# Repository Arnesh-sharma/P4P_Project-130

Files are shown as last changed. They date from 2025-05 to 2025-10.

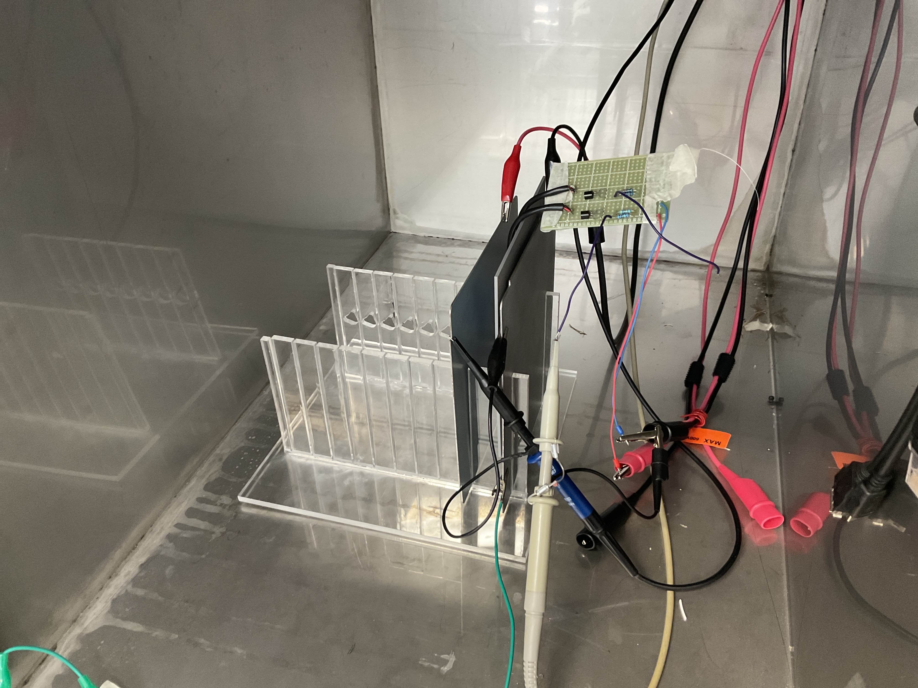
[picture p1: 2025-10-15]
Testing Data/For Report/FETs/FET_Vero.jpg

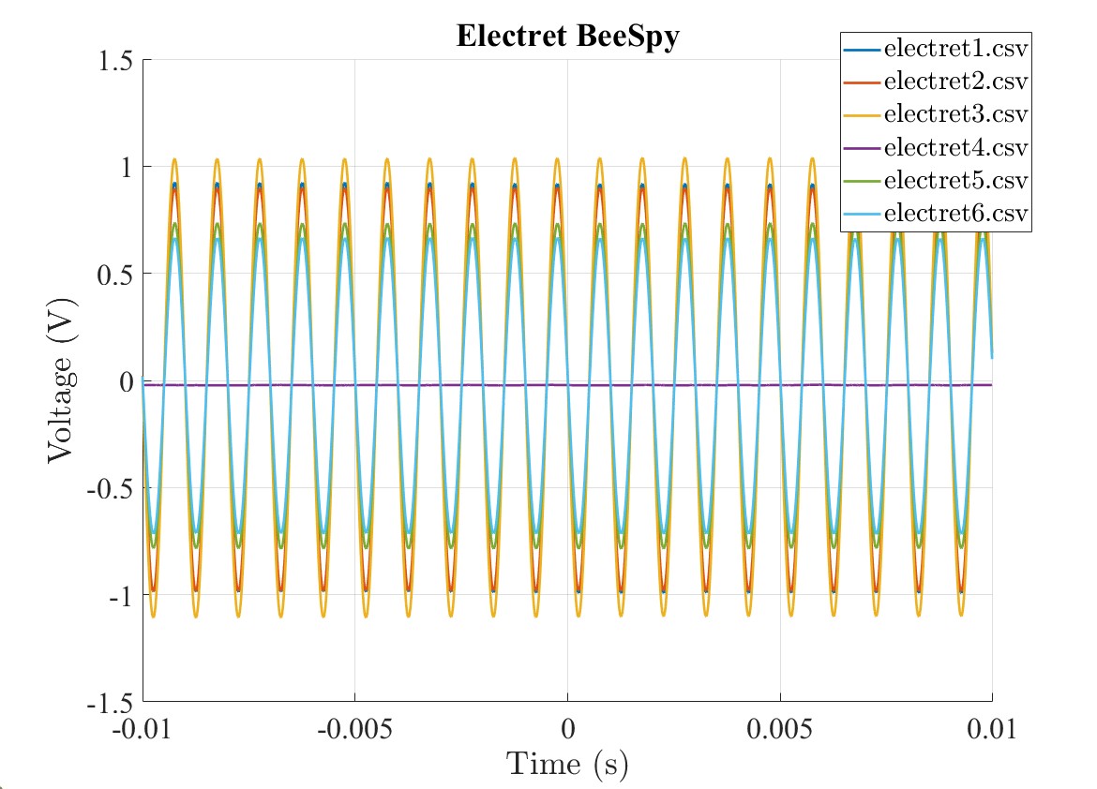
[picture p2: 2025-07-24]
Testing Data/25_07_25/BeeSpy_Electret_Sensors/untitled.jpg

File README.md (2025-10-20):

# Project 130: Motion Detection of Bees Using Electrostatic Sensors
#### Researchers: Jayti Pattni & Arnesh Sharma
---

## Project Details

This project involved designing and implementing a novel electrostatic sensor to detect the motion of bees within a hive. This Compendium holds all the 
relevant files, schematics, data, and code used in the prototyping and testing of the various sensors.

---

## Folder Structure

### `Capsense_stuff/Cap_Sense.cydsn`
This folder holds the code and the project files for using the Capacitive Sensing module in the PSoC 5.  

### `CoreXY`
This folder contains code and CAD files for the custom CoreXY used for the demo and calibration for this project. 

### `Experimental_cap_sense`
This folder contains the code and project files for another PSoC-based capacitive sensing technique using the relaxation oscillator. It also includes the LT_Spice folder, this folder consists of LT Spice files used to simulate some of the sensors, such as the relaxation oscillator, for this project. 

### `Notes_&_Deliverables`
Contains notes from meetings and experimental ideas

### `Matlab Code`
This folder contains the files to plot the readings received from Putty, scope data, and psoc plotters for the diode, Capacitive sensor configuration, FFT analysis.

This also inclu demonstration matlab code for the capacitive sensor with instrumentation amplifier that shows a heat map of intensity and gives a live fft.

### `BeeSpy Arduino Code`
This folder contains arduino code to read from the BeeSpy Sensors.

### `PCBs`
This folder contains the PCB projects for the sensors used for this project. It included: 
- Crystal oscillator circuit
- Electrostatic induction sensor circuit
- Instrumentation Amplifier PCB
- A PCB with multiple circuits that connect to the capacitive sensor

### `Photos`
This folder includes the photos of the test rig and the Faraday cage. Also contains are folder 'photos of sensors' which consists of the photos of the sensors developed throughout this project. 

### `Testing Data`
This folder contains the files of the data collected from laboratory testing, with a few images on how the tests were set up. 

### `CST Files`
This folder contains CST Studio files used to simulate and test the capacitive sensors. 

### `laser_cutting_files`
This folder contains the laser-cut files for the acrylic test rig. 

---

## Future Work

This compendium can be used to build on the research done throughout this project. Some further work should be done on the sensing of the motion of bees.
Including: 
- Working on revisions of the capacitive sensors, such as size and shape/geometry
- Working on improving the existing sensors that were developed during this project
- Implementing more PCBs to accommodate the finer capacitive sensor matrix
- Research into ITO-based sensors
- Also development of Hemispherical sensors
---

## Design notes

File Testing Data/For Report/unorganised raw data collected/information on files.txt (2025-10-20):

# Waveform (WFM) Data File Information
## Electret BeeSpy Sensor Tests

### Electret Plate Test - 3.3V
WFM01: E.CH1 #1
WFM02: E.CH1 #2
WFM03: E.CH2 #1
WFM04: E.CH2 #2
WFM05: E.CH3 #1
WFM06: E.CH3 #2
WFM07: E.CH4 #1
WFM08: E.CH4 #2
WFM09: E.CH5 #1
WFM10: E.CH5 #2
WFM11: E.CH6 #1
WFM12: E.CH6 #2

### Electret Point Test
WFM13: E.CH1 #1
WFM14: E.CH1 #2
WFM15: E.CH2 #1
WFM16: E.CH2 #2
WFM17: E.CH3 #1
WFM18: E.CH3 #2
WFM19: E.CH4 #1
WFM20: E.CH4 #2
WFM21: E.CH5 #1
WFM22: E.CH5 #2
WFM23: E.CH6 #1
WFM24: E.CH6 #2 

## JFET BeeSpy 5 Sensor Tests

### JFET BeeSpy Channel Mapping:
#1 -> Sensor 0
#2 -> Sensor 1
#3 -> Sensor 3
#4 -> Sensor 2
#5 -> Sensor 4
#6 -> Sensor 5

### JFET Point Test - 5.0V - Centre
WFM25: JB.CH1 #1 (Sensor 0)
WFM26: JB.CH1 #2 (Sensor 0)
WFM27: JB.CH2 #1 (Sensor 1)
WFM28: JB.CH2 #2 (Sensor 1)
WFM29: JB.CH3 #1 (Sensor 3)
WFM30: JB.CH3 #2 (Sensor 3)
WFM31: JB.CH4 #1 (Sensor 2)
WFM32: JB.CH4 #2 (Sensor 2)
WFM33: JB.CH5 #1 (Sensor 4)
WFM34: JB.CH5 #2 (Sensor 4)
WFM35: JB.CH6 #1 (Sensor 5)
WFM36: JB.CH6 #2 (Sensor 5)

### JFET Plate Test - Centre
WFM37: JBJ.CH1 #1 (Sensor 0)
WFM38: JBJ.CH1 #2 (Sensor 0)
WFM39: J.CH2 #1 (Sensor 1)
WFM40: J.CH2 #2 (Sensor 1)
WFM41: J.CH3 #1 (Sensor 3)
WFM42: J.CH3 #2 (Sensor 3)
WFM43: J.CH4 #1 (Sensor 2)
WFM44: J.CH4 #2 (Sensor 2)
WFM45: J.CH5 #1 (Sensor 4)
WFM46: J.CH5 #2 (Sensor 4)
WFM47: J.CH6 #1 (Sensor 5)
WFM48: J.CH6 #2 (Sensor 5)

## Other Sensor Prototype Tests
### 25 Capacitive Sensor with Instrumentation Amplifier, parallel plate test, only one channel was tested (bottom right corner)
WFM49: 25IA #1 (invalid)
WFM50: 25IA #2
WFM51: 25IA #3

### JFET Vero Board Prototype
WFM52: FET Vero Self biasing #CH1
WFM53: FET Vero Self biasing #CH2

### Capacitive Sensor Array (25-Sensor Board) Tests run in the Beehive
(25IA Sensor board test)
WFM54: CH1 (Bottom Left) & CH2 (Top Right)
WFM55: CH1 (Bottom Left) & CH2 (Bottom Right)
WFM56: CH1 (Bottom Right) & CH2 (Centre) 
       * NOTE: CH1 has offset at -600mV
WFM57: CH1 (Bottom Right) & CH2 (Centre)
WFM59: CH1 (Centre) & CH2 (Top Left)
WFM60: CH1 (Centre) & CH2 (Bottom Left)

### Capacitive Sensor Array (25-Sensor Board) Tests run in lab
### Point test, the 1cm copper plate was placed in the centre of the board
WFM58: Centre
WFM61: BL (Bottom Left)
WFM62: TL (Top Left)
WFM63: TR (Top Right)
WFM64: BR (Bottom Right)

# Plate test, only the bottom 3 sensor data was taken 
WFM65: Bottom Right right CH8
WFM66: Bottom right CH2
WFM67: Bottom centre CH3

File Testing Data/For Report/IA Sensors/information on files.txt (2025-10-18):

WFM50 - Bottom right corner sensor | uniform plate
WFM51 - Bottom right corner sensor | uniform plate

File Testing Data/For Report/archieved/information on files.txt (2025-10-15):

Each sensor data in placed into files, each containing raw data, images of sensor and testing setup.
The distance for sensor placement and the positive capacitor is (around 1.5cm)

WFM01 - Beespy FET CH1 10Hz-200kHz
WFM02 - Beespy FET CH1 10Hz-10kHz

WFM03 - Beespy FET CH2 10Hz-10kHz
WFM04 - Beespy FET CH2 10Hz-200kHz

WFM05 - Beespy FET CH3 10Hz-200kHz
WFM06 - Beespy FET CH3 10Hz-10kHz

WFM07 - Beespy FET CH4 10Hz-10kHz
WFM08 - Beespy FET CH4 10Hz-200kHz

WFM09 - Beespy FET CH5 10Hz-200kHz
WFM10 - Beespy FET CH5 10Hz-10kHz

WFM11 - Beespy FET CH6 10Hz-10kHz
WFM12 - Beespy FET CH6 10Hz-200kHz

WFM13 - Beespy Electret CH1 10Hz-10kHz
WFM14 - Beespy Electret CH2 10Hz-10kHz
WFM15 - Beespy Electret CH3 10Hz-10kHz
WFM16 - Beespy Electret CH4 10Hz-10kHz
WFM17 - Beespy Electret CH5 10Hz-10kHz
WFM18 - Beespy Electret CH6 10Hz-10kHz

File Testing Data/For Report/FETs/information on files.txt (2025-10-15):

WFM01 - FET CH1 10Hz - 10kHz
WFM02 - FET CH1 10Hz - 200kHz

WFM03 - FET CH2 10Hz - 10kHz 
WFM04 - FET CH2 10Hz - 200kHz

WFM05 - FET PCB CH1 10Hz - 10kHz
WFM06 - FET PCB CH1 10Hz - 200kHz

WFM07 - FET PCB CH2 10Hz - 10kHz
WFM08 - FET PCB CH2 10Hz - 200kHz

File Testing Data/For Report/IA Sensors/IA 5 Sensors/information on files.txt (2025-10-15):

WFM03 - IA CH1 10Meg 10Hz - 10kHz
WFM04 - IA CH2 1Meg 1uF Capacitors Shorted 10Hz - 10kHz
WFM05 - IA CH3 1Meg 10Hz - 10kHz
WFM06 - IA CH4 1Meg 10Hz - 10kHz
WFM07 - IA CH5 1Meg 10Hz - 10kHz

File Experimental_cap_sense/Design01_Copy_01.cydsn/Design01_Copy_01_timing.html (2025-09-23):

# Static Timing Analysis

Project : | Design01_Copy_01
Build Time : | 08/12/25 19:21:26
Device : | CY8C5888LTI-LP097
Temperature : | -40C - 85/125C
VDDA : | 5.00
VDDABUF : | 5.00
VDDD : | 5.00
VDDIO0 : | 5.00
VDDIO1 : | 5.00
VDDIO2 : | 5.00
VDDIO3 : | 5.00
VUSB : | 5.00
Voltage : | 5.0

Expand All | Collapse All | Show All Paths | Hide All Paths

+ Timing Violation Section

No Timing Violations

+ Clock Summary Section

Clock | Domain | Nominal Frequency | Required Frequency | Maximum Frequency | Violation
CyILO | CyILO | 1.000 kHz | 1.000 kHz | N/A
CyIMO | CyIMO | 3.000 MHz | 3.000 MHz | N/A
CyMASTER_CLK | CyMASTER_CLK | 24.000 MHz | 24.000 MHz | N/A
CyBUS_CLK | CyMASTER_CLK | 24.000 MHz | 24.000 MHz | N/A
CyPLL_OUT | CyPLL_OUT | 24.000 MHz | 24.000 MHz | N/A

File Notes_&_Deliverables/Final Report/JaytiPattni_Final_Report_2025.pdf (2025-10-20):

Motion detection of Bees Using Electrostatic Sensors

Jayti Pattni

RESEARCH PROJECT REPORT

Co-worker: Arnesh Sharma

Supervisor: Dr Nitish Patel

Department of Electrical, Computer and Software Engineering The University of Auckland

October 2025

ii

ABSTRACT

Honeybees play a vital role in global ecosystems and agriculture, yet current methods for monitoring their activity are often invasive or unreliable. While non-invasive electrostatic field (ESF) sensing is a promising alternative, existing systems suffer from high inter-sensor variability, limiting their accuracy. This project aimed to solve this limitation by designing and evaluating novel sensor configurations. We developed and benchmarked several prototypes, including a self-biasing JFET sensor and a capacitive sensor array with an instrumentation amplifier, against the baseline BeeSpy system. The key finding is that the new designs, particularly the instrumentation amplifier-based capacitive sensor, exhibit exceptional inter-sensor consistency, effectively overcoming the primary weakness of current hardware. Furthermore, the capacitive array demonstrated the ability to resolve the spatial location of a signal. These results validate a significantly more reliable and scalable sensor topology, representing a crucial step towards robust, low-cost systems for large-scale hive health assessment and behavioural analysis.

iii

DECLARATION

Student

I hereby declare that:

### 1. This report is the result of the final year project work carried out by my project

partner (see cover page) and me under the guidance of our supervisor (see cover page) in the 2025 academic year at the Department of Electrical, Computer and Software Engineering, Faculty of Engineering, University of Auckland.

2. This report is not the outcome of work done previously.

### 3. This report is not the outcome of work done in collaboration, except that with a

potential project sponsor (if any) as stated in the text.

4. This report is not the same as any report, thesis, conference article, journal paper, or any other publication or unpublished work in any format.

In the case of a continuing project, please state clearly what has been developed during the project and what was available from previous year(s):

Signature: Jayti Pattni

Date: 4/10/2025

iv

## Table of Contents

RESEARCH PROJECT REPORT | 1
DECLARATION | 3
Acknowledgements | 5
Glossary of Terms | 6
Abbreviations | 6

### 1. Introduction | 1

### 2. Literature Review | 1

### 2.2. Electrostatic Sensor Technology | 2

### 2.2.1. Principles of Electrostatic Sensing | 2

### 2.2.2. KCL Electrode Sensor | 3

### 2.3. Current State-of-the-Art: The BeeSpy System | 3

### 2.4. Capacitive Sensor Technology | 5

### 3. Sensor Design and Prototyping | 6

### 3.1. Baseline Sensors for Performance Comparison | 6

### 3.2. JFET-Based Sensors | 7

### 3.3. Electrostatic Induction-Based Sensor | 8

### 3.4. Capacitive Sensing with an Instrumentation Amplifier | 9

### 3.5. Direct Sensing with PSOC Integrated CapSense Module | 10

### 3.6. Relaxation Oscillator-Based Sensing Method | 11

### 3.7. Crystal Oscillator Design | 12

### 4. Experimental Setup | 13

### 4.1. Bee and Waggle Simulation | 13

### 4.2. Controlled Testing Environment and Noise Control | 14

### 4.3. Data Acquisition | 14

### 4.4. Preliminary In-Hive Set Up and Testing | 14

### 5. Results | 15

v

v

Acknowledgements

This project would not have been possible without the support and guidance of those who contributed their time, expertise, and encouragement throughout its development.
I would like to thank my project partner, Arnesh Sharma, for his dedication and hard work put into this project.

I am deeply grateful to our supervisor, Dr Nitish Patel, for his mentorship, technical guidance, and ongoing support. His expertise in sensor design and signal processing helped guide the project's direction and ensured its scientific rigour.

I would also like to thank our co-supervisor, Dr David Cumin. He was instrumental in giving us access to the BeeSpy boards and was continuously contacting the BeeSpy team in Germany.

Lastly, I would like to thank my family and friends for their patience and encouragement throughout this research journey, especially during the long hours of experimentation and report writing.

vi

Glossary of Terms

Electrostatic Field | The field produced around a stationary charged object.
Triboelectric Effect | Describes the transfer of electric charge from one object to
| another when they make contact or rub against each other.

Abbreviations

Electrostatic Fields | ESF

1

### 1. Introduction

Honeybees play a vital role in global ecosystems as primary pollinators, contributing significantly to biodiversity and agricultural productivity. The health of bee colonies is therefore a critical indicator of environmental conditions, reflecting factors such as disease, pesticide exposure, and food availability. Monitoring hive activity provides valuable insights into colony health and wider ecological stability. However, current monitoring techniques are often invasive, relying on visual inspection or optical methods that disturb the colony and provide limited temporal resolution. This highlights the need for non-invasive, continuous monitoring systems capable of detecting subtle behavioural and environmental changes within the hive.
Bees generate small electrostatic fields during flight and social interactions due to the triboelectric effect, which is an accumulation of charge through friction between body parts and with the surrounding air. Recent studies have shown that these fields are not incidental but play a communicative role in bee behaviour, particularly in the waggle dance used to convey foraging information. Harnessing this phenomenon offers a promising pathway for contactless sensing of bee activity. Unlike optical systems, electrostatic field (ESF) sensors can operate in complete darkness and be integrated directly into standard hive structures, making them ideal for scalable, non-disruptive monitoring.
However, existing electrostatic sensing systems, such as the BeeSpy platform, face key challenges that limit their reliability and deployment potential. These include low sensitivity to weak field variations, high inter-sensor variability, and vulnerability to environmental noise, leading to inconsistent data and high false-negative rates in detecting waggle dance activity. Addressing these limitations is critical for advancing the viability of electrostatic sensing as a tool for long-term behavioural monitoring.
This project investigates improved electrostatic sensing methods for detecting bee motion by leveraging the charge generated during flight and social behaviour. The objective is to design, prototype, and evaluate novel sensor configurations, specifically capacitive sensing, that address the shortcomings of existing ESF systems. The report begins with a literature review outlining the biological basis of bee electrostatics and current state-of-the-art sensing technologies. It then presents the systematic design and development of new sensor prototypes, followed by a controlled experimental evaluation of their performance both in laboratory and preliminary in-hive environments. The report concludes with a discussion of the results, key limitations, and recommendations for future work toward a scalable, non-invasive monitoring system for honeybee behaviour.

### 2. Literature Review

Despite the clear benefits of monitoring hive health, traditional inspection methods are intrusive, stress the colony, and prevent frequent check-ups. This has created a critical need for non-intrusive sensing methods. This review provides an overview of the current state of research on electrostatic sensing, a promising approach for detecting bee motion. It first explores the foundational research linking bees to electrostatic fields and examines the biological significance of key communication signals, like the waggle dance, that indicate hive health. It then evaluates the state-of-the-art sensor technology, focusing on the performance and documented limitations of existing in-hive systems to identify the specific technological gap this project aims to address.

2

### 2.1. Electrostatic Fields in Bee Ecology

While it's well known that bees use chemical cues, such as pheromones, and physical movement for communication, research over the last decade has revealed that electrostatic fields (ESFs) play a significant role in social interactions inside the hive.
Honeybees and bumblebees naturally accumulate a positive electrostatic charge during flight and through friction with body parts due to the triboelectric effect. Research has shown that these electric fields are not merely an incidental byproduct of their activity but play a functional role in their ecology. Bees can detect and learn from weak electric fields, which are used in foraging to discriminate between rewarding and unrewarding flowers [1].
Crucially for in-hive monitoring, these electric fields are also emitted during key social behaviours. It has been demonstrated that bees emit both constant and modulated electric fields while walking, and significantly, during the waggle dance. Mechanoreceptors in the antennae have been identified as sensitive to these electric stimuli, providing a neurological basis for electroreception [2]. Further research on bumblebees offered compelling evidence that sensory hairs on the bees' bodies are a primary site of electroreception [3]. It was demonstrated that external electric fields cause these hairs to deflect, which in turn elicits neural activity, whereas the antennae did not exhibit a similar electrophysiological response [3].
The biological significance of monitoring these dance-related fields is profound. The waggle dance is a sophisticated form of symbolic communication used by honeybees to recruit nestmates to a profitable resource [4]. First decoded by Karl von Frisch, this "dance language" conveys precise vector information: the angle of the dance's central 'waggle run' on the vertical comb, relative to gravity, indicates the direction of the resource relative to the sun, while the duration of this run is directly proportional to the distance of the resource from the hive [4]. The enthusiasm and speed of the dance can also communicate the quality or profitability of the source, influencing how many new foragers are recruited.
The waggle dance, therefore, acts as a real-time report from the colony's most successful foragers. By eavesdropping on these signals, researchers can map foraging activity, understand landscape use, and assess the health of the surrounding ecosystem [5]. Crucially, the dance is also a sensitive indicator of colony health. It is well-documented that social signals, including the waggle dance, are compromised by stressors such as exposure to insecticides, which can impair a bee's ability to perform or interpret the dance correctly [5]. Monitoring the ESF signals associated with the waggle dance thus provides a powerful, non-invasive window into not only hive behaviour but also the overall health of the colony and its environment.

### 2.2. Electrostatic Sensor Technology

### 2.2.1. Principles of Electrostatic Sensing

The principle behind electrostatics is in electrostatic induction and charge transfer, which describe how nearby electric charges influence conductive materials. When a charged object moves close to a sensor’s electrodes, it causes a disturbance in the electric field. This variation in the electric field induces charges within the electrode, resulting in a measurable current or voltage. Electrostatic sensors can be broadly classified based on whether the sensing electrode is insulated or exposed [6]. When the electrode is exposed, both electrostatic induction and charge transfer occur, in which electrons move between the object and the electrode upon contact. With insulated electrodes, the sensor responds only to electrostatic induction, where the electric field of the nearby object induces a charge on the electrode. This makes it ideal for

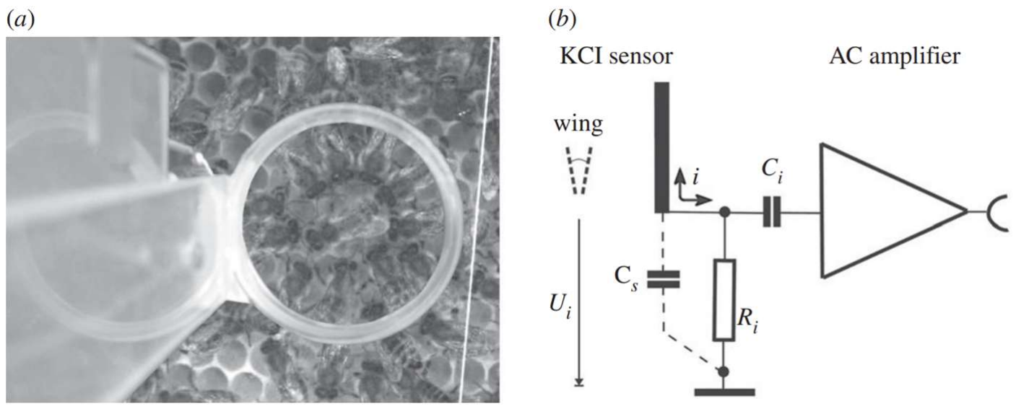
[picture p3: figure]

3

non-invasive sensing applications.

Table 1 - Comparison of electrostatic sensors and capacitive sensors
Feature | Electrostatic Sensors | Capacitive Sensors
Field Source | External charged object (passive sensing) | Sensor generates an electric field (active sensing)
Operating Principle | Electrostatic induction or charge transfer | Capacitance change due to object proximity or permittivity
Sensing Mechanism | Measures the electric field variation caused by a moving charged object | Measures the change in capacitance due to a change in distance or dielectric

The sensing principle of electrostatic sensors can also be explained like that of capacitive sensors, where the object being detected serves as one plate of the capacitor, and the other plate is the electrode itself. Therefore, any movement of the charged object changes the distance between the plates and, consequently, the value of the capacitance. As shown in Table 1, unlike capacitive sensors, electrostatic sensors generate the field through the movement of the object, causing fluctuations in the electric field [6].

### 2.2.2. KCL Electrode Sensor

The detection of these weak biological electric fields requires sensitive, non-contact sensors. An early implementation involved a potassium chloride (KCl) electrode [2]. This transparent sensor was positioned near the bee, forming a capacitive coupling that allowed the time-varying signals from the bee's movement to be measured by an AC amplifier without direct contact.

Figure 1-A simplified circuit diagram of the KCL electrode sensor, illustrating the capacitive coupling (Cs) between the bee (wing) and the sensor electrode [2].
While effective for targeted laboratory studies, this approach is not easily scalable for continuous, large-area monitoring inside a standard beehive.

### 2.3. Current State-of-the-Art: The BeeSpy System

A novel, non-invasive system for monitoring the health and social communication of

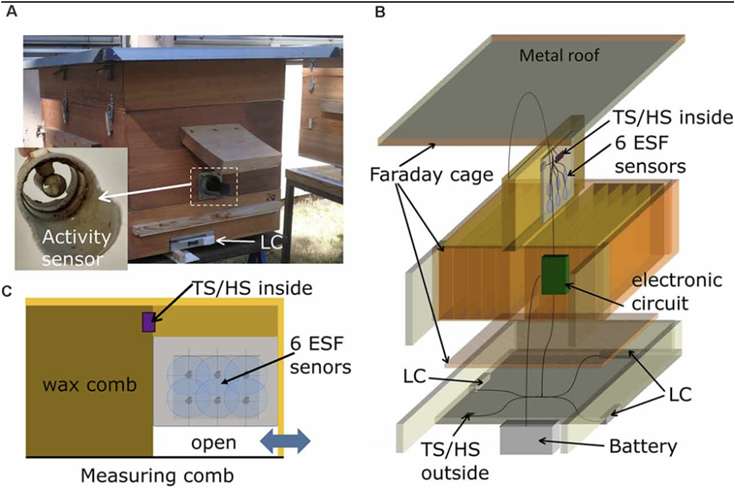
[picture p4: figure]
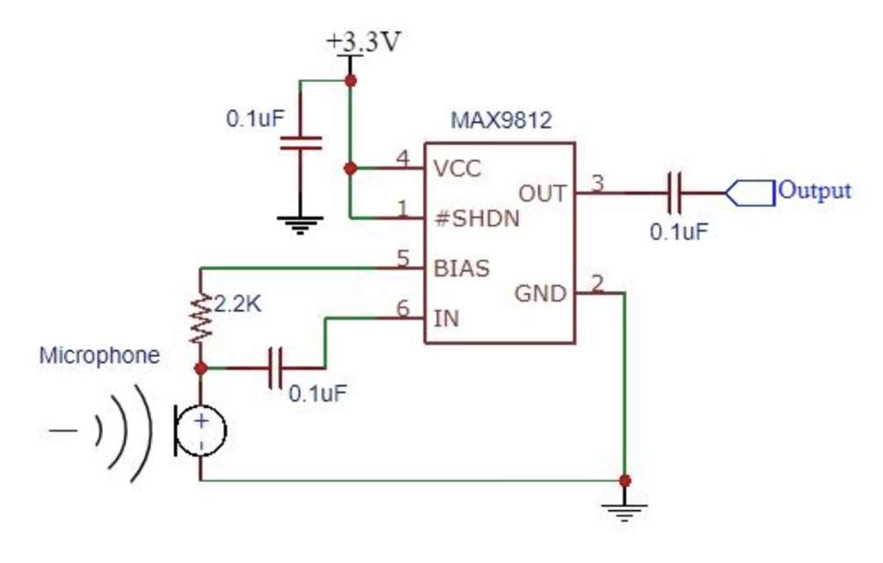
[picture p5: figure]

4

honeybee colonies has been developed based on the principle of electrostatic field (ESF) recording [8]. This "Electronic Bee Spy" utilises a set of specialised sensors, created from modified capacitive microphones, installed within a standard beehive that is shielded to act as a Faraday cage. The system continuously records the characteristic ESF patterns generated by the bees' movements, which are caused by friction between body parts and interactions within the crowded hive rather than just flight-related charges. By analysing the unique frequency profiles of these signals, the system can automatically identify and classify key social behaviours, including waggle-dance-related signals (WRS), short-pulse-related signals (SRS), and fanning-related signals (FRS).

Figure 2-Sensing setup of BeeSpy in a beehive [8]
The system uses a standard wooden hive that is transformed into a Faraday cage to shield against external electrical noise. As shown in Figure 2 above, one of the frames is for the measuring devices. The backside of the sensor frame is shielded with a grounded mesh, so the sensors only detect fields from the open side that faces the bee. The entrance and exit of the hive are equipped with a capacitive sensor-based counter to record bee traffic [8]. Figure 2 (c) shows the measuring comb frame with six ESF sensor units arranged on the comb surface. This arrangement concentrates the region near the hive entrance, referred to as the “dance floor”, where waggle dances are most frequent [8].

Figure 3-Electrostatic field sensor circuit diagram [8]
The original ‘BeeSpy’ electrostatic sensors themselves are based on electret microphone circuits that have been modified to detect static field changes rather than sound. An electret is a material with a permanent, built-in electric charge, much like a permanent magnet holds a magnetic field. In a standard microphone, this charged material creates a stable electric field, which is used to sense the movement of a sound-sensitive diaphragm.
The system uses six electret microphone capsules (CJMCU-9812 MAX9812L, capacitive microphones with a microphone preamplifier board) mounted on the custom frame, arranged in two rows of three sensors each. To convert these microphones into ESF sensors, their normal sound-responsive membranes were removed, exposing the internal Field-Effect Transistor (FET) gate that can pick up ambient electric field fluctuations. With the diaphragm

5

gone, the microphone’s FET essentially acts as a sensitive antenna for electrostatic charges moving nearby, and it is no longer responsive to air pressure.
While the ‘BeeSpy’ system successfully proved the concept of in-hive electrostatic monitoring, its validation studies revealed critical performance limitations. The most critical weakness lies in the signal processing algorithm's high false-negative rate for detecting waggle dances. The authors report that while 85% of the signals identified as dances were correct, the system failed to detect 84% of the total waggle runs that were visually confirmed [8]. This inaccuracy is attributed to "biological noise" from other bees and the difficulty in distinguishing the waggle dance from other social behaviours, like grooming dances, that produce electrostatic fields (ESF) in a similar frequency range.
Furthermore, the system was documented with several practical and technological limitations, including:
- The hardware relied on "hundreds of hand-soldered connections that caused instabilities and errors" [8]
- All signal classification was performed "offline" rather than in real-time on the device, and the current analysis does not use any "machine-learning approaches," which the authors identify as an "obvious goal for the future" [8]
- There is an interpretive gap, as the authors admit it has "not been possible, yet, to relate these ESF signals, specifically Short-Pulse-Related Signals, to specific behaviours" [8]
- The system required weekly battery changes, making it impractical for long-term, low-intervention studies [8]
These documented shortcomings, particularly the high false-negative rate and sensor variability, highlight a clear technological gap. While the principle of electrostatic monitoring is sound, the hardware implementation is not yet reliable enough for robust scientific use.
The research presented in this report is positioned to address this technological gap directly. Through a collaboration with the original BeeSpy development team, this project utilises the same electret-based sensor system. A primary objective of this report is to provide a more detailed, independent analysis of this sensor's effectiveness at detecting specific electrostatic frequencies, which will be presented in the Results section.
Furthermore, this collaboration has provided access to a next-generation, unreleased version of the system, the BeeSpy 5, which was delivered in June. This new hardware is intended to resolve the documented performance and practical limitations of the original electret sensor. As no published literature yet exists for the BeeSpy 5, this report will present the first independent performance characterisation and experimental results for this new sensor. This work, therefore, bridges the gap between the published limitations of the first-generation BeeSpy and the empirical validation of its successor.

### 2.4. Capacitive Sensor Technology

Capacitive sensors operate on the principle of detecting changes in capacitance caused by the presence or motion of nearby objects. Unlike traditional electrostatic field (ESF) sensors, which passively detect naturally occurring charges from bees, capacitive sensors actively generate an electric field and detect changes in capacitance caused by the movement of nearby objects or changes in dielectric properties.
At its core, capacitive sensors can be modelled as a simple capacitor, where the equation

6

defines the capacitance C:
C=εA/d
Where ε is the permittivity of the medium between electrodes, A is the surface area of the electrodes, and d is the distance between them. When a enters the sensing zone, it either becomes part of the dielectric or acts as a floating electrode, which changes the permittivity or distance and thus the capacitance. Since the value of the capacitor is directly related to its size, a small capacitor means high noise susceptibility; therefore, capacitive sensors should be as large as possible [7].
In the current sensor design, the electrodes are primarily sensitive to electric fields coming from one direction. This means that some parts of the electric field created by a moving bee may go undetected, especially if the bee flies at an angle or from the side. By arranging the sensors in a curved or hemispherical shape, it becomes possible to detect electric fields from more directions [8]. This could provide extra information, such as the direction the bee is moving. The existing setup is mainly designed to detect whether a bee with a charge is present. However, by increasing the number of sensors in an array and optimising their placement, we can gather more detailed signals from the same area.
In summary, capacitive sensors offer a promising and complementary alternative to ESF sensors for bee monitoring. They can overcome many of the limitations seen in current electrostatic implementations, such as inconsistent sensitivity and limited spatial coverage. Their flexibility in design and integration also makes them ideal candidates for widespread deployment in realistic beekeeping conditions.

### 3. Sensor Design and Prototyping

This section outlines the design and prototyping process undertaken to develop a more reliable electrostatic field (ESF) sensor for detecting honeybee motion. The primary objective was to address the documented performance issues of existing sensors, namely inter-sensor variability. The process began by establishing the performance of baseline sensors from the BeeSpy project, followed by an iterative development of several new designs: three JFET-based configurations to improve stability, a novel capacitive sensor with an instrumentation amplifier for enhanced consistency and spatial resolution, and finally, an exploration of experimental relaxation and crystal oscillator circuits.

### 3.1. Baseline Sensors for Performance Comparison

To quantitatively assess the performance of any new design, it was essential first to establish a performance benchmark. Two existing sensor designs from the BeeSpy project were utilised for this purpose: the original electret microphone BeeSpy and the BeeSpy 5 JFET sensors (as of June 2025).

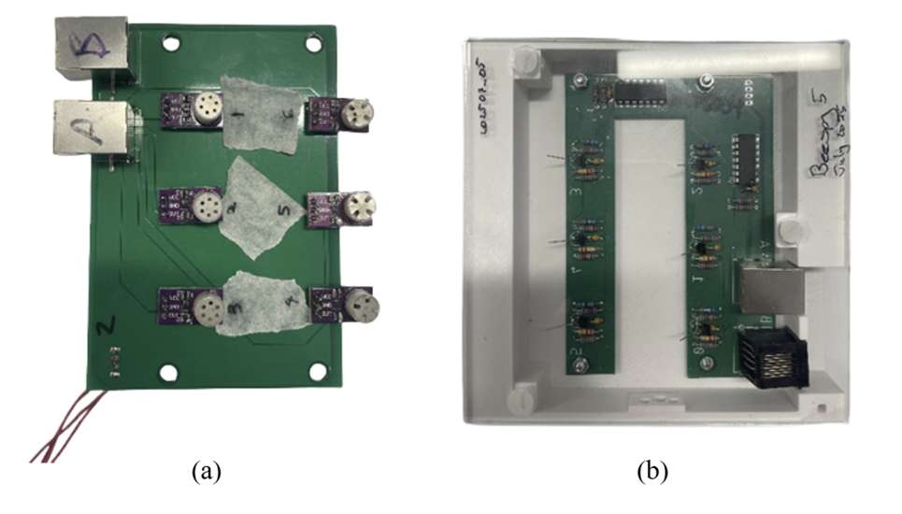
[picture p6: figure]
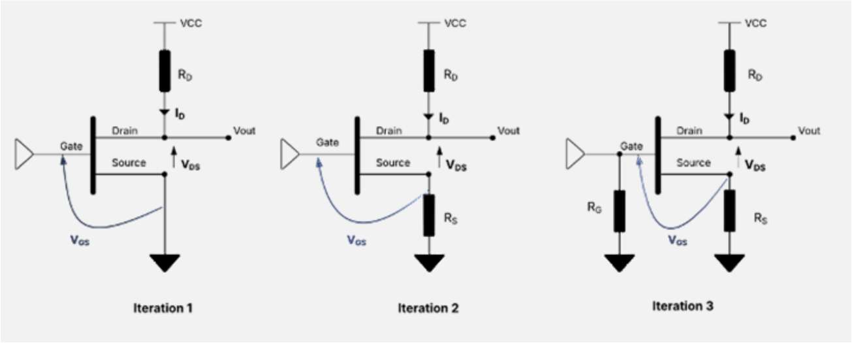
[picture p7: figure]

7

Figure 4-Electret and JFET BeeSpy sensors
The electret microphone BeeSpy sensor, used in the original BeeSpy system, consists of modified electret microphones with their diaphragms removed. This modification exposes the internal JFET to external electric fields. An array of these sensors served as the primary baseline to evaluate inter-sensor consistency. This second-generation sensor is a JFET-based design configured as a common source with a floating gate acting as the sensing probe. Both baselines were tested to quantify the variability that this project aims to solve.

### 3.2. JFET-Based Sensors

Junction Field-Effect Transistors (JFETs) were selected as a promising alternative to electrets due to their inherent high input impedance, which makes them well-suited for detecting the minimal changes in electric fields generated by bee movements. A JFET acts as an electronic valve controlling current flow from the drain to the source. The amount of current allowed through this channel is controlled by the voltage applied to a third terminal, the gate. Because the gate draws negligible current, the JFET presents a very high input impedance. This characteristic makes the gate extremely sensitive to small voltage changes. In this sensing application, the weak electric field produced by a nearby bee directly influences the voltage on the JFET's gate. This minute voltage variation then modulates a significantly larger current flowing through the JFET's channel. By measuring the voltage developed across a resistor (R) as these current flows, an amplified signal corresponding to the bee's electric field is obtained.
To address potential instability and noise issues associated with high-impedance inputs, a systematic and iterative design process using the BF245A N-channel JFET was employed. Three circuit configurations were prototyped and evaluated, as shown in Figure 5.

Figure 5-JFET sensor configurations
The first design (Figure 5, Iteration 1) configured the JFET in a basic common-source topology, where the JFET's gate is left unterminated, or "floating," to act as a sensitive antenna to external electric fields. When an external electric field is applied, it alters the voltage at the gate, which in turn affects the amount of current flowing from the drain to the

8

source. This change can be seen as a voltage change across the resistor. While early tests showed this configuration produced a strong response, the floating gate provided no stable DC reference. This made the sensor highly susceptible to DC drift from ambient charge accumulation and prone to picking up low-frequency environmental noise, rendering it unreliable for stable measurements.
The second iteration of the JFET sensor includes a resistor between the source terminal and ground (R

). As the drain current increases, a voltage develops across the source resistor, which then raises the source voltage, V. This introduces negative feedback (source degeneration), which helps stabilise the transistor's operating point against variations. As the drain current increases, the voltage across R

rises, making the gate-to-source voltage V more negative, which in turn reduces the drain current. This feedback loop helps stabilise the operating point of the transistor, although the gate's voltage can still slowly drift or pick up random charge, which isn't ideal for a sensor.

The final design (Figure 5, Iteration 3) incorporated a high-value resistor (R, 10 MΩ) connecting the gate to ground. This crucial component provides a stable DC path, preventing long-term drift by referencing the gate to ground potential for DC signals. Simultaneously, the high resistance ensures that the gate remains highly sensitive to the AC electric fields generated by the bee's motion.

Among the three designs, this self-biasing configuration provided the best observed balance between sensitivity, operational stability, and repeatability during the prototyping phase. Consequently, it was further developed by the BeeSpy team on a dedicated Printed Circuit Board (PCB). However, a different JFET, the 2SK596S, was used, and further amplification of the signal was applied.

### 3.3. Electrostatic Induction-Based Sensor

An alternative sensing approach, based on electrostatic induction, was also investigated. This method was initially considered due to its inherent simplicity and passive nature, drawing inspiration from prior successful implementations by Yan et al [6].
The core concept relies on detecting the influence of a nearby moving charged object on a stationary conductor. As depicted in the general structure shown in Figure 6, the sensor is comprised of a sensing electrode that is electrically isolated by an insulator and enclosed within a grounded shield to minimise external interference. When a charged body, such as a bee, approaches the electrode, its electric field causes a rearrangement of charges on the electrode's surface through electrostatic induction. This charge movement results in a slight current. By connecting the electrode to ground via a high-value resistor (R). This induced current generates a detectable potential difference across the resistor. This mechanism is sometimes described analogously to capacitive coupling, where the object and electrode form a variable capacitor.

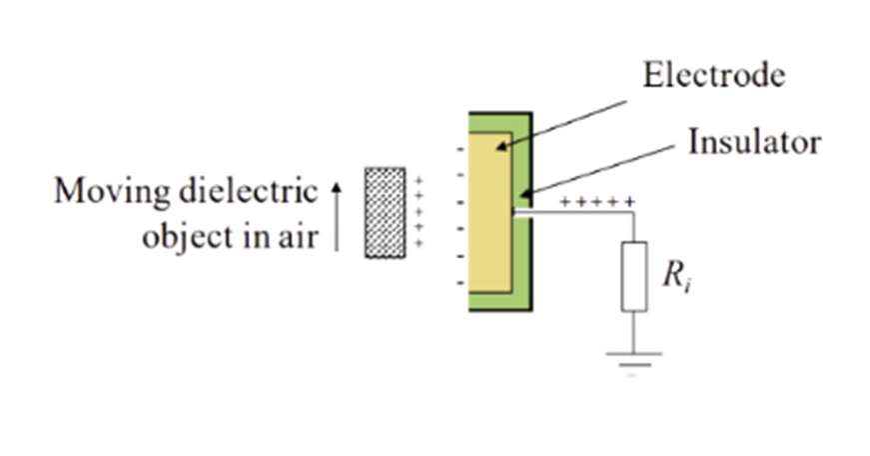
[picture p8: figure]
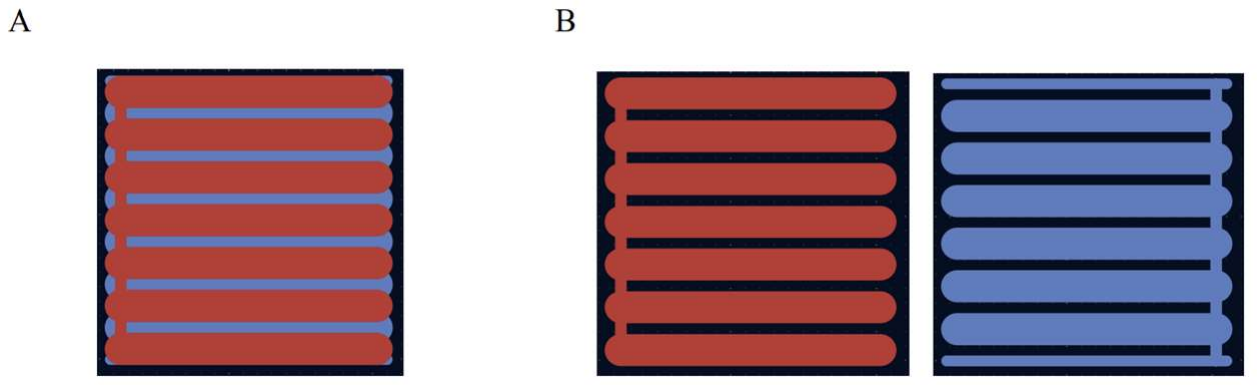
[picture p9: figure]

9

Figure 6- Sensing of a moving non-conducting object via electrostatic induction [6]
Two iterations of the induction-based sensor were constructed. The first version was a proof-of-concept that used an approximately 40 mm x 10 mm copper strip as the electrode, insulated with hot glue, and shielded with aluminium tape. A 10 MΩ resistor was connected between the electrode and ground to generate a measurable voltage drop.
The second version was made into a 3x3 PCB sensor array, designed with each electrode measuring 10 mm x 10 mm. However, a layout oversight resulted in the ground plane being restricted to the bottom PCB layer, offering incomplete shielding. Functionality was notably enhanced by adding aluminium tape to the top layer, connected to ground, which effectively created a more complete shield and likely reduced parasitic capacitance and charge accumulation on the board surface.
During initial testing of the induction sensors, the viability of this sensor remained questionable. Despite the method being validated by Yan et al. [6], further research was deemed necessary to confirm that the sensor was operating as expected and to definitively understand what was being sensed. Due to these uncertainties and the more reliable performance of other prototypes, this design was not pursued for final evaluation in this project.

### 3.4. Capacitive Sensing with an Instrumentation Amplifier

In parallel with the development of the JFET sensor designs, a capacitive sensing approach was investigated. This design utilises an INA823 precision instrumentation amplifier to measure the small voltage changes induced across a sensing plate (capacitor) by a nearby electric field. The goal of this approach was to create a highly sensitive and scalable sensor array that could provide greater spatial granularity, allowing for the tracking of bee motion across the sensor grid.

Figure 7-Proposed offset capacitive sensor. (a) Shows the overlapped sensor. (b) Shows the shift of the capacitive sensor top and bottom plates
This method leverages the principle of capacitive coupling. The sensor element itself is designed as a capacitor formed on a PCB, as depicted in Figure 7(A, B). This structure maximises the interaction area and the associated fringe electric fields extending beyond the electrode edges. The fundamental hypothesis is that the weak, time-varying electric field generated by a nearby bee perturbs these fringe fields. This perturbation alters the effective capacitance between the interdigitated plates, resulting in minute voltage fluctuations.

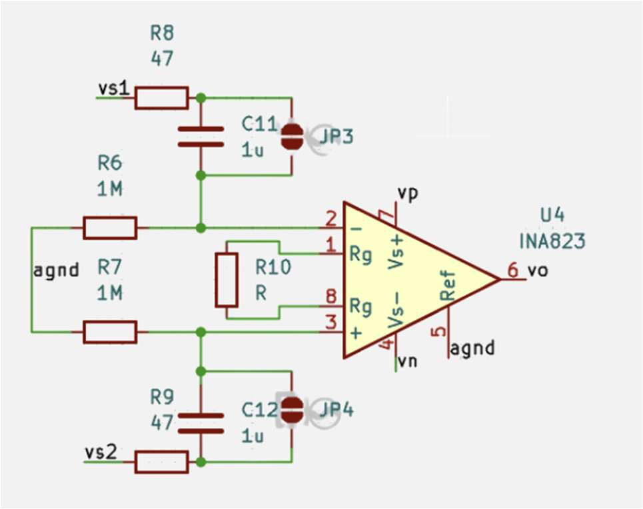
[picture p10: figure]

10

Figure 8-Instrumentation amplifier circuit diagram for Capacitive Sensor
To detect these subtle voltage changes, a high-sensitivity differential amplifier circuit based on the INA823 instrumentation amplifier was designed (Figure 8, circuit diagram). The INA823 was specifically selected for its high common-mode rejection ratio (CMRR), crucial for suppressing environmental noise like 50 Hz mains hum that affects both sensing plates similarly, and its low input bias current, which prevents loading of the high-impedance capacitive sensor plates. The differential nature of the IA amplifies the slight voltage difference between the sensor plates caused by the bee's field, while rejecting common noise sources.
Three variations of the instrumentation amplifier circuit were prototyped to explore the effects of input impedance and gain on performance:

### 1. A baseline version using 1 MΩ input resistors (R6, R7 in Figure 8)

### 2. A high-impedance version using 10 MΩ input resistors. Increasing the input

impedance was expected to enhance sensitivity to smaller signals and potentially lower the high-pass cutoff frequency of the sensor system
3. A high-gain version, configured using the gain-setting resistor (R10) for a voltage gain of approximately 200, to evaluate the maximum achievable signal amplification and assess signal-to-noise ratio limits
The capacitive sensors were fabricated as a 5x5 array on a single PCB, with each individual sensor element occupying a 10x10 mm footprint. This array format inherently supports the goal of spatial sensing. By measuring the signal strength across multiple adjacent sensors, it is possible to determine the approximate location and track the movement of a bee across the sensor surface. This contrasts significantly with the single-point measurements provided by individual JFET sensors and offers the potential for much richer behavioural data, such as mapping the specific path and orientation of a waggle dance. While potentially requiring a larger PCB footprint compared to simpler JFET circuits, the expected improvements in consistency (due to repeatable PCB manufacturing) and the added spatial information make this a highly promising approach for robust in-hive monitoring.

### 3.5. Direct Sensing with PSOC Integrated CapSense Module

An approach was aimed at leveraging the PSoC's built-in, high-sensitivity capacitive sensing (CapSense) system. This system is primarily designed for touch-sensing applications and utilises a Capacitance Sigma-Delta (CSD) measurement technique. We hypothesised that this sensitive module could be repurposed to detect minute changes in an external capacitor

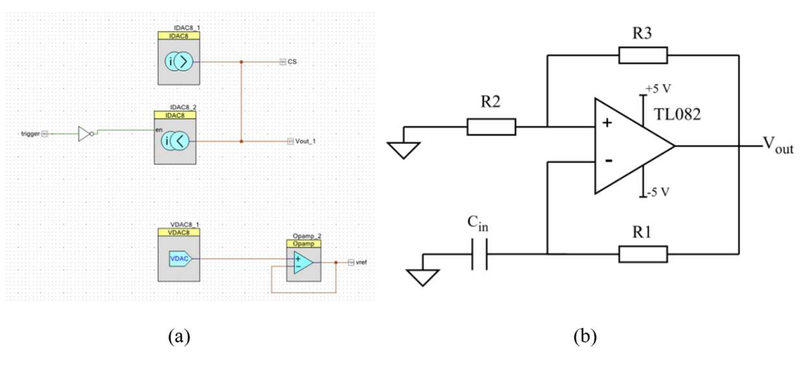
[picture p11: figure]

11

exposed to an electric field.
The experimental setup involved connecting an external capacitor, acting as a sensing plate, to one of the PSoC's CapSense input pins. The theory was that an external electrostatic field would interact with the capacitor, altering its effective capacitance. It was hoped that the CapSense module, with its fine-grained control over parameters like scan resolution and modulation current (adjustable via the EZ-I²C interface), would be able to resolve these subtle changes.
However, despite systematic tuning of the module's sensitivity, the results were inconclusive. The output signal was dominated by noise, and no discernible correlation could be established between the sensor readings and the presence or strength of the applied electric field. The inherent noise floor of the system proved too high for the subtle capacitive shifts induced by the external ESF, leading to the discontinuation of this method.

### 3.6. Relaxation Oscillator-Based Sensing Method

A novel sensing method using a relaxation oscillator circuit was also explored. The concept was to create a circuit where changes in the local electrostatic field would modulate the frequency of a relaxation oscillator. This method involved designing a relaxation oscillator circuit, as depicted in the schematic below.

Figure 9- Shows the relaxation oscillator sensor design. (a) PSoC capacitive sensing design. (b) Relaxation oscillator circuit diagram
This circuit employed a Schmitt trigger comparator (implemented with a TL082 op-amp) to create a stable charge-discharge cycle for an external sensing capacitor, Cin. The PSoC's role was to provide highly stable and configurable current sources using its internal current DACs (IDACs). One IDAC was configured to source current, charging the capacitor, while a second was configured to sink current, discharging it.
The sourcing IDAC charges Cin, causing its voltage to rise. When the voltage crosses the Schmitt trigger's upper threshold, its output flips. This state change is detected by the PSoC, which then deactivates the sourcing IDAC and activates the sinking IDAC. The capacitor then discharges until its voltage falls below the Schmitt trigger's lower threshold, at which point the process repeats. This cycle generates a continuous triangular wave with a natural frequency of around. The hypothesis was that an external electric field interacting with the capacitor's fringing field would alter its capacitance, leading to a measurable shift in the oscillator's frequency, which could be precisely captured by the PSoC's timer/counter peripherals.
However, early experimental testing revealed that the sensitivity of this prototype was insufficient for detecting the weak electric fields associated with bee movement. While the design was functional, its response was too small to be practical for this application without significant further development. This finding suggests that a different circuit topology or

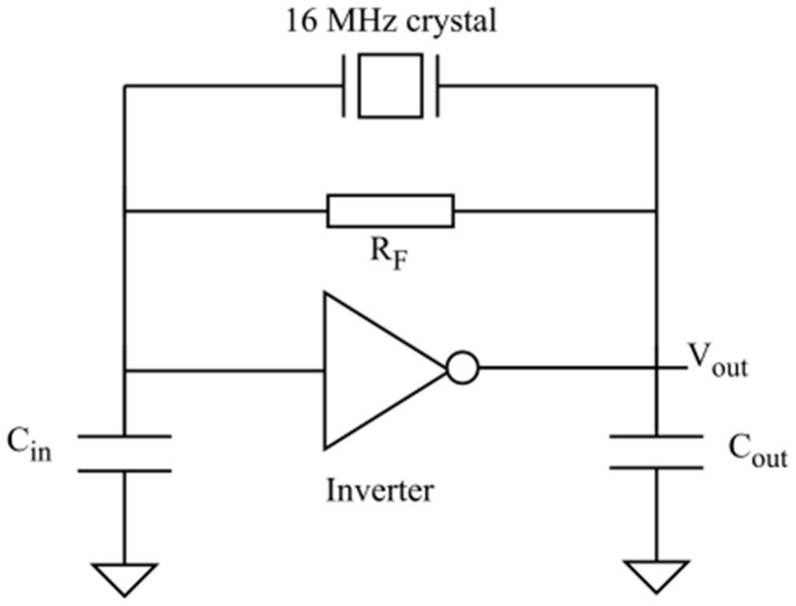
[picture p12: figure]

12

sensor geometry would be required to make an oscillator-based approach viable.
In summary, the design phase progressed from benchmarking existing BeeSpy sensors to iteratively developing and prototyping several new JFET and capacitive sensor configurations. Each design aimed to address the key limitations of inter-sensor variability and noise susceptibility identified in the literature. The following section details the experimental methodology established to evaluate and compare the performance of these prototypes quantitatively.

### 3.7. Crystal Oscillator Design

Another approach we explored was using a crystal oscillator, aiming to see if an external electric field could predictably disturb its highly stable frequency. The core idea relies on the piezoelectric effect in the quartz crystal: an electric field, in theory, should cause mechanical strain in the crystal, altering its resonant frequency. Any such frequency shift would indicate the presence and strength of the field.
The implemented circuit, shown in Figure 10, follows the Pierce oscillator topology, which is a standard configuration for generating highly stable sinusoidal signals. The design utilises a logic inverter (implemented with a NAND gate), a 16 MHz quartz crystal resonator, a feedback resistor (Rf), and two load capacitors (Cin and Cout), each with a value of 12 pF. The capacitors provide the necessary phase shift and define the load capacitance required for stable oscillation. The resistor Rf, typically in the range of 1–10 MΩ, introduces a small amount of negative feedback to bias the inverter in its linear region and sustain oscillation startup.

Figure 10-A crystal oscillator circuit used to sense electric fields
To examine the circuit’s sensitivity to external electric fields, two experimental setups were explored. In the first configuration, the crystal oscillator was positioned directly between two parallel plates driven by a sinusoidal excitation source. This setup aimed to determine whether the applied electric field could directly influence the oscillation frequency through mechanical deformation of the quartz element. In the second configuration, a capacitive sensing plate was connected to the input node of the oscillator circuit. The sensor, previously developed as a standalone electrostatic field probe, was placed between the plates while the oscillator remained shielded. This approach tested how changes in external field-induced capacitance at the input node affect the oscillator’s frequency response.

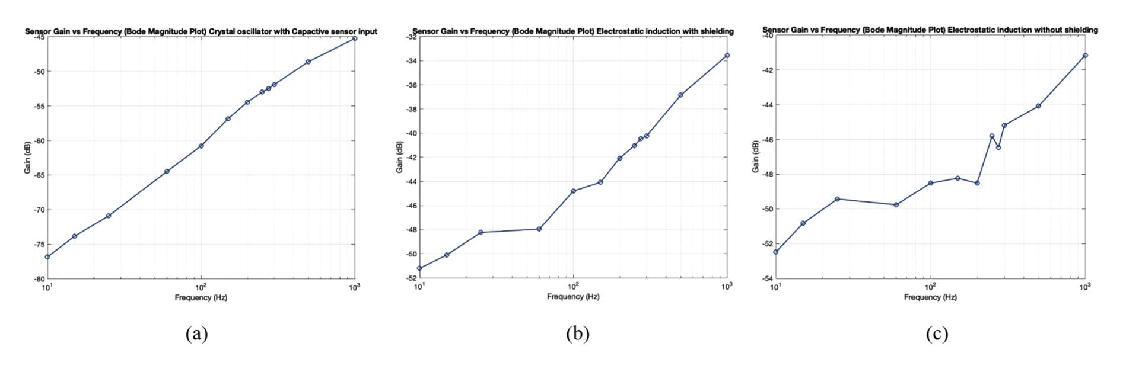
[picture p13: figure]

13

Figure 11-Bode Magnitude plots of different crystal oscillator circuits. (a) Show the bode plot for the crystal oscillator with the capacitive sensor as the input capacitor. (b) Shows the bode plot for the shielded Electrostatic induction sensor. (c) Shows the bode plot for the non-shielded Electrostatic induction sensor.
Initial prototypes were constructed on Veroboard using wired interconnections and header pins for the crystal and passive components. However, inconsistencies observed during testing raised the possibility that the long, unshielded traces were unintentionally acting as antennas, introducing parasitic coupling that masked the crystal's proper response. To address this, a dedicated PCB was fabricated to systematically study the impact of trace length, width, and routing layer on oscillator stability and sensitivity. Several variants were tested, including short top- and bottom-layer traces, extended traces of varying widths, and surface-mount layouts with direct connections.
While the circuit successfully generated stable oscillations, the results suggested that the response to external fields may have been dominated by parasitic coupling effects rather than direct crystal deformation. Further investigation is therefore needed to isolate the mechanism of sensitivity to determine whether the crystal itself responds measurably to low-frequency electrostatic fields or if the surrounding circuit geometry and capacitance changes are the primary contributors to the observed signal variations.

### 4. Experimental Setup

To evaluate the performance of the sensor prototypes detailed in Section 3, a consistent and repeatable testing methodology was required. This section describes the experimental apparatus and procedures designed to facilitate a fair comparison between sensor designs. The setup was designed to address three key challenges: simulating a bee's electric field, mitigating ambient electromagnetic noise, and ensuring the consistency of physical measurements.

### 4.1. Bee and Waggle Simulation

A primary challenge in this project was the difficulty of creating a calibrated "bee simulator" that could produce a known and controllable electrostatic charge. To overcome this, a comparative testing methodology was adopted. Instead of measuring absolute sensitivity to a calibrated source, the approach focused on measuring the relative performance of each sensor under identical and repeatable conditions.
A standardised test signal was used for all comparative evaluations to characterise the frequency response of each sensor. A 2.5 Vpp (Volts peak-to-peak) signal with frequencies ranging from 10Hz to 10kHz was
To assess the baseline performance of the sensors, the sensors were tested in a uniform field

14

between two parallel plates. A signal generator was used to apply a test signal to one plate, creating a consistent field across the sensor array being tested.
To simulate the localised field of a single waggle-dancing bee, a small copper plate was excited with a sinusoidal signal. This allowed for the evaluation of a sensor's response to a non-uniform, point-source field and helped to observe the signal coupling between adjacent sensors in an array.

### 4.2. Controlled Testing Environment and Noise Control

The high-impedance nature of sensor designs makes them highly susceptible to ambient electromagnetic interference (EMF), particularly at the 50Hz frequency from mains power supplies. Additionally, the gain of the sensors is highly dependent on the distance of the signal source and the sensor.
To address these issues, a controlled testing environment was constructed. A Faraday cage shielded the sensors from EMF interference, and this enclosure significantly reduced the noise floor, allowing for a more precise measurement of the sensor's response to the test signal. To have a consistent distance for sensor tests, a physical testing rig was built to ensure that all sensors were tested under the same geometric conditions. The rig fixed the distance between the emitting plate and the sensing plate to approximately 2.5 cm, with a ground plate positioned less than 1 cm behind the sensor. The position of all components was recorded to ensure consistency across all experimental runs.

### 4.3. Data Acquisition

A digital oscilloscope was used to capture the output waveform from the sensor under test. It was noted during testing that the unshielded oscilloscope probes were susceptible to acting as antennae, picking up some residual noise. For future experiments, the use of shielded BNC cables, connected directly to the oscilloscope, is recommended to improve signal integrity further.

### 4.4. Preliminary In-Hive Set Up and Testing

To validate the functionality of the sensors in a live environment, a preliminary beehive test was conducted within an active observation beehive. The objective was to capture initial real-world electrostatic data and identify potential operational challenges, including environmental noise and signal integrity issues.
The test involved the sequential placement of three distinct sensor prototypes: the original electret-based 'BeeSpy', a JFET-based 'BeeSpy' variant, and the custom capacitive sensor coupled with an instrumentation amplifier. To ensure comparable testing conditions, each sensor was individually positioned at the exact fixed location within the hive. Due to the hive environment, the distance between the sensor and the bees could not be precisely controlled but was maintained at less than 1 cm. The setup of the observation hive test is shown in Figure 12.

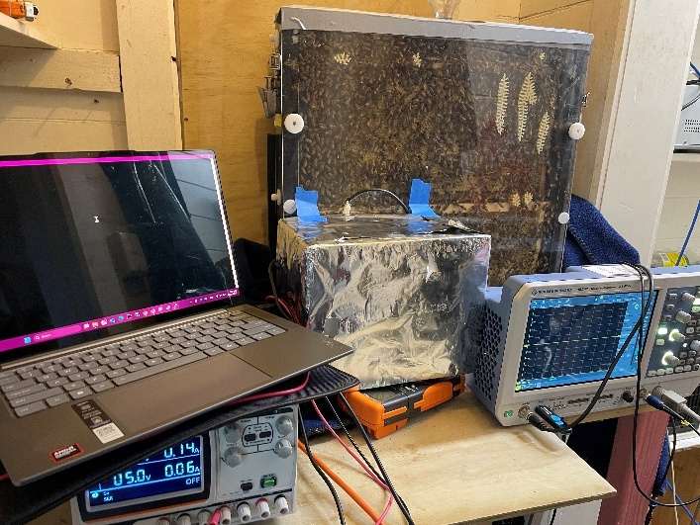
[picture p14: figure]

15

Figure 12-Observation hive test setup
Data acquisition methods were adapted for each sensor type. For the two 'BeeSpy' variants, data was logged for 15 minutes using a Programmable System-on-Chip (PSoC) data acquisition unit. The capacitive sensor, however, produced an output signal range of ±5V, which exceeded the PSoC's analogue-to-digital converter (ADC) input specifications. Consequently, data for this sensor were captured and qualitatively assessed using a portable digital oscilloscope.
A significant observation during this preliminary stage was the persistent presence of 50 Hz mains hum across the output of all sensors. This interference was prominent despite the application of preliminary electromagnetic shielding to the sensor assemblies. The magnitude of this noise highlights the importance of robust EMI (Electromagnetic Interference) mitigation as a critical design consideration for the final in-hive system.

### 5. Results

This section presents experimental results from the comparative evaluation of the baseline sensor prototype and the newly developed sensor prototypes. From the sensors explored in Section 4, two sensors were chosen, the JFET-based sensor and the capacitive sensor with an instrumentation amplifier, as they showed promising results during development.
The primary focus is on characterising the frequency response, inter-sensor consistency, and noise immunity of each design.

### 5.1. Baseline Sensor Performance

### 5.1.1. Electret BeeSpy Sensor Array

The electret-based sensors were tested under a uniform electric field to assess their consistency. Figure 13 shows the results for tests in a uniform electric field and with a single point of excitation, respectively.

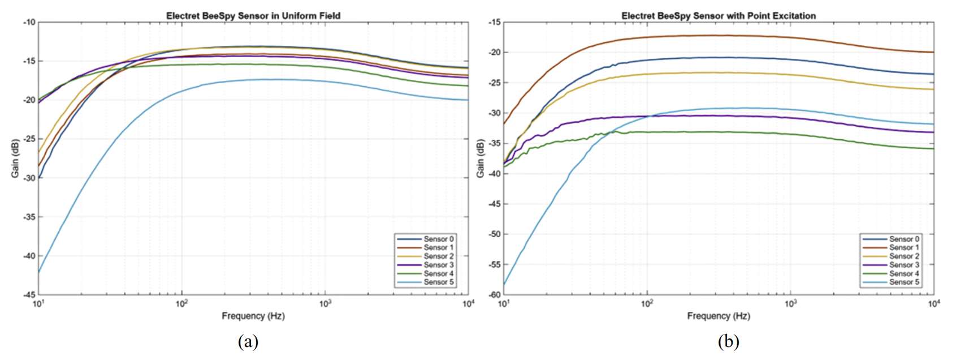
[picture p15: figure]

16

Figure 13-Frequency-gain response of the Electret BeeSpy sensor array. (a) The test was conducted under a uniform electric field (b). The test was conducted with a point excitation at the centre of the board

Under a uniform electric field (Figure 13a), all six electret sensors exhibit a similar characteristic. The gain increases sharply from 10 Hz, peaks between approximately 100 Hz and 1 kHz, and then gradually rolls off at higher frequencies. This response shape indicates that the sensors are most sensitive within the mid-frequency range, covering signals such as fanning. Still, sensitivity is lower at the fundamental frequencies of the waggle dance (often 15 Hz). Crucially, Figure 13a clearly shows significant inter-sensor variability. At the peak sensitivity around 1 kHz, the gain differs by approximately 5 dB between the most sensitive sensors and the least sensitive (Sensor 5). At lower frequencies, this variation is even more pronounced; for example, at 20 Hz, the gain spread exceeds 13 dB.

When tested with a point excitation source simulating a single bee at the centre of the board (Figure 13b), a similar gain characteristic is observed. However, the overall gain is generally lower compared to the uniform field test, likely due to reduced field coupling. The point excitation test further exacerbates the inter-sensor variability. At the 1 kHz peak, the difference between the highest-performing sensor (Sensor 1) and the lowest (Sensor 5) increases to approximately 17 dB. Sensor 5 consistently demonstrates significantly lower gain across both test conditions, underscoring the inherent inconsistency within this sensor type.

These results quantitatively confirm the variability problem highlighted in previous studies. The inconsistent gain between individual electret sensors necessitates complex calibration for each sensor in an array, making reliable data collection difficult, and directly motivates the search for more consistent and reliable sensor designs pursued in this project

### 5.1.2. JFET BeeSpy 5 Sensors

The baseline JFET BeeSpy 5 sensors were also tested in the uniform field. The results, shown in Figure 14, show a similar trend to that of the electrets.

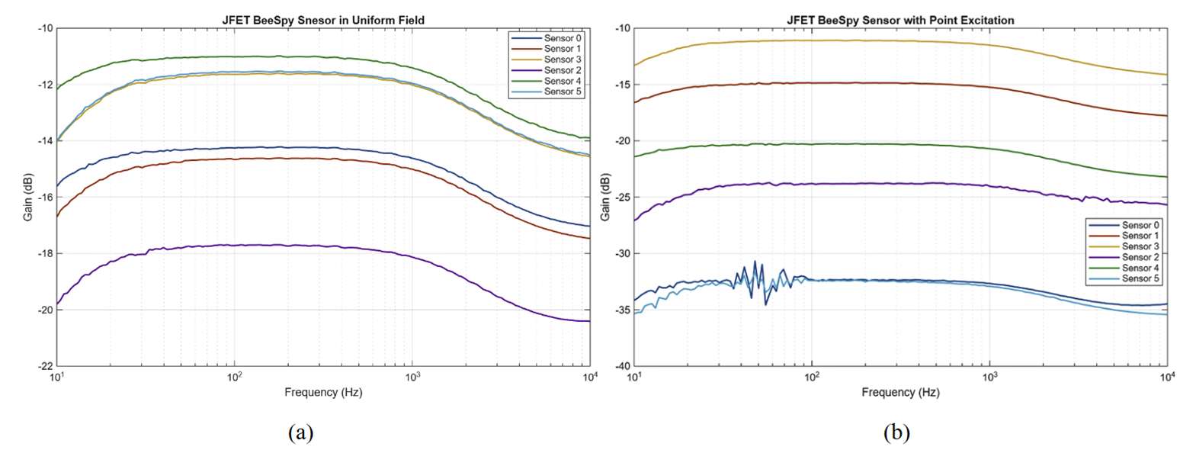
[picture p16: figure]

17

Figure 14-Frequency-gain response of the JFET BeeSpy 5 sensors. (a) The test was conducted under a uniform electric field (b). The test was conducted with a point excitation at the centre of the board
In the uniform electric field test (Figure 14a), the BeeSpy 5 JFET sensors exhibit a bandpass-like frequency response. The gain rises from 10 Hz, plateaus between approximately 50 Hz and 2 kHz, and then begins to roll off slightly towards 10 kHz. Like the electret sensors, this suggests good sensitivity in the mid-frequency range, which is relevant to several bee communication signals. However, significant inter-sensor variability is immediately apparent. The sensors appear grouped into distinct performance tiers. At 1 kHz, the gain ranges from approximately -11 dB (Sensor 1) to nearly -18 dB (Sensor 3), resulting in a spread of roughly 7 dB. This variation is consistent across the passband.
Under point excitation at the centre of the board (Figure 14b), the same general bandpass shape is maintained, though overall gain levels are reduced compared to the uniform field. The variability between sensors persists, and in some frequency ranges, it appears even more pronounced. For instance, at 1 kHz, the gain now spans approximately 12 dB, ranging from about -12 dB (Sensor 1) to -24 dB (Sensor 3). Notably, Sensors 0 (blue) and 5 (light blue) exhibit significant noisy oscillations in the 30 Hz to 100 Hz range during the point test, which were not present in the uniform field test. As suggested in preliminary analyses, this specific disturbance might be attributable to connection issues or localised noise pickup rather than an inherent sensor characteristic, but it requires further investigation.
Overall, while the BeeSpy 5 JFET sensors demonstrate sensitivity within a relevant frequency band, these tests confirm that they still suffer from substantial inter-sensor gain variability, similar to or even exceeding that of the electret sensors under certain conditions. This inherent variation, likely due to manufacturing tolerances in discrete JFET components, necessitates individual sensor calibration and complicates the deployment of large, reliable sensor arrays, further motivating the development of the more consistent sensor topologies explored later in this report

### 5.2. Performance of Developed Sensor Prototypes

The newly designed sensors were evaluated using the same methodology to allow for direct comparison against the baseline.

### 5.2.1. Single-Stage JFET Sensor (Iteration 1)

The single-stage JFET configuration (Iteration 2 in Fig. 5) was also tested in the uniform field, with the results shown in Figure 15. Unlike the other JFET configurations, the data obtained from this prototype is highly erratic and noisy, particularly below approximately 500 Hz. The gain fluctuates wildly over tens of dB, and no consistent frequency response trend can be discerned between the two tested units or compared to the other sensor types.

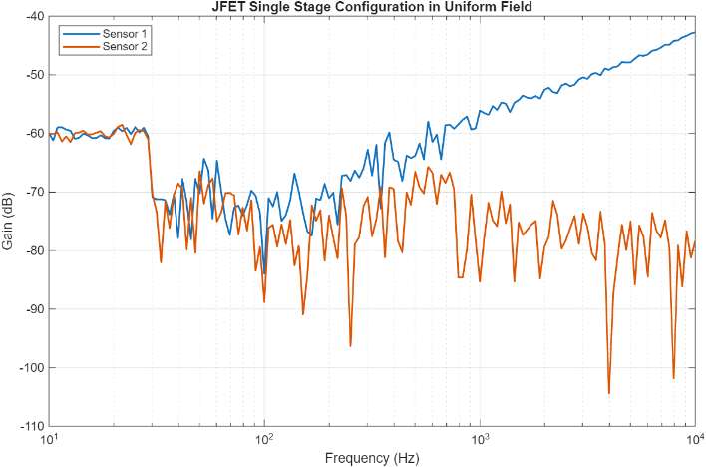
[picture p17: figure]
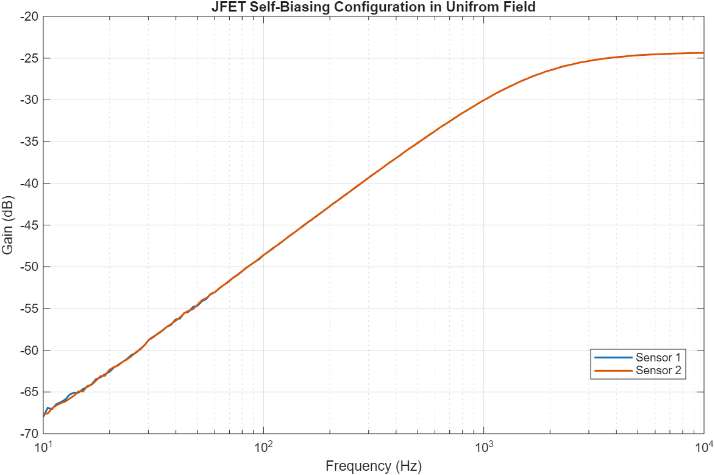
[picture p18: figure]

18

Figure 15-Frequency response of the single-stage JFET sensors in a uniform field
As noted during development, these results are considered questionable and are likely not representative of the true potential of the circuit topology itself. The poor signal quality is likely attributed to unstable connections and potential noise pickup inherent in the Veroboard construction used for this specific prototype. Consequently, due to the unreliable nature of the collected data, this iteration could not be meaningfully evaluated or directly compared against the baseline or the more robust self-biasing JFET design.

### 5.2.2. Self-Biasing JFET Sensor (Iteration 3)

The final self-biasing JFET sensor design (Iteration 3) demonstrated an improvement in consistency compared to the baseline sensors. Figure 16 presents the frequency response of two units of this design when tested in a uniform electric field.

Figure 16- Frequency response of the self-biasing JFET sensors in a uniform field
Both self-biasing sensors exhibit a clear high-pass filter characteristic. The gain starts significantly lower than the BeeSpy sensors at lower frequencies, measuring approximately -67 dB at 10 Hz. However, the gain increases steadily and consistently with frequency, plateauing around -24 dB above 2 kHz. This contrasts with the bandpass response observed in the BeeSpy JFET sensors, indicating different filtering properties inherent to this self-biasing topology.
The most compelling result shown in Figure 16 is the consistency between the two sensors. The traces for Sensor 1 and Sensor 2 are virtually indistinguishable across the entire tested frequency range (10 Hz to 10 kHz). This near-perfect overlap indicates that the self-biasing configuration successfully mitigates the effects of component-level variations inherent in JFETs.

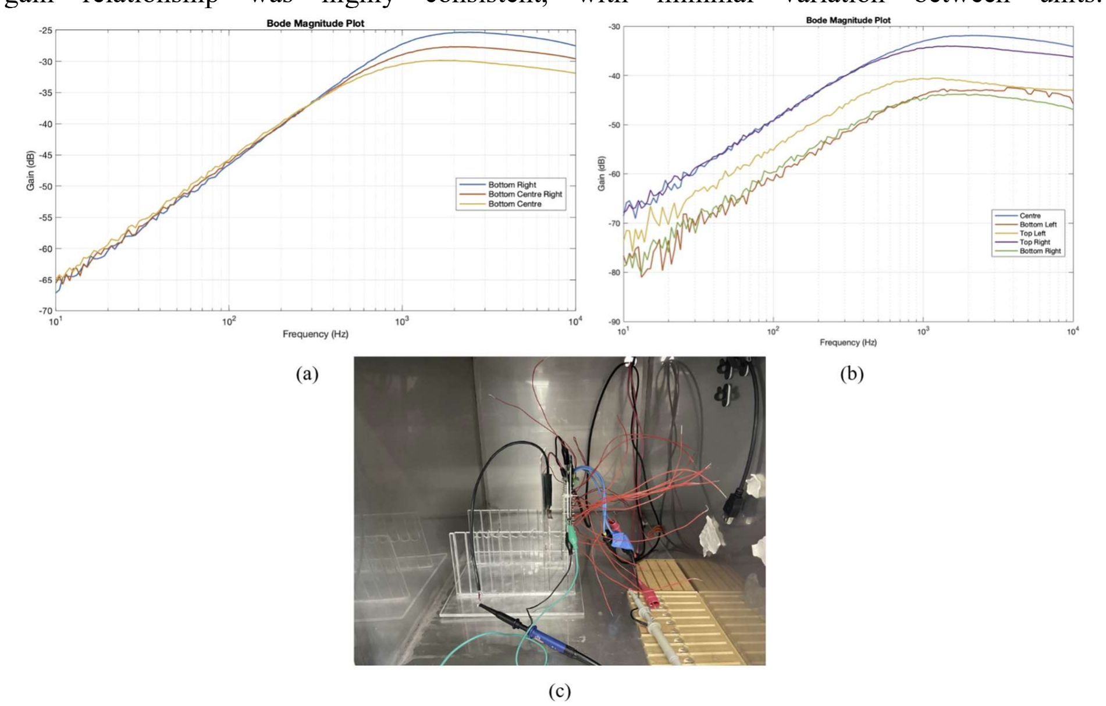
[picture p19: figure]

19

While this configuration exhibits lower gain at the lowest frequencies compared to the BeeSpy 5 sensors, its high stability and, most importantly, its excellent inter-sensor consistency make it a promising candidate for developing reliable and scalable sensor arrays for in-hive monitoring.

### 5.2.3. Capacitive Sensor with Instrumentation Amplifier

The capacitive sensor with an instrumentation amplifier was evaluated for both inter-sensor consistency and spatial sensitivity, with the results presented in Figure 17. This design represents a significant departure from the JFET-based approaches and yielded highly promising results. The results showed that across an array of identical sensors, the frequency-gain relationship was highly consistent, with minimal variation between units.

Figure 17 - Frequency-gain response of the Capacitive Sensor with Instrumentation amplifier, with a uniform field. (a) The test was conducted under a uniform electric field (b). The test was conducted with a point excitation at the centre of the board. (c) Shows the experimental setup for the point excitation test.
Figure 17a shows the frequency-gain response of three adjacent sensors from the array when subjected to a uniform electric field. The sensors exhibit a distinct high-pass filter characteristic, similar in shape to the self-biasing JFET prototype, with gain rising steadily from approximately -67 dB at 10 Hz to a peak of around -25 dB near 1 kHz.
The most compelling result from this test is the exceptional consistency between the three sensor units. Below approximately 300 Hz, the performance of the "Bottom Right," "Bottom Centre Right," and "Bottom Centre" sensors is virtually identical, with their response curves overlapping almost perfectly. This demonstrates that the IA-based capacitive design effectively overcomes the significant inter-sensor variability that plagued both the electret and BeeSpy 5 JFET baseline sensors. While minor divergence (less than 3 dB) is observed at higher frequencies, the consistency in the critical low-frequency band (10-300 Hz) for waggle dance and fanning detection is a significant improvement.
To assess the array's ability to provide spatial information, a point test was conducted using the "waggle" simulator positioned at the centre of the 5x5 sensor board. As shown in Figure

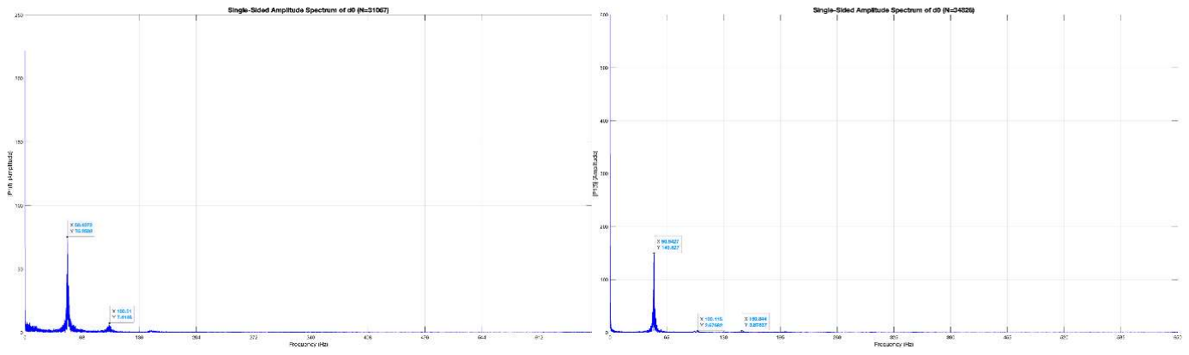
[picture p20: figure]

20

17b, the results clearly demonstrate a strong correlation between signal strength and proximity to the source. The "Centre" sensor recorded the highest gain, peaking around -35 dB. The corner sensors ("Top Left," "Top Right," "Bottom Left," "Bottom Right") recorded progressively lower gains based on their distance from the central excitation point, with the bottom corner sensors showing the lowest gain, approximately 10-15 dB below the centre sensor at the 1 kHz peak.
An interesting observation from Figure 17b is that the two top corner sensors ("Top Left" and "Top Right") consistently exhibit a slightly higher gain (approximately 3-5 dB higher) than their bottom corner counterparts ("Bottom Left" and "Bottom Right"). While the overall trend of decreasing gain with distance from the centre holds, this top-bottom asymmetry was unexpected. It is hypothesised that this minor discrepancy may be due to the experimental setup (visible in Figure 17c). The connecting wires leading to the top row of sensors might have inadvertently acted as small antennae, providing a slight additional signal boost that was less pronounced for the bottom row sensors situated closer to the grounded base plate.
Taking it all together, the high consistency and demonstrated spatial resolution of the Capacitive Sensor with an instrumentation amplifier make it an excellent and significant improvement over the baseline BeeSpy technologies. This result confirms that the sensor array can successfully detect the location of a localised signal source, a key requirement for tracking the motion of a single bee during a waggle dance. The clear differentiation in gain across the array validates the design's potential for providing spatial granularity.

### 5.3. Preliminary In-Hive Test Results

The brief 15-minute test in a live beehive provided valuable qualitative data. The sensors were able to detect general hive activity. However, due to the short duration of the recording and the time of year, no distinct waggle dance events could be definitively identified from the captured data. The following results show the electret and JFET BeeSpy sensors.

Figure 18-Fast Fourier Transform (FFT) of sensor data collected from the beehive test. (left) Shows the (left) Shows the FFT analysis of one of the electret-based BeeSpy sensors. (right) Shows the FFT analysis of one of the JFET-based BeeSpy sensors
The primary data from this test is presented as a Fast Fourier Transform (FFT) analysis for both the electret and JFET-based BeeSpy sensors (Figure 18). This analysis reveals the frequency components of the signals recorded inside the hive.

A critical and immediate finding, visible in both plots, is the presence of a highly dominant signal peak at approximately 50 Hz. This peak corresponds to electromagnetic interference (EMI) from the building's mains power supply, commonly known as "mains hum". This interference was persistent across all tested sensors, and as shown in the FFT, its amplitude is significantly larger than any other detected signal.

### 6. Discussion

21

The experimental results clearly validate the initial premise: the baseline BeeSpy sensors (both electret and JFET BeeSpy 5) exhibit substantial performance variations between individual units. This inconsistency, quantified as gain differences exceeding 10 dB in some frequency ranges (Figs. 13, 14), necessitates complex individual calibration and likely contributes to the high false-negative rates reported in identifying behaviours like the waggle dance.
Two of the developed prototypes demonstrated significant improvements in reducing variability. The self-biasing configuration achieved excellent inter-sensor consistency, with nearly identical frequency responses between the tested units (Figure 16). This directly addresses the variability issue inherent in floating-gate JFET designs. While exhibiting lower gain at very low frequencies (< 50 Hz) compared to the BeeSpy 5 baseline, its stable high-pass characteristic offers good sensitivity across the broader range relevant to bee signals (including fanning and potentially stop signals). Further optimisation of the gain stage could enhance low-frequency performance if needed.
This capacitive sensor with an instrumentation amplifier design demonstrated outstanding consistency among tested units, particularly below 300 Hz (Fig. 17a). This suggests that the manufacturing process for the capacitive plates is highly repeatable, overcoming the component tolerance issues commonly seen in JFETs. Furthermore, the point excitation test (Fig. 17b) confirmed the array's spatial sensitivity, successfully differentiating signal strength based on proximity to the source. This capability opens the door for not just detecting signals, but potentially tracking bee movement, offering richer behavioural data than single-point measurements. The slight asymmetry observed between top and bottom sensors is likely an experimental artefact related to wiring rather than a fundamental design limitation.
The exploration of alternative designs, such as the single-stage JFET, electrostatic induction, and oscillator circuits, reinforced the challenges in achieving reliable performance, often due to prototyping limitations (e.g., noise on Veroboard, PCB grounding issues).

### 6.1. Noise, Shielding, and Practical Considerations

The experiments highlighted the importance of electromagnetic shielding in high-impedance electrostatic measurements. The Faraday cage effectively mitigated mains hum in the laboratory setting. However, the persistence of 50 Hz noise during the preliminary in-hive test, despite shielding efforts, highlights a significant real-world challenge. This suggests that some digital filtering (e.g., a 50 Hz notch filter) will be needed in the data processing pipeline for any practical deployment, complementing physical shielding.
Furthermore, the high consistency of the capacitive sensor array offers a distinct advantage in this regard. A predictable, uniform response across the array means that a single, well-tuned 50 Hz notch filter can be applied universally to the data. In contrast, the significant gain variability of the baseline sensors (as shown in Figures 13 and 14) would complicate this process, potentially requiring individual filter calibration for each sensor's unique noise profile to avoid distorting the underlying biological signals.

### 6.2. Implications and Relation to Literature

The improved consistency demonstrated by the self-biased JFET and capacitive sensors, when used in conjunction with an instrumentation amplifier, directly addresses the primary technological gap identified in the literature review. By reducing the need for complex individual calibration, these designs are inherently more scalable and reliable. While this project couldn't definitively measure a reduction in false-negative rates due to limited in-hive testing, the enhanced consistency strongly suggests the potential for more dependable signal

22

detection compared to the baseline systems. The spatial resolution capability of the 25-board capacitive sensors with an instrumentation amplifier sensor array represents a novel advancement beyond the current state-of-the-art described by Paffhausen et al. [8].

### 6.3. Limitations and Future Work

This study was subject to limitations. The absence of a calibrated charge source meant that performance was assessed relatively rather than absolutely. The preliminary in-hive testing was brief and conducted outside peak foraging season, preventing validation against known waggle dance signals. Furthermore, laboratory conditions, even shielded, cannot fully replicate the complex thermal, humidity, and electrostatic environment within an active hive. Despite these constraints, the project successfully demonstrated a promising sensor design and a robust methodology for comparative evaluation. To further advance this work, several key areas are recommended for future investigation:
- Develop a Dedicated PCB: To move from prototype to a deployable system, a compact and robust Printed Circuit Board (PCB) should be designed for the finalised self-biasing JFET sensor. This will enhance reliability and facilitate easier installation in a real hive.
- Conduct Long-Term In-Hive Studies: The most critical next step is to deploy an array of the new JFET sensors in a beehive for an extended period. This will be essential to validate their long-term stability in the challenging hive environment and, most importantly, to determine if their improved consistency translates to a lower false-negative rate for detecting waggle dances.
- Create a Calibrated "Bee Simulator": To enable quantitative sensor calibration, future work should focus on developing a reliable method for creating a known, controllable charge source that accurately mimics the electrostatic properties of a bee.
- Revisit and Refine Capacitive Sensing: The high consistency of the instrumentation amplifier design warrants further investigation. Future efforts could focus on improving its sensitivity, perhaps by exploring alternative sensor geometries to maximise fringing field effects.
- System Integration: For a truly comprehensive monitoring solution, the ESF sensor array could be integrated with other environmental sensors (e.g., temperature, humidity, CO2). This would allow researchers to correlate bee behaviour with a broader range of hive conditions, providing deeper insights into colony health.
By addressing these directions, future research can transform the current prototype into a scalable, field-ready system capable of long-term, non-invasive monitoring of honeybee behaviour and colony health.

### 7. Conclusion

This project set out to address the critical limitations of existing electrostatic field (ESF) sensors for monitoring honeybee behaviour. Current systems, while conceptually sound, are hindered by issues of low sensitivity, high inter-sensor variability, and environmental susceptibility, resulting in unreliable data and a high rate of false negatives in detecting key behaviours, such as the waggle dance.
Through a systematic process of design, prototyping, and comparative testing, this project has successfully developed and validated a sensor design that directly addresses these

23

shortcomings. The experimental results confirmed that baseline electret and floating-gate JFET sensors exhibit significant performance variation, reinforcing the need for a more stable solution. A highly consistent instrumentation amplifier-based capacitive sensor was developed, demonstrating the potential for creating scalable arrays with spatial sensing capabilities.

References

[1] D. Clarke, E. Morley and D. Robert, "The bee, the flower, and the electric field: electric ecology and aerial electroreception," J Comp Physiol A, vol. 203, (9), pp. 737, 2017. DOI: 10.1007/s00359-017-1176-6.
[2] U. Greggers et al, "Reception and learning of electric fields in bees," Proc. R. Soc. B., vol. 280, (1759), 2013. . DOI: 10.1098/rspb. 2013.0528.
[3] G. P. Sutton et al, "Mechanosensory hairs in bumblebees ( Bombus terrestris ) detect weak electric fields," Proc. Natl. Acad. Sci. U. S. A., vol. 113, (26), pp. 7261, 2016. DOI: 10.1073/pnas. 1601624113.
[4] K. v. Frisch, The Dance Language and Orientation of Bees. 1967.
[5] D. M. Eiri and J. C. Nieh, "A nicotinic acetylcholine receptor agonist affects honey bee sucrose responsiveness and decreases waggle dancing (vol 215, pg 2022, 2012)," J. Exp. Biol., vol. 219, (13), pp. 2081, 2016. DOI: 10.1242/jeb. 143727.
[6] Y. Yan et al, "Electrostatic sensors – Their principles and applications," Measurement, vol. 169, 2020. DOI: 10.1016/j.measurement.2020.108506.
[7] R. Puers, "Capacitive sensors: when and how to use them*,".
[8] B. H. Paffhausen et al, "The Electronic Bee Spy: Eavesdropping on Honeybee Communication via Electrostatic Field Recordings," Front. Behav. Neurosci., vol. 15, 2021. DOI: 10.3389/fnbeh. 2021.647224.
[9] W. Storr, “Junction Field Effect Transistor or JFET tutorial,” 21 October 2024. [Online]. Available: https://www.electronics-tutorials.ws/transistor/tran_5.html. [Accessed 19 Oct 2025].
[10] X. Tang et al, "Analysis of the Dynamic Sensitivity of Hemisphere-Shaped Electrostatic Sensors’ Circular Array for Charged Particle Monitoring," Sensors, vol. 16, (9), 2016. DOI: 10.3390/s16091403.

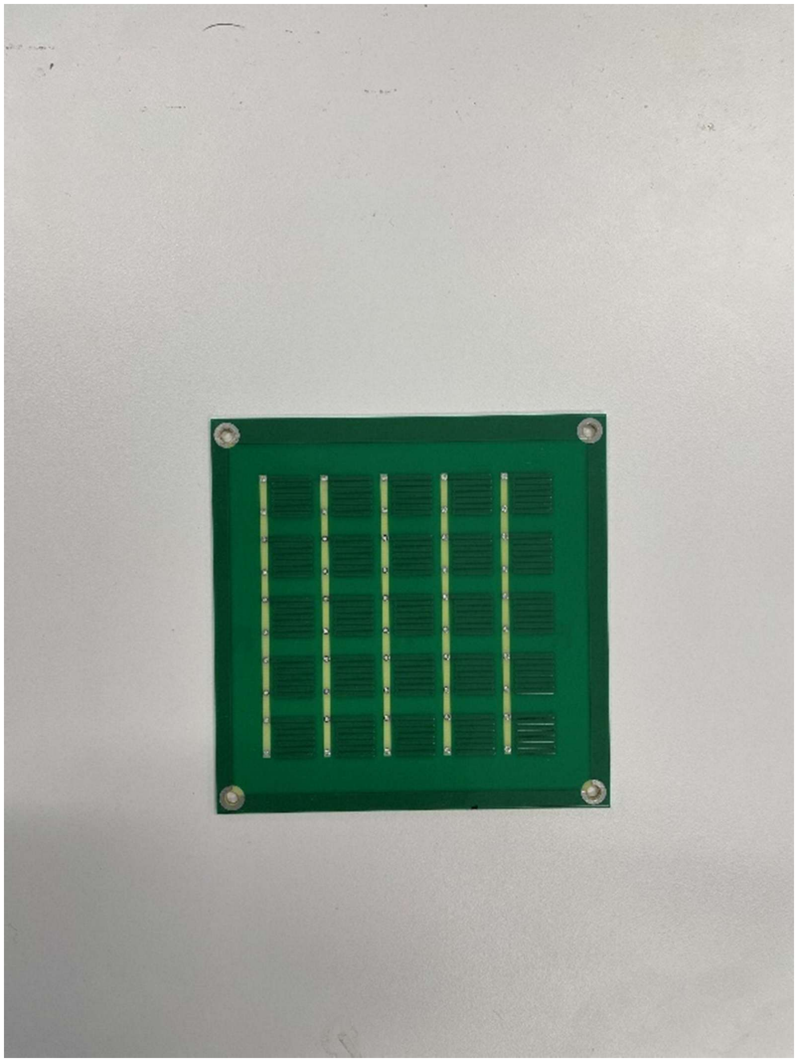
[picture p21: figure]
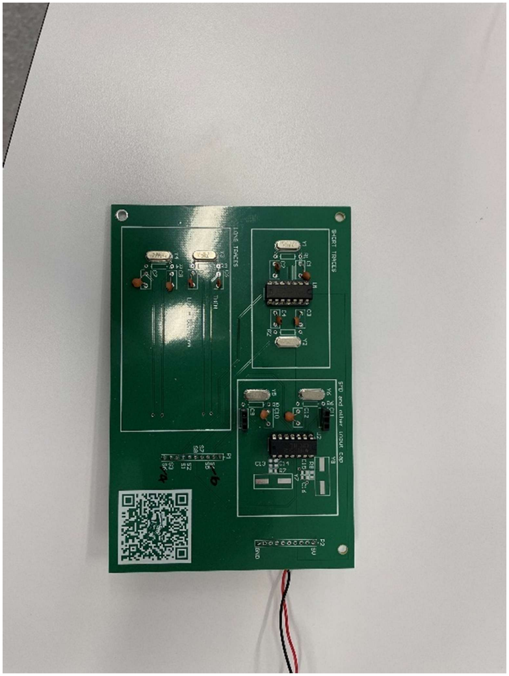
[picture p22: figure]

24

Appendix A: Sensor Designs

Figure A1-5x5 Capacitive Sensing PCB

Figure A2-Crystal Oscillator PCB. Showcases different track lengths

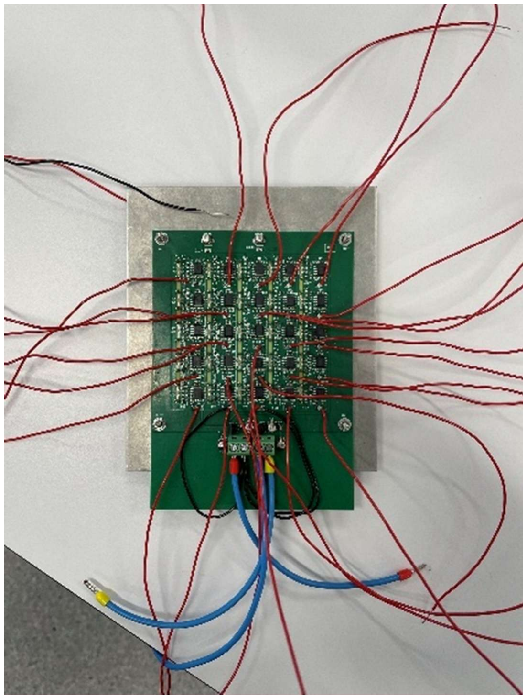
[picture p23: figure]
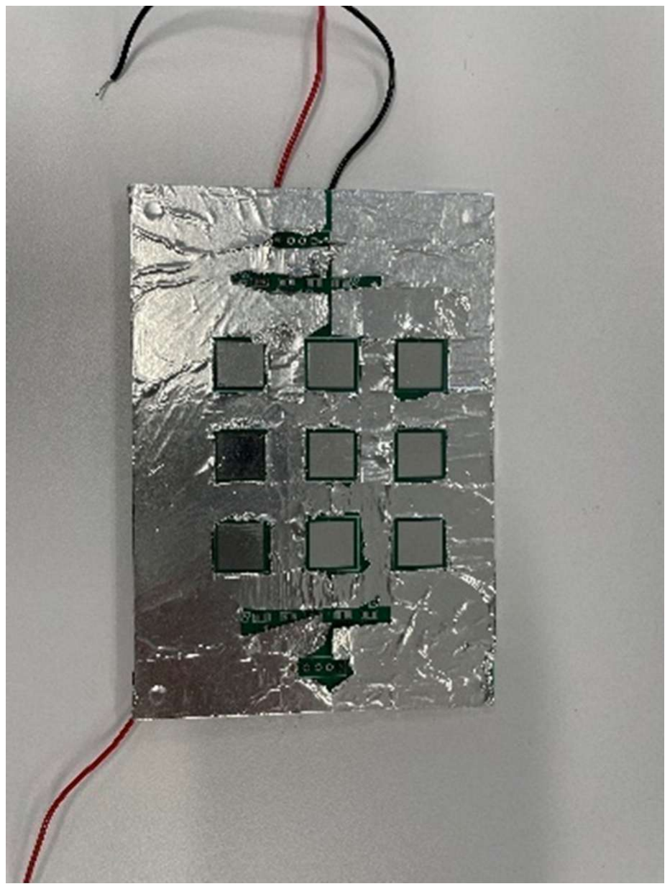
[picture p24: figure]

25

Figure A3-Fully assembled capacitive sensing with instrumentation amplifier PCB

Figure A4-Induction-based sensor PCB.

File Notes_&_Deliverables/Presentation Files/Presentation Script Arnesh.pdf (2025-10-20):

Arnesh Script
Project:

Slide 1:
Hey there Im Arnesh this is Jayti we are group 130 and our project is motion detection of bees using electrostatic sensors.

Slides 2:
So whats the problem?

Bees are important member of the natural environment. Being one of the main pollinators we as human rely deeply on them especially for agriculture.

However one of the main issues is that we currently have no way to monitor the health of the bees and the hive, without ripping open the hive and inspecting by eye which stresses the bees out. So nonintrusive monitor is vital.

Now monitoring the health of the hive can be an early signifier of issues in the natural ecosystem allowing preventative measure to be taken before disaster which is the main driver of this project

Slide 3:
Why Electrostatics?

Unlike our sister project which monitors CO2 we are approaching the same problem from another perspective.

Electrostatics is key as bees healiy rely on electro reception to forage for food and communication. Using the Johnston’s organ.

Bees are able to gain a charge through the triboelectric effect through flight and friction between body parts.

When positively charged forager bees around 30 to 50 pico Coulombs return to the hive they communicate information about a food source, by performing a waggle dance.

A waggle dance communicates the exact location of the food source from the hive which encodes exact information about distance and direction of the food source from the hive with respect to the sun.

The waggle dance also communicates to beekeepers about the health of the hive itself. As internal hive activity can be used to identify issues in the ecosystem early on before the negative impacts start to take effect.

Slide 4:
Our project objectives
- To identify the waggle dance
- To create novel sensors that can be deployed in a hive

- To tackle the beehive monitoring with another nonintrusive approach

Slide 6:
What has been used so far?
Here we have the BeeSpy system, the parent project. This is how testing has been done previously. Here sensors are placed inside of the hive to monitor the bees. There have been 2 versions of the electrostatic sensors:
The Electret based
- An electret is a dielectric with a quasi-permanant electric charge and was the first version of the ESF
Opamp
- The opamp design was the second iteration of sensors however there were some issues with the manufacturing thus giving questionable results, so we decided to try and make these sensors ourselves to validate the design.
Both of these versions are manufactured on a PCB with a 6 sensor array.

Slide 7:
The current system has many limitations such as, limited sensitivity to waggle dances further away from the sensors, the system requiring weekly battery changes thus potential loses in data, degradation of performance sensors, and false positives.

Slide 8:
Our Findings
Electrets

Electret base sensors have been the base line sensor which we compare our designs to, as it was previously used in the original BeeSpy project.

An electret is a material which holds a quasi-permanent electrical charge

These electrets are found in microphones, the beespy project uses the microphones with the casing removed, exposing the electret inside

When an external electric field is applied, it changes the capacitance of the capacitor

Doing some initial testing of these electret sensors, we found to be some variability in the signals produced due to the variability of the JFET in the sensor circuit and a sensor which didn’t work

The thing about electrets are that they can be easily damaged in installation and handling

Jayti Script:
- Jfets
- Jfets where very promising as a sensor using a very simple and low cost circuit design, thus making the development of the senor trivial
- We explore three different versions of the jfet sensors.

- In the first sensor design we found it would go into saturation, so the next two iterations try to keep it in the linear region of the jfet
- Here is the results we collected from versions 2 and 3, we gave them the same signal as the electret test (8Vpp, 1kHz) and we can see a significant drop in amplitude
- PSoC
- With the PSoC we are currently investigating two methods of sensing changes in capacitance
- One using the PSoCs inbuilt capacitor
- PSoC
■ The PSoC has in buit cap sensing technology which we could use to do our sensing however from our recent testing the results were inconclusive. The plan was to plug in a capacitor to one of the capsensing pins and then placing the capacitor inside of an electric field, and the field should change the capacitance which we can then use to as a metric to do some sensing.
- Schmitt trigger design
■ The concept is that we create a symmetrical signal using two current sources. One source is constantly on and another is controlled by an external schmitt trigger, giving a symmetric triangular output on a capacitor. When an electrostatic field is applied to the capacitor we should see a change in the period of the capacitor voltage.
■ What actually happened when an external electrostatic field was applied, we saw a very minimal change in the period.
- Noise
- Noise sucks, due to the nature of our sensing method when testing in the labs our sensed signal get desimated by noise especially the 50hz mains frequency, thus ensuring our sensor is encased in a faraday cage us vital to ensure that the sensed signal is pure and unaffected by noise.
- What are we going to do next
- Design a testing rig to get comparable results
- Finalising a sensor design and developing a PCB
- CST analysis - Does increasing fringing increases the sensitivity

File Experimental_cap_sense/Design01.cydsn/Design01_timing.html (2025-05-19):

# Static Timing Analysis

Project : | Design01
Build Time : | 05/19/25 10:13:42
Device : | CY8C5888LTI-LP097
Temperature : | -40C - 85/125C
VDDA : | 5.00
VDDABUF : | 5.00
VDDD : | 5.00
VDDIO0 : | 5.00
VDDIO1 : | 5.00
VDDIO2 : | 5.00
VDDIO3 : | 5.00
VUSB : | 5.00
Voltage : | 5.0

Expand All | Collapse All | Show All Paths | Hide All Paths

+ Timing Violation Section

No Timing Violations

+ Clock Summary Section

Clock | Domain | Nominal Frequency | Required Frequency | Maximum Frequency | Violation
ClockBlock/aclk_glb_ff_0 | ClockBlock/aclk_glb_ff_0 | UNKNOWN | UNKNOWN | N/A
CyILO | CyILO | 1.000 kHz | 1.000 kHz | N/A
CyIMO | CyIMO | 3.000 MHz | 3.000 MHz | N/A
CyMASTER_CLK | CyMASTER_CLK | 24.000 MHz | 24.000 MHz | N/A
CyBUS_CLK | CyMASTER_CLK | 24.000 MHz | 24.000 MHz | N/A
Clock_1 | CyMASTER_CLK | 12.000 MHz | 12.000 MHz | N/A
CyPLL_OUT | CyPLL_OUT | 24.000 MHz | 24.000 MHz | N/A

+ Clock To Output Section

+ ClockBlock/aclk_glb_ff_0

Source | Destination | Delay (ns)
\Comp_1:ctComp\/out | pw(0)_PAD | 24.635

Type | Location | Fanout | Instance/Net | Source | Dest | Delay (ns)
comparatorcell | F(Comparator,2) | 1 | \Comp_1:ctComp\ | \Comp_1:ctComp\/clock | \Comp_1:ctComp\/out | 1.000
Route | | 1 | Net_13 | \Comp_1:ctComp\/out | pw(0)/pin_input | 8.384
iocell2 | P0[0] | 1 | pw(0) | pw(0)/pin_input | pw(0)/pad_out | 15.251
Route | | 1 | pw(0)_PAD | pw(0)/pad_out | pw(0)_PAD | 0.000
Clock | | | | | Clock path delay | 0.000

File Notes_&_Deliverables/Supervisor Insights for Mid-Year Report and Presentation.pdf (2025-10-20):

Mid-year report:
- All about progress
●

Presentation:
- One person speaks, then the other person no interleaving
- 5 minutes each - 4 or 5 slides
- We need to convey to the audience who doesn't know much about these things
- Give a broad perspective with some technical details
- Equations
- Waveforms
- Schematics
- In the next 6 weeks, what are the additional results we want to target
- What are the challenges
- What we have done till now, results

Challegns
- No instruments to quantify
- Future work
- Simulation measurements

Questions that people may ask: ●

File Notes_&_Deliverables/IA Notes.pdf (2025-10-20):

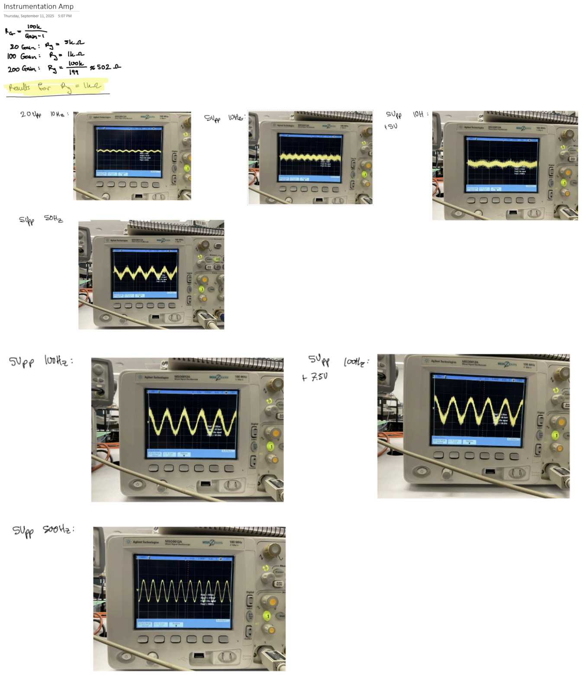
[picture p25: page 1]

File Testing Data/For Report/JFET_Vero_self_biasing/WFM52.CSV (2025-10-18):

in Sa | Frequency in Hz | Gain in dB | Phase in ° | Amplitude in Vpp
1.00E+00 | 1.000E+01 | -6.799E+01 | -1.134E+02 | 2.500E+00
2.00E+00 | 1.047E+01 | -6.690E+01 | -1.148E+02 | 2.500E+00
3.00E+00 | 1.096E+01 | -6.706E+01 | -1.131E+02 | 2.500E+00
4.00E+00 | 1.148E+01 | -6.644E+01 | -1.125E+02 | 2.500E+00
5.00E+00 | 1.202E+01 | -6.622E+01 | -1.132E+02 | 2.500E+00
6.00E+00 | 1.259E+01 | -6.590E+01 | -1.107E+02 | 2.500E+00
7.00E+00 | 1.318E+01 | -6.530E+01 | -1.107E+02 | 2.500E+00
8.00E+00 | 1.380E+01 | -6.509E+01 | -1.093E+02 | 2.500E+00
9.00E+00 | 1.445E+01 | -6.509E+01 | -1.085E+02 | 2.500E+00
1.00E+01 | 1.514E+01 | -6.465E+01 | -1.077E+02 | 2.500E+00
1.10E+01 | 1.585E+01 | -6.439E+01 | -1.083E+02 | 2.500E+00
1.20E+01 | 1.660E+01 | -6.407E+01 | -1.067E+02 | 2.500E+00
1.30E+01 | 1.738E+01 | -6.345E+01 | -1.080E+02 | 2.500E+00
1.40E+01 | 1.820E+01 | -6.325E+01 | -1.058E+02 | 2.500E+00
1.50E+01 | 1.905E+01 | -6.287E+01 | -1.042E+02 | 2.500E+00
1.60E+01 | 1.995E+01 | -6.260E+01 | -1.052E+02 | 2.500E+00
1.70E+01 | 2.089E+01 | -6.210E+01 | -1.044E+02 | 2.500E+00
1.80E+01 | 2.188E+01 | -6.174E+01 | -1.044E+02 | 2.500E+00
1.90E+01 | 2.291E+01 | -6.140E+01 | -1.044E+02 | 2.500E+00
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

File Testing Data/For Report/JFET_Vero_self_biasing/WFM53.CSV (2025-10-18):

in Sa | Frequency in Hz | Gain in dB | Phase in ° | Amplitude in Vpp
1.00E+00 | 1.000E+01 | -6.762E+01 | -1.148E+02 | 2.500E+00
2.00E+00 | 1.047E+01 | -6.759E+01 | -1.149E+02 | 2.500E+00
3.00E+00 | 1.096E+01 | -6.696E+01 | -1.139E+02 | 2.500E+00
4.00E+00 | 1.148E+01 | -6.660E+01 | -1.116E+02 | 2.500E+00
5.00E+00 | 1.202E+01 | -6.633E+01 | -1.139E+02 | 2.500E+00
6.00E+00 | 1.259E+01 | -6.615E+01 | -1.105E+02 | 2.500E+00
7.00E+00 | 1.318E+01 | -6.578E+01 | -1.098E+02 | 2.500E+00
8.00E+00 | 1.380E+01 | -6.544E+01 | -1.095E+02 | 2.500E+00
9.00E+00 | 1.445E+01 | -6.492E+01 | -1.088E+02 | 2.500E+00
1.00E+01 | 1.514E+01 | -6.495E+01 | -1.066E+02 | 2.500E+00
1.10E+01 | 1.585E+01 | -6.428E+01 | -1.061E+02 | 2.500E+00
1.20E+01 | 1.660E+01 | -6.413E+01 | -1.068E+02 | 2.500E+00
1.30E+01 | 1.738E+01 | -6.362E+01 | -1.072E+02 | 2.500E+00
1.40E+01 | 1.820E+01 | -6.310E+01 | -1.056E+02 | 2.500E+00
1.50E+01 | 1.905E+01 | -6.306E+01 | -1.036E+02 | 2.500E+00
1.60E+01 | 1.995E+01 | -6.234E+01 | -1.033E+02 | 2.500E+00
1.70E+01 | 2.089E+01 | -6.203E+01 | -1.053E+02 | 2.500E+00
1.80E+01 | 2.188E+01 | -6.182E+01 | -1.040E+02 | 2.500E+00
1.90E+01 | 2.291E+01 | -6.140E+01 | -1.029E+02 | 2.500E+00
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

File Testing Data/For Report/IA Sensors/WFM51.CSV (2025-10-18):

in Sa | Frequency in Hz | Gain in dB | Phase in ° | Amplitude in Vpp
1.00E+00 | 1.000E+01 | -4.485E+01 | 8.358E+01 | 2.500E+00
2.00E+00 | 1.047E+01 | -4.478E+01 | 8.050E+01 | 2.500E+00
3.00E+00 | 1.096E+01 | -4.239E+01 | 8.506E+01 | 2.500E+00
4.00E+00 | 1.148E+01 | -4.364E+01 | 8.020E+01 | 2.500E+00
5.00E+00 | 1.202E+01 | -4.274E+01 | 8.212E+01 | 2.500E+00
6.00E+00 | 1.259E+01 | -4.201E+01 | 9.238E+01 | 2.500E+00
7.00E+00 | 1.318E+01 | -4.191E+01 | 8.723E+01 | 2.500E+00
8.00E+00 | 1.380E+01 | -4.248E+01 | 8.443E+01 | 2.500E+00
9.00E+00 | 1.445E+01 | -4.073E+01 | 8.593E+01 | 2.500E+00
1.00E+01 | 1.514E+01 | -4.068E+01 | 8.590E+01 | 2.500E+00
1.10E+01 | 1.585E+01 | -3.974E+01 | 8.017E+01 | 2.500E+00
1.20E+01 | 1.660E+01 | -3.976E+01 | 8.354E+01 | 2.500E+00
1.30E+01 | 1.738E+01 | -3.928E+01 | 8.246E+01 | 2.500E+00
1.40E+01 | 1.820E+01 | -3.905E+01 | 8.671E+01 | 2.500E+00
1.50E+01 | 1.905E+01 | -3.947E+01 | 8.507E+01 | 2.500E+00
1.60E+01 | 1.995E+01 | -3.730E+01 | 8.519E+01 | 2.500E+00
1.70E+01 | 2.089E+01 | -3.698E+01 | 8.690E+01 | 2.500E+00
1.80E+01 | 2.188E+01 | -3.729E+01 | 8.694E+01 | 2.500E+00
1.90E+01 | 2.291E+01 | -3.650E+01 | 8.458E+01 | 2.500E+00
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

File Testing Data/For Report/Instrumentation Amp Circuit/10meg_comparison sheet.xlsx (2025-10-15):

10Hz | 1Meg |  | 10Meg |  | 50Hz | 1Meg |  | 10Meg |  | 100Hz | 1Meg |  | 10Meg |  | 500Hz | 1Meg |  | 10Meg |  | 1kHz | 1Meg |  | 10Meg
x-axis | input 1 | output 1 | input 2 | output 2 | x-axis | input 1 | output 1 | input 2 | output 2 | x-axis | input 1 | output 1 | input 2 | output 2 | x-axis | input 1 | output 1 | input 2 | output 2 | x-axis | input 1 | output 1 | input 2 | output 2
second | Volt | Volt | Volt | Volt | second | Volt | Volt | Volt | Volt | second | Volt | Volt | Volt | Volt | second | Volt | Volt | Volt | Volt | second | Volt | Volt | Volt | Volt
-0.5 | -0.00625 | 1.72E-02 | 0.00625 | -0.05 | -0.1 | 0.0015625 | 0.0640625 | -6.25e-05 | -0.04375 | -0.05 | -0.004688 | 0.057813 | -0.000313 | 0.015625 | -0.01 | 0.00125 | 0.08125 | 0.0003125 | -0.6875 | -0.01 | -0.00625 | 0.140625 | 0.0003125 | -0.5
-0.499 | -0.0125 | 1.72E-02 | 0.01875 | -0.0375 | -0.0998 | -0.0015625 | 0.065625 | -0.000125 | 0 | -0.0499 | -0.004688 | 0.0625 | -0.000125 | 0.0625 | -0.00998 | -0.000625 | 0.11875 | 0 | -0.75 | -0.00998 | -0.0125 | 0.21875 | 0 | -0.6875
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

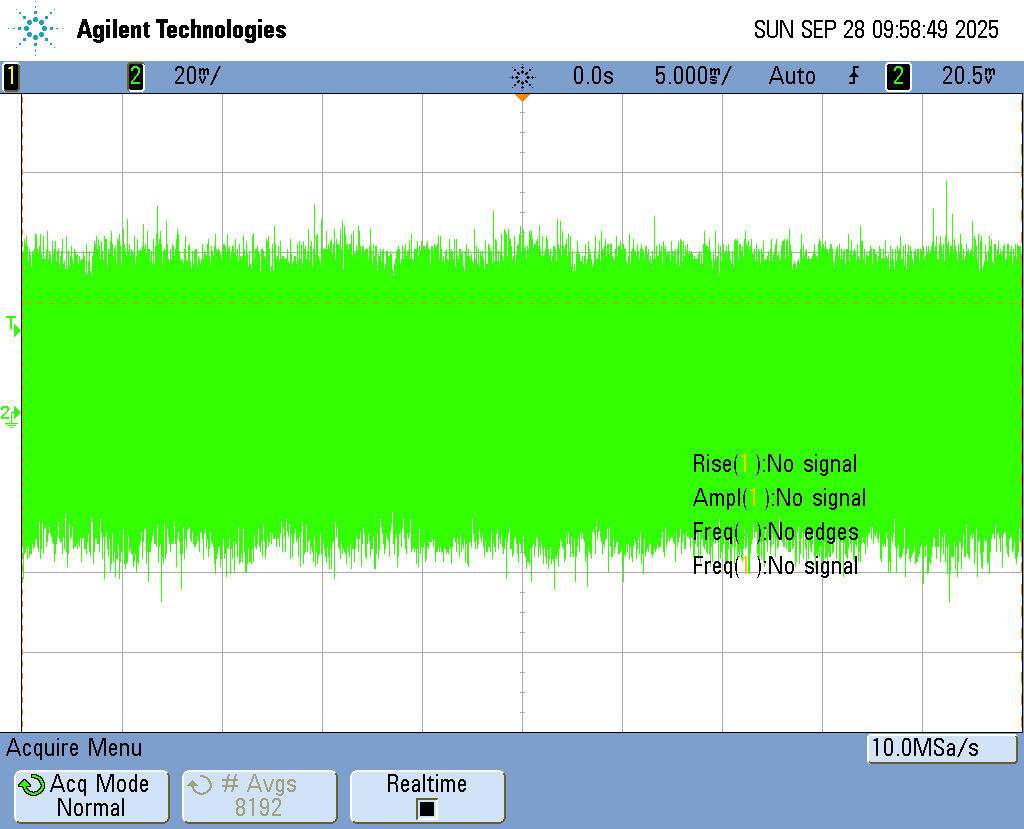
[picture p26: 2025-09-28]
Testing Data/For Report/Crystal 16MHz/cry2/cry2_200.png

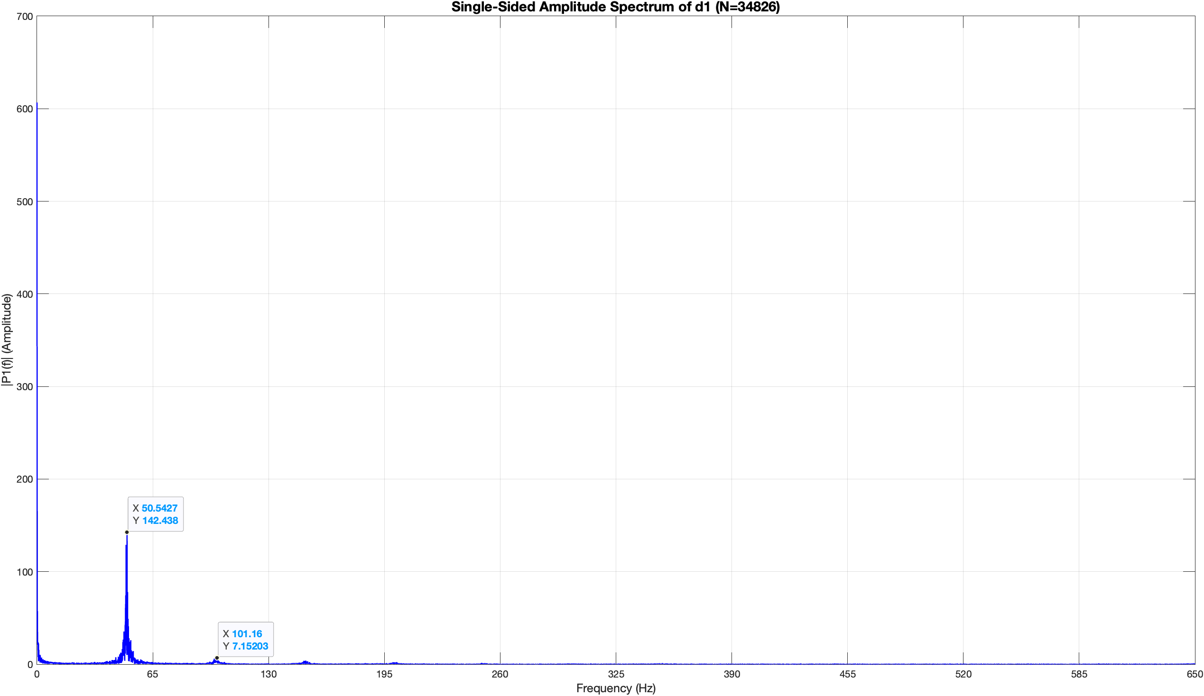
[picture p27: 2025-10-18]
Testing Data/Bee_Hive_Test/Graphs For Report/beetest_6_d1.png

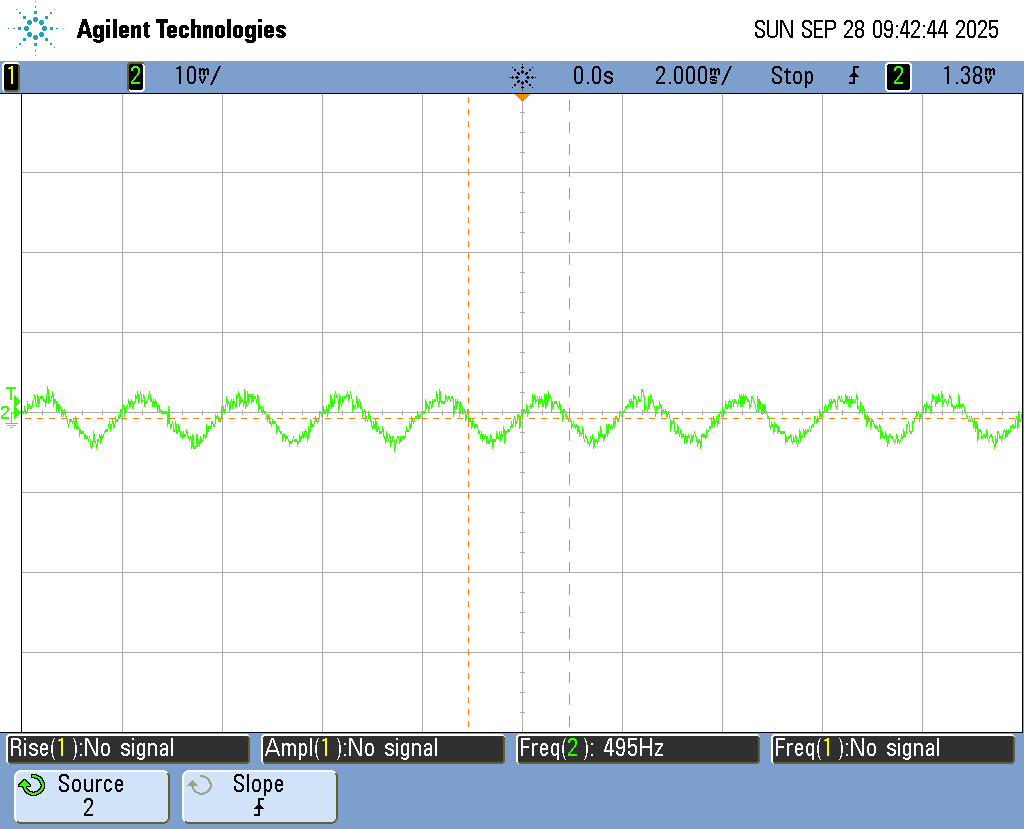
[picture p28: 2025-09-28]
Testing Data/For Report/Crystal 16MHz/cry1/cry1_500.png

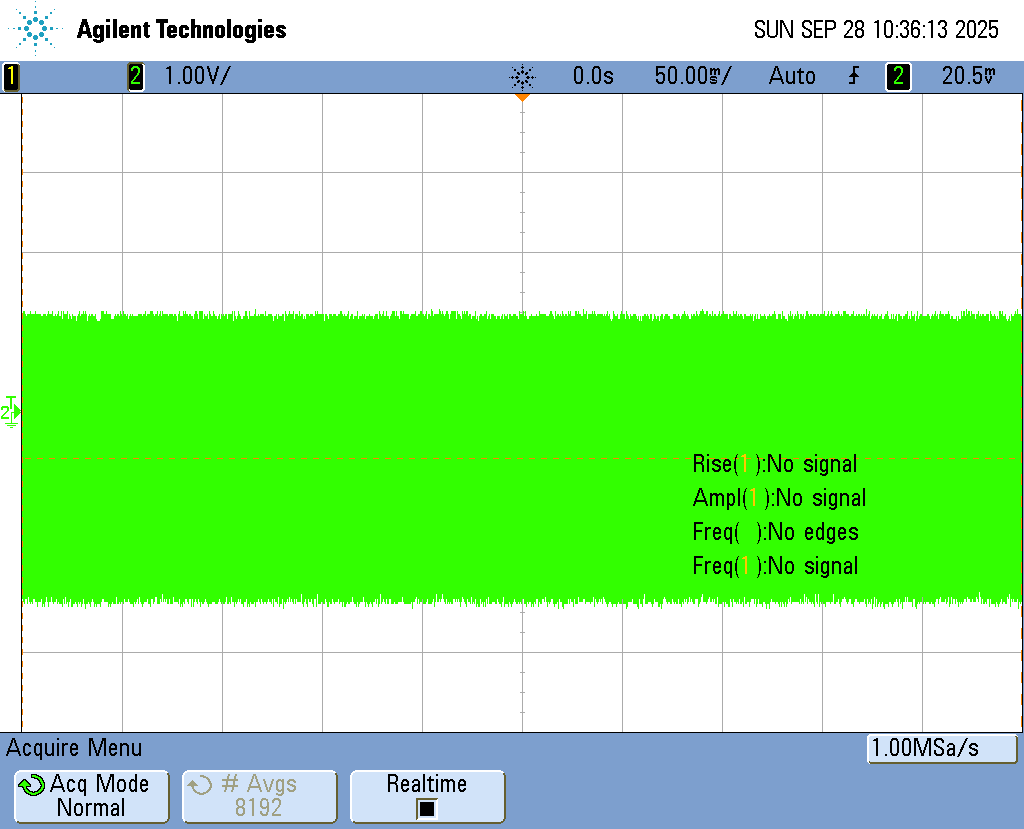
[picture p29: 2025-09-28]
Testing Data/For Report/Crystal 16MHz/cry4/cry4_15.png

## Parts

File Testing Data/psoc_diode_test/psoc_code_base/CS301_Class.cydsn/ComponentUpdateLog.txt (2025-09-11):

Last Modified Date & Time: 07/17/2021 00:56:57

CS301_Class: CS301_Class.cydwr
	cy_boot [v5.40] to [v5.82]
	Em_EEPROM_Dynamic [v2.0] to [v2.20]
	LIN_Dynamic [v3.40] to [v5.0]

CS301_Class: TopDesign.cysch
	ADC [v2.0] to [v2.10]
	isr_eoc [v1.70] to [v1.71]
	isr_TS [v1.70] to [v1.71]
	isrRF_RX [v1.70] to [v1.71]
	isrRF_TX [v1.70] to [v1.71]
	Timer_TS [v2.70] to [v2.80]
	USBUART [v3.0] to [v3.20]

Last Modified Date & Time: 09/11/2025 18:48:17

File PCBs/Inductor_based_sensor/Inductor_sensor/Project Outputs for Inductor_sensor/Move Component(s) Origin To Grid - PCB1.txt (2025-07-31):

Move Component(s) Origin to Grid
Filename     : C:\Users\ash750\OneDrive - The University of Auckland\Documents\GitHub\project-team-04\altium\PCB_Project_v2\PCB_Project_v2\PCB1.PcbDoc
Date         : 31/07/2025
Time         : 10:28:19 AM
Time Elapsed : 00:00:00

    SMT Small Component S20-sensor (229.362mm,33.655mm) on Top Layer - Component origin is already ON grid.
    SMT Small Component S19-sensor (214.757mm,33.655mm) on Top Layer - Component origin is already ON grid.
    SMT Small Component S18-sensor (200.279mm,33.655mm) on Top Layer - Component origin is already ON grid.
    SMT Small Component S17-sensor (185.801mm,33.655mm) on Top Layer - Component origin is already ON grid.
    SMT Small Component S16-sensor (315.595mm,33.655mm) on Top Layer - Component origin is already ON grid.
    SMT Small Component S15-sensor (301.117mm,33.655mm) on Top Layer - Component origin is already ON grid.
    SMT Small Component S14-sensor (286.639mm,33.655mm) on Top Layer - Component origin is already ON grid.
    SMT Small Component S13-sensor (272.034mm,33.655mm) on Top Layer - Component origin is already ON grid.
    SMT Small Component S12-sensor (409.829mm,33.655mm) on Top Layer - Component origin is already ON grid.
    SMT Small Component S11-sensor (395.351mm,33.655mm) on Top Layer - Component origin is already ON grid.
    SMT Small Component S10-sensor (380.746mm,33.655mm) on Top Layer - Component origin is already ON grid.
    SMT Small Component S9-sensor (452.374mm,6.627mm) on Top Layer - Component pads are OFF grid. No action taken.
    SMT Small Component S8-sensor (493.395mm,33.655mm) on Top Layer - Component origin is already ON grid.
    SMT Small Component S7-sensor (478.917mm,33.655mm) on Top Layer - Component origin is already ON grid.
    SMT Small Component S6-sensor (464.439mm,33.655mm) on Top Layer - Component origin is already ON grid.
    SMT Small Component S5-sensor (132mm,100mm) on Top Layer - Component pads are OFF grid. No action taken.
    SMT Small Component S4-sensor (112mm,100mm) on Top Layer - Component pads are OFF grid. No action taken.
    SMT Small Component S3-sensor (92mm,100mm) on Top Layer - Component pads are OFF grid. No action taken.
    SMT Small Component S2-sensor (72mm,100mm) on Top Layer - Component pads are OFF grid. No action taken.
    SMT Small Component S1-sensor (52mm,100mm) on Top Layer - Component pads are OFF grid. No action taken.
    SMT Small Component R20-* (260.604mm,38.481mm) on Top Layer - Component origin is already ON grid. - Component pads are OFF grid. No action taken.
    SMT Small Component R19-* (255.905mm,39.37mm) on Top Layer - Component origin is already ON grid. - Component pads are OFF grid. No action taken.
    SMT Small Component R18-* (250.317mm,39.37mm) on Top Layer - Component origin is already ON grid. - Component pads are OFF grid. No action taken.
    SMT Small Component R17-* (244.729mm,39.37mm) on Top Layer - Component origin is already ON grid. - Component pads are OFF grid. No action taken.
    SMT Small Component R16-* (239.141mm,39.37mm) on Top Layer - Component origin is already ON grid. - Component pads are OFF grid. No action taken.
    SMT Small Component R15-* (347.218mm,39.37mm) on Top Layer - Component origin is already ON grid. - Component pads are OFF grid. No action taken.
    SMT Small Component R14-* (341.63mm,39.37mm) on Top Layer - Component origin is already ON grid. - Component pads are OFF grid. No action taken.
    SMT Small Component R13-* (336.042mm,39.37mm) on Top Layer - Component origin is already ON grid. - Component pads are OFF grid. No action taken.
    SMT Small Component R12-* (330.454mm,39.37mm) on Top Layer - Component origin is already ON grid. - Component pads are OFF grid. No action taken.
    SMT Small Component R11-* (325.374mm,39.37mm) on Top Layer - Component origin is already ON grid. - Component pads are OFF grid. No action taken.
    SMT Small Component R10-* (439.42mm,39.37mm) on Top Layer - Component origin is already ON grid. - Component pads are OFF grid. No action taken.
    SMT Small Component R9-* (434.467mm,39.37mm) on Top Layer - Component origin is already ON grid. - Component pads are OFF grid. No action taken.
    SMT Small Component R8-* (429.514mm,39.37mm) on Top Layer - Component origin is already ON grid. - Component pads are OFF grid. No action taken.
    SMT Small Component R7-* (424.561mm,39.37mm) on Top Layer - Component origin is already ON grid. - Component pads are OFF grid. No action taken.
    SMT Small Component R6-* (419.608mm,39.37mm) on Top Layer - Component origin is already ON grid. - Component pads are OFF grid. No action taken.
    SMT Small Component R5-* (132.969mm,112.522mm) on Top Layer - Component origin is already ON grid. - Component pads are OFF grid. No action taken.
    SMT Small Component R4-* (113.141mm,112.522mm) on Top Layer - Component pads are OFF grid. No action taken.
    SMT Small Component R3-* (92.821mm,112.649mm) on Top Layer - Component pads are OFF grid. No action taken.
    SMT Small Component R2-* (71.644mm,112.268mm) on Top Layer - Component pads are OFF grid. No action taken.
    SMT Small Component R1-* (53.086mm,111.887mm) on Top Layer - Component origin is already ON grid. - Component pads are OFF grid. No action taken.
    SIP Component H4-Header (352.298mm,28.829mm) on Top Layer - Component origin is already ON grid.
    SIP Component H3-Header (356.616mm,28.829mm) on Top Layer - Component origin is already ON grid.
    SIP Component H2-Header (502.539mm,28.829mm) on Top Layer - Component origin is already ON grid.
    SIP Component H1-Header (86.741mm,119.126mm) on Top Layer - Component origin is already ON grid.
count : 44

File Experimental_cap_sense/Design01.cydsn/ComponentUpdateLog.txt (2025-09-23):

Last Modified Date & Time: 05/10/2025 16:59:18

Design01_Copy_01: Design01_Copy_01.cydwr
	cy_boot [v6.10] to [v5.82]

Last Modified Date & Time: 05/11/2025 23:08:35

Design01_Copy_01: Design01_Copy_01.cydwr
	cy_boot [v5.82] to [v6.10]

Last Modified Date & Time: 08/05/2025 14:51:23

Design01_Copy_01: Design01_Copy_01.cydwr
	cy_boot [v5.82] to [v6.10]

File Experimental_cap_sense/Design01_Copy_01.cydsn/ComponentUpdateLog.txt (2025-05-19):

Last Modified Date & Time: 05/12/2025 14:21:15

Design01_Copy_01: Design01_Copy_01.cydwr
	cy_boot [v6.10] to [v5.82]

Design01_Copy_01: TopDesign.cysch
	isr_schmitt [v1.70] to [v1.71]

Last Modified Date & Time: 05/12/2025 14:43:41

Design01: Design01.cydwr
	cy_boot [v6.10] to [v5.82]

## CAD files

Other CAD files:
CoreXY/GT2 Timing Pulley 20T 10mm - Bore_5mm v8.f3d
CoreXY/core xy v77.f3d

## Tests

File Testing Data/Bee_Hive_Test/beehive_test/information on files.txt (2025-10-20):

# Beehive Test Data Folder Contents

## Preliminary Test Runs (Deprecated)
- beetest_1: Test run, not important.
- beetest_2: Test run, not important.
- beetest_3: Test run, not important.
- beetest_4: Test run, not important.

## BeeSpy Sensor Tests (PuTTY Logs)
- beetest_5: BeeSpy FET sensor test.
- beetest_6: BeeSpy Electret sensor test.
- beetest_5_out: Processed output from beetest_5.
- beetest_6_out: Processed output from beetest_6.

## Capacitive Sensor Array Tests (Oscilloscope Waveforms)
- WFM059: CH1 (Centre)
- WFM60: CH1 (Centre) & CH2 (Top Left)
- WFM54: CH1 (Bottom Left) & CH2 (Top Right)
- WFM55: CH1 (Bottom Left) & CH2 (Top Right)
- WFM56: CH1 (Bottom Right) & CH2 (Centre) % Note: CH1 has an offset of -6
- WFM57: CH1 (Bottom Right) & CH2 (Centre)

## Utilities
- convert/convert.py: Python script used to convert the PuTTY data (beetest_5, beetest_6) 
    into a CSV format for processing in MATLAB.

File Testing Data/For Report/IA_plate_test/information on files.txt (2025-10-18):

file contain bode plot data for 25 IA sensor board, on three of the bottom ones are collected, from bottom right
65 - ch1 (bott bottom)
66 - ch2
67 - ch3 bottom row centre

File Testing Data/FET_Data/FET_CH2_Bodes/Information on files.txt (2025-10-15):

WFM08 - FET 10Hz - 10kHz
WFM09 - FET 10Hz- 10kHz 
WFM10 - FET 10Hz- 10kHz 
WFM11 - FET 10Hz- 200kHz 

Same setup as before just different channel

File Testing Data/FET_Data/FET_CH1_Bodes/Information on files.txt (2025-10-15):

WFM08 - FET 10Hz - 10kHz
WFM09 - FET 10Hz- 10kHz 
WFM10 - FET 10Hz- 200kHz

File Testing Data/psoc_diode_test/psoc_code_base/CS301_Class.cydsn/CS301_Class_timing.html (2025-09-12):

# Static Timing Analysis

Project : | CS301_Class
Build Time : | 09/12/25 11:20:33
Device : | CY8C5888LTI-LP097
Temperature : | -40C - 85/125C
VDDA : | 5.00
VDDABUF : | 5.00
VDDD : | 5.00
VDDIO0 : | 5.00
VDDIO1 : | 5.00
VDDIO2 : | 5.00
VDDIO3 : | 5.00
VUSB : | 5.00
Voltage : | 5.0

Expand All | Collapse All | Show All Paths | Hide All Paths

+ Timing Violation Section

No Timing Violations

+ Clock Summary Section

Clock | Domain | Nominal Frequency | Required Frequency | Maximum Frequency | Violation
ClockBlock/aclk_glb_ff_0 | ClockBlock/aclk_glb_ff_0 | UNKNOWN | UNKNOWN | N/A
ClockBlock/dclk_glb_ff_1 | ClockBlock/dclk_glb_ff_1 | UNKNOWN | UNKNOWN | N/A
CyILO | CyILO | 100.000 kHz | 100.000 kHz | N/A
CyIMO | CyIMO | 24.000 MHz | 24.000 MHz | N/A
CyMASTER_CLK | CyMASTER_CLK | 60.000 MHz | 60.000 MHz | N/A
CyBUS_CLK | CyMASTER_CLK | 60.000 MHz | 60.000 MHz | 68.185 MHz
ADC_SAR_1_theACLK | CyMASTER_CLK | 1.579 MHz | 1.579 MHz | N/A
UART_IntClock | CyMASTER_CLK | 461.538 kHz | 461.538 kHz | 52.809 MHz
Clock2 | CyMASTER_CLK | 100.000 kHz | 100.000 kHz | N/A
CyPLL_OUT | CyPLL_OUT | 60.000 MHz | 60.000 MHz | N/A

+ Register to Register Section

+ Setup Subsection

+ Source Clock : CyBUS_CLK : Positive edge(Required Frequency 60 MHz)

+ Destination Clock : UART_IntClock : Positive edge(Required Frequency 461.538 kHz)

Path Delay Requirement : 16.6667ns(60 MHz)

Affects clock : CyMASTER_CLK

Source | Destination | FMax | Delay (ns) | Slack (ns) | Violation
\RF_BT_SELECT:Sync:ctrl_reg\/control_0 | \UART:BUART:rx_state_0\/main_3 | 68.185 MHz | 14.666 | 2.001

Type | Location | Fanout | Instance/Net | Source | Dest | Delay (ns)
controlcell1 | U(1,4) | 1 | \RF_BT_SELECT:Sync:ctrl_reg\ | \RF_BT_SELECT:Sync:ctrl_reg\/busclk | \RF_BT_SELECT:Sync:ctrl_reg\/control_0 | 2.050
Route | | 1 | Net_3437 | \RF_BT_SELECT:Sync:ctrl_reg\/control_0 | \UART:BUART:rx_postpoll\/main_2 | 3.471
macrocell6 | U(1,5) | 1 | \UART:BUART:rx_postpoll\ | \UART:BUART:rx_postpoll\/main_2 | \UART:BUART:rx_postpoll\/q | 3.350
Route | | 1 | \UART:BUART:rx_postpoll\ | \UART:BUART:rx_postpoll\/q | \UART:BUART:rx_state_0\/main_3 | 2.285
macrocell16 | U(1,5) | 1 | \UART:BUART:rx_state_0\ | | SETUP | 3.510
Clock | | | | | Skew | 0.000
\RF_BT_SELECT:Sync:ctrl_reg\/control_0 | \UART:BUART:rx_status_3\/main_3 | 68.185 MHz | 14.666 | 2.001

Type | Location | Fanout | Instance/Net | Source | Dest | Delay (ns)
controlcell1 | U(1,4) | 1 | \RF_BT_SELECT:Sync:ctrl_reg\ | \RF_BT_SELECT:Sync:ctrl_reg\/busclk | \RF_BT_SELECT:Sync:ctrl_reg\/control_0 | 2.050
Route | | 1 | Net_3437 | \RF_BT_SELECT:Sync:ctrl_reg\/control_0 | \UART:BUART:rx_postpoll\/main_2 | 3.471
macrocell6 | U(1,5) | 1 | \UART:BUART:rx_postpoll\ | \UART:BUART:rx_postpoll\/main_2 | \UART:BUART:rx_postpoll\/q | 3.350
Route | | 1 | \UART:BUART:rx_postpoll\ | \UART:BUART:rx_postpoll\/q | \UART:BUART:rx_status_3\/main_3 | 2.285
macrocell24 | U(1,5) | 1 | \UART:BUART:rx_status_3\ | | SETUP | 3.510
Clock | | | | | Skew | 0.000
\RF_BT_SELECT:Sync:ctrl_reg\/control_0 | \UART:BUART:sRX:RxShifter:u0\/route_si | 68.245 MHz | 14.653 | 2.014

Type | Location | Fanout | Instance/Net | Source | Dest | Delay (ns)
controlcell1 | U(1,4) | 1 | \RF_BT_SELECT:Sync:ctrl_reg\ | \RF_BT_SELECT:Sync:ctrl_reg\/busclk | \RF_BT_SELECT:Sync:ctrl_reg\/control_0 | 2.050
Route | | 1 | Net_3437 | \RF_BT_SELECT:Sync:ctrl_reg\/control_0 | \UART:BUART:rx_postpoll\/main_2 | 3.471
macrocell6 | U(1,5) | 1 | \UART:BUART:rx_postpoll\ | \UART:BUART:rx_postpoll\/main_2 | \UART:BUART:rx_postpoll\/q | 3.350
Route | | 1 | \UART:BUART:rx_postpoll\ | \UART:BUART:rx_postpoll\/q | \UART:BUART:sRX:RxShifter:u0\/route_si | 2.312
datapathcell3 | U(1,5) | 1 | \UART:BUART:sRX:RxShifter:u0\ | | SETUP | 3.470
Clock | | | | | Skew | 0.000
Rx_2(0)_SYNC/out | \UART:BUART:rx_state_0\/main_3 | 70.131 MHz | 14.259 | 2.408

Type | Location | Fanout | Instance/Net | Source | Dest | Delay (ns)
synccell | U(0,4) | 1 | Rx_2(0)_SYNC | Rx_2(0)_SYNC/clock | Rx_2(0)_SYNC/out | 1.020
Route | | 1 | Net_3405_SYNCOUT | Rx_2(0)_SYNC/out | \UART:BUART:rx_postpoll\/main_4 | 4.094
macrocell6 | U(1,5) | 1 | \UART:BUART:rx_postpoll\ | \UART:BUART:rx_postpoll\/main_4 | \UART:BUART:rx_postpoll\/q | 3.350
Route | | 1 | \UART:BUART:rx_postpoll\ | \UART:BUART:rx_postpoll\/q | \UART:BUART:rx_state_0\/main_3 | 2.285
macrocell16 | U(1,5) | 1 | \UART:BUART:rx_state_0\ | | SETUP | 3.510
Clock | | | | | Skew | 0.000
Rx_2(0)_SYNC/out | \UART:BUART:rx_status_3\/main_3 | 70.131 MHz | 14.259 | 2.408

Type | Location | Fanout | Instance/Net | Source | Dest | Delay (ns)
synccell | U(0,4) | 1 | Rx_2(0)_SYNC | Rx_2(0)_SYNC/clock | Rx_2(0)_SYNC/out | 1.020
Route | | 1 | Net_3405_SYNCOUT | Rx_2(0)_SYNC/out | \UART:BUART:rx_postpoll\/main_4 | 4.094
macrocell6 | U(1,5) | 1 | \UART:BUART:rx_postpoll\ | \UART:BUART:rx_postpoll\/main_4 | \UART:BUART:rx_postpoll\/q | 3.350
Route | | 1 | \UART:BUART:rx_postpoll\ | \UART:BUART:rx_postpoll\/q | \UART:BUART:rx_status_3\/main_3 | 2.285
macrocell24 | U(1,5) | 1 | \UART:BUART:rx_status_3\ | | SETUP | 3.510
Clock | | | | | Skew | 0.000
Rx_2(0)_SYNC/out | \UART:BUART:sRX:RxShifter:u0\/route_si | 70.195 MHz | 14.246 | 2.421

Type | Location | Fanout | Instance/Net | Source | Dest | Delay (ns)
synccell | U(0,4) | 1 | Rx_2(0)_SYNC | Rx_2(0)_SYNC/clock | Rx_2(0)_SYNC/out | 1.020
Route | | 1 | Net_3405_SYNCOUT | Rx_2(0)_SYNC/out | \UART:BUART:rx_postpoll\/main_4 | 4.094
macrocell6 | U(1,5) | 1 | \UART:BUART:rx_postpoll\ | \UART:BUART:rx_postpoll\/main_4 | \UART:BUART:rx_postpoll\/q | 3.350
Route | | 1 | \UART:BUART:rx_postpoll\ | \UART:BUART:rx_postpoll\/q | \UART:BUART:sRX:RxShifter:u0\/route_si | 2.312
datapathcell3 | U(1,5) | 1 | \UART:BUART:sRX:RxShifter:u0\ | | SETUP | 3.470
Clock | | | | | Skew | 0.000
Rx_1(0)_SYNC/out | \UART:BUART:rx_state_0\/main_3 | 77.991 MHz | 12.822 | 3.845

Type | Location | Fanout | Instance/Net | Source | Dest | Delay (ns)
synccell | U(0,5) | 1 | Rx_1(0)_SYNC | Rx_1(0)_SYNC/clock | Rx_1(0)_SYNC/out | 1.020
Route | | 1 | Net_3438_SYNCOUT | Rx_1(0)_SYNC/out | \UART:BUART:rx_postpoll\/main_3 | 2.657
macrocell6 | U(1,5) | 1 | \UART:BUART:rx_postpoll\ | \UART:BUART:rx_postpoll\/main_3 | \UART:BUART:rx_postpoll\/q | 3.350
Route | | 1 | \UART:BUART:rx_postpoll\ | \UART:BUART:rx_postpoll\/q | \UART:BUART:rx_state_0\/main_3 | 2.285
macrocell16 | U(1,5) | 1 | \UART:BUART:rx_state_0\ | | SETUP | 3.510
Clock | | | | | Skew | 0.000
Rx_1(0)_SYNC/out | \UART:BUART:rx_status_3\/main_3 | 77.991 MHz | 12.822 | 3.845

Type | Location | Fanout | Instance/Net | Source | Dest | Delay (ns)
synccell | U(0,5) | 1 | Rx_1(0)_SYNC | Rx_1(0)_SYNC/clock | Rx_1(0)_SYNC/out | 1.020
Route | | 1 | Net_3438_SYNCOUT | Rx_1(0)_SYNC/out | \UART:BUART:rx_postpoll\/main_3 | 2.657
macrocell6 | U(1,5) | 1 | \UART:BUART:rx_postpoll\ | \UART:BUART:rx_postpoll\/main_3 | \UART:BUART:rx_postpoll\/q | 3.350
Route | | 1 | \UART:BUART:rx_postpoll\ | \UART:BUART:rx_postpoll\/q | \UART:BUART:rx_status_3\/main_3 | 2.285
macrocell24 | U(1,5) | 1 | \UART:BUART:rx_status_3\ | | SETUP | 3.510
Clock | | | | | Skew | 0.000
Rx_1(0)_SYNC/out | \UART:BUART:sRX:RxShifter:u0\/route_si | 78.070 MHz | 12.809 | 3.858

Type | Location | Fanout | Instance/Net | Source | Dest | Delay (ns)
synccell | U(0,5) | 1 | Rx_1(0)_SYNC | Rx_1(0)_SYNC/clock | Rx_1(0)_SYNC/out | 1.020
Route | | 1 | Net_3438_SYNCOUT | Rx_1(0)_SYNC/out | \UART:BUART:rx_postpoll\/main_3 | 2.657
macrocell6 | U(1,5) | 1 | \UART:BUART:rx_postpoll\ | \UART:BUART:rx_postpoll\/main_3 | \UART:BUART:rx_postpoll\/q | 3.350
Route | | 1 | \UART:BUART:rx_postpoll\ | \UART:BUART:rx_postpoll\/q | \UART:BUART:sRX:RxShifter:u0\/route_si | 2.312
datapathcell3 | U(1,5) | 1 | \UART:BUART:sRX:RxShifter:u0\ | | SETUP | 3.470
Clock | | | | | Skew | 0.000
Rx_2(0)_SYNC/out | \UART:BUART:pollcount_0\/main_5 | 103.263 MHz | 9.684 | 6.983

Type | Location | Fanout | Instance/Net | Source | Dest | Delay (ns)
synccell | U(0,4) | 1 | Rx_2(0)_SYNC | Rx_2(0)_SYNC/clock | Rx_2(0)_SYNC/out | 1.020
Route | | 1 | Net_3405_SYNCOUT | Rx_2(0)_SYNC/out | \UART:BUART:pollcount_0\/main_5 | 5.154
macrocell23 | U(1,3) | 1 | \UART:BUART:pollcount_0\ | | SETUP | 3.510
Clock | | | | | Skew | 0.000

+ Source Clock : UART_IntClock : Positive edge(Required Frequency 461.538 kHz)

+ Destination Clock : UART_IntClock : Positive edge(Required Frequency 461.538 kHz)

Path Delay Requirement : 2166.67ns(461.538 kHz)

Source | Destination | FMax | Delay (ns) | Slack (ns) | Violation
\UART:BUART:tx_ctrl_mark_last\/q | \UART:BUART:sRX:RxBitCounter\/load | 52.809 MHz | 18.936 | 2147.731

Type | Location | Fanout | Instance/Net | Source | Dest | Delay (ns)
macrocell15 | U(1,3) | 1 | \UART:BUART:tx_ctrl_mark_last\ | \UART:BUART:tx_ctrl_mark_last\/clock_0 | \UART:BUART:tx_ctrl_mark_last\/q | 1.250
Route | | 1 | \UART:BUART:tx_ctrl_mark_last\ | \UART:BUART:tx_ctrl_mark_last\/q | \UART:BUART:rx_counter_load\/main_0 | 6.667
macrocell5 | U(1,5) | 1 | \UART:BUART:rx_counter_load\ | \UART:BUART:rx_counter_load\/main_0 | \UART:BUART:rx_counter_load\/q | 3.350
Route | | 1 | \UART:BUART:rx_counter_load\ | \UART:BUART:rx_counter_load\/q | \UART:BUART:sRX:RxBitCounter\/load | 2.309
count7cell | U(1,5) | 1 | \UART:BUART:sRX:RxBitCounter\ | | SETUP | 5.360
Clock | | | | | Skew | 0.000
\UART:BUART:tx_state_0\/q | \UART:BUART:sTX:sCLOCK:TxBitClkGen\/cs_addr_0 | 55.853 MHz | 17.904 | 2148.763

Type | Location | Fanout | Instance/Net | Source | Dest | Delay (ns)
macrocell12 | U(0,3) | 1 | \UART:BUART:tx_state_0\ | \UART:BUART:tx_state_0\/clock_0 | \UART:BUART:tx_state_0\/q | 1.250
Route | | 1 | \UART:BUART:tx_state_0\ | \UART:BUART:tx_state_0\/q | \UART:BUART:counter_load_not\/main_1 | 4.812
macrocell2 | U(0,4) | 1 | \UART:BUART:counter_load_not\ | \UART:BUART:counter_load_not\/main_1 | \UART:BUART:counter_load_not\/q | 3.350
Route | | 1 | \UART:BUART:counter_load_not\ | \UART:BUART:counter_load_not\/q | \UART:BUART:sTX:sCLOCK:TxBitClkGen\/cs_addr_0 | 2.302
datapathcell2 | U(0,4) | 1 | \UART:BUART:sTX:sCLOCK:TxBitClkGen\ | | SETUP | 6.190
Clock | | | | | Skew | 0.000
\UART:BUART:rx_state_3\/q | \UART:BUART:sRX:RxBitCounter\/load | 59.298 MHz | 16.864 | 2149.803

Type | Location | Fanout | Instance/Net | Source | Dest | Delay (ns)
macrocell18 | U(1,3) | 1 | \UART:BUART:rx_state_3\ | \UART:BUART:rx_state_3\/clock_0 | \UART:BUART:rx_state_3\/q | 1.250
Route | | 1 | \UART:BUART:rx_state_3\ | \UART:BUART:rx_state_3\/q | \UART:BUART:rx_counter_load\/main_2 | 4.595
macrocell5 | U(1,5) | 1 | \UART:BUART:rx_counter_load\ | \UART:BUART:rx_counter_load\/main_2 | \UART:BUART:rx_counter_load\/q | 3.350
Route | | 1 | \UART:BUART:rx_counter_load\ | \UART:BUART:rx_counter_load\/q | \UART:BUART:sRX:RxBitCounter\/load | 2.309
count7cell | U(1,5) | 1 | \UART:BUART:sRX:RxBitCounter\ | | SETUP | 5.360
Clock | | | | | Skew | 0.000
\UART:BUART:tx_state_1\/q | \UART:BUART:sTX:sCLOCK:TxBitClkGen\/cs_addr_0 | 63.012 MHz | 15.870 | 2150.797

Type | Location | Fanout | Instance/Net | Source | Dest | Delay (ns)
macrocell11 | U(0,4) | 1 | \UART:BUART:tx_state_1\ | \UART:BUART:tx_state_1\/clock_0 | \UART:BUART:tx_state_1\/q | 1.250
Route | | 1 | \UART:BUART:tx_state_1\ | \UART:BUART:tx_state_1\/q | \UART:BUART:counter_load_not\/main_0 | 2.778
macrocell2 | U(0,4) | 1 | \UART:BUART:counter_load_not\ | \UART:BUART:counter_load_not\/main_0 | \UART:BUART:counter_load_not\/q | 3.350
Route | | 1 | \UART:BUART:counter_load_not\ | \UART:BUART:counter_load_not\/q | \UART:BUART:sTX:sCLOCK:TxBitClkGen\/cs_addr_0 | 2.302
datapathcell2 | U(0,4) | 1 | \UART:BUART:sTX:sCLOCK:TxBitClkGen\ | | SETUP | 6.190
Clock | | | | | Skew | 0.000
\UART:BUART:tx_state_2\/q | \UART:BUART:sTX:sCLOCK:TxBitClkGen\/cs_addr_0 | 63.690 MHz | 15.701 | 2150.966

Type | Location | Fanout | Instance/Net | Source | Dest | Delay (ns)
macrocell13 | U(0,4) | 1 | \UART:BUART:tx_state_2\ | \UART:BUART:tx_state_2\/clock_0 | \UART:BUART:tx_state_2\/q | 1.250
Route | | 1 | \UART:BUART:tx_state_2\ | \UART:BUART:tx_state_2\/q | \UART:BUART:counter_load_not\/main_3 | 2.609
macrocell2 | U(0,4) | 1 | \UART:BUART:counter_load_not\ | \UART:BUART:counter_load_not\/main_3 | \UART:BUART:counter_load_not\/q | 3.350
Route | | 1 | \UART:BUART:counter_load_not\ | \UART:BUART:counter_load_not\/q | \UART:BUART:sTX:sCLOCK:TxBitClkGen\/cs_addr_0 | 2.302
datapathcell2 | U(0,4) | 1 | \UART:BUART:sTX:sCLOCK:TxBitClkGen\ | | SETUP | 6.190
Clock | | | | | Skew | 0.000
\UART:BUART:rx_state_2\/q | \UART:BUART:sRX:RxBitCounter\/load | 63.873 MHz | 15.656 | 2151.011

Type | Location | Fanout | Instance/Net | Source | Dest | Delay (ns)
macrocell19 | U(1,4) | 1 | \UART:BUART:rx_state_2\ | \UART:BUART:rx_state_2\/clock_0 | \UART:BUART:rx_state_2\/q | 1.250
Route | | 1 | \UART:BUART:rx_state_2\ | \UART:BUART:rx_state_2\/q | \UART:BUART:rx_counter_load\/main_3 | 3.387
macrocell5 | U(1,5) | 1 | \UART:BUART:rx_counter_load\ | \UART:BUART:rx_counter_load\/main_3 | \UART:BUART:rx_counter_load\/q | 3.350
Route | | 1 | \UART:BUART:rx_counter_load\ | \UART:BUART:rx_counter_load\/q | \UART:BUART:sRX:RxBitCounter\/load | 2.309
count7cell | U(1,5) | 1 | \UART:BUART:sRX:RxBitCounter\ | | SETUP | 5.360
Clock | | | | | Skew | 0.000
\UART:BUART:sRX:RxShifter:u0\/f0_blk_stat_comb | \UART:BUART:sRX:RxSts\/status_4 | 64.205 MHz | 15.575 | 2151.092

Type | Location | Fanout | Instance/Net | Source | Dest | Delay (ns)
datapathcell3 | U(1,5) | 1 | \UART:BUART:sRX:RxShifter:u0\ | \UART:BUART:sRX:RxShifter:u0\/clock | \UART:BUART:sRX:RxShifter:u0\/f0_blk_stat_comb | 3.580
Route | | 1 | \UART:BUART:rx_fifofull\ | \UART:BUART:sRX:RxShifter:u0\/f0_blk_stat_comb | \UART:BUART:rx_status_4\/main_1 | 2.303
macrocell7 | U(1,5) | 1 | \UART:BUART:rx_status_4\ | \UART:BUART:rx_status_4\/main_1 | \UART:BUART:rx_status_4\/q | 3.350
Route | | 1 | \UART:BUART:rx_status_4\ | \UART:BUART:rx_status_4\/q | \UART:BUART:sRX:RxSts\/status_4 | 5.842
statusicell2 | U(1,4) | 1 | \UART:BUART:sRX:RxSts\ | | SETUP | 0.500
Clock | | | | | Skew | 0.000
\UART:BUART:sTX:sCLOCK:TxBitClkGen\/ce0_reg | \UART:BUART:sTX:sCLOCK:TxBitClkGen\/cs_addr_0 | 66.124 MHz | 15.123 | 2151.544

Type | Location | Fanout | Instance/Net | Source | Dest | Delay (ns)
datapathcell2 | U(0,4) | 1 | \UART:BUART:sTX:sCLOCK:TxBitClkGen\ | \UART:BUART:sTX:sCLOCK:TxBitClkGen\/clock | \UART:BUART:sTX:sCLOCK:TxBitClkGen\/ce0_reg | 0.190
Route | | 1 | \UART:BUART:tx_bitclk_enable_pre\ | \UART:BUART:sTX:sCLOCK:TxBitClkGen\/ce0_reg | \UART:BUART:counter_load_not\/main_2 | 3.091
macrocell2 | U(0,4) | 1 | \UART:BUART:counter_load_not\ | \UART:BUART:counter_load_not\/main_2 | \UART:BUART:counter_load_not\/q | 3.350
Route | | 1 | \UART:BUART:counter_load_not\ | \UART:BUART:counter_load_not\/q | \UART:BUART:sTX:sCLOCK:TxBitClkGen\/cs_addr_0 | 2.302
datapathcell2 | U(0,4) | 1 | \UART:BUART:sTX:sCLOCK:TxBitClkGen\ | | SETUP | 6.190
Clock | | | | | Skew | 0.000
\UART:BUART:rx_state_0\/q | \UART:BUART:sRX:RxBitCounter\/load | 66.423 MHz | 15.055 | 2151.612

Type | Location | Fanout | Instance/Net | Source | Dest | Delay (ns)
macrocell16 | U(1,5) | 1 | \UART:BUART:rx_state_0\ | \UART:BUART:rx_state_0\/clock_0 | \UART:BUART:rx_state_0\/q | 1.250
Route | | 1 | \UART:BUART:rx_state_0\ | \UART:BUART:rx_state_0\/q | \UART:BUART:rx_counter_load\/main_1 | 2.786
macrocell5 | U(1,5) | 1 | \UART:BUART:rx_counter_load\ | \UART:BUART:rx_counter_load\/main_1 | \UART:BUART:rx_counter_load\/q | 3.350
Route | | 1 | \UART:BUART:rx_counter_load\ | \UART:BUART:rx_counter_load\/q | \UART:BUART:sRX:RxBitCounter\/load | 2.309
count7cell | U(1,5) | 1 | \UART:BUART:sRX:RxBitCounter\ | | SETUP | 5.360
Clock | | | | | Skew | 0.000
\UART:BUART:rx_load_fifo\/q | \UART:BUART:sRX:RxSts\/status_4 | 67.815 MHz | 14.746 | 2151.921

Type | Location | Fanout | Instance/Net | Source | Dest | Delay (ns)
macrocell17 | U(1,4) | 1 | \UART:BUART:rx_load_fifo\ | \UART:BUART:rx_load_fifo\/clock_0 | \UART:BUART:rx_load_fifo\/q | 1.250
Route | | 1 | \UART:BUART:rx_load_fifo\ | \UART:BUART:rx_load_fifo\/q | \UART:BUART:rx_status_4\/main_0 | 3.804
macrocell7 | U(1,5) | 1 | \UART:BUART:rx_status_4\ | \UART:BUART:rx_status_4\/main_0 | \UART:BUART:rx_status_4\/q | 3.350
Route | | 1 | \UART:BUART:rx_status_4\ | \UART:BUART:rx_status_4\/q | \UART:BUART:sRX:RxSts\/status_4 | 5.842
statusicell2 | U(1,4) | 1 | \UART:BUART:sRX:RxSts\ | | SETUP | 0.500
Clock | | | | | Skew | 0.000

+ Hold Subsection

+ Source Clock : CyBUS_CLK : Positive edge

+ Destination Clock : UART_IntClock : Positive edge

Source | Destination | Slack (ns) | Violation
\RF_BT_SELECT:Sync:ctrl_reg\/control_0 | \UART:BUART:pollcount_1\/main_4 | 3.228

Type | Location | Fanout | Instance/Net | Source | Dest | Delay (ns)
controlcell1 | U(1,4) | 1 | \RF_BT_SELECT:Sync:ctrl_reg\ | \RF_BT_SELECT:Sync:ctrl_reg\/busclk | \RF_BT_SELECT:Sync:ctrl_reg\/control_0 | 0.620
Route | | 1 | Net_3437 | \RF_BT_SELECT:Sync:ctrl_reg\/control_0 | \UART:BUART:pollcount_1\/main_4 | 2.608
macrocell22 | U(1,4) | 1 | \UART:BUART:pollcount_1\ | | HOLD | 0.000
Clock | | | | | Skew | 0.000
\RF_BT_SELECT:Sync:ctrl_reg\/control_0 | \UART:BUART:rx_last\/main_0 | 3.228

Type | Location | Fanout | Instance/Net | Source | Dest | Delay (ns)
controlcell1 | U(1,4) | 1 | \RF_BT_SELECT:Sync:ctrl_reg\ | \RF_BT_SELECT:Sync:ctrl_reg\/busclk | \RF_BT_SELECT:Sync:ctrl_reg\/control_0 | 0.620
Route | | 1 | Net_3437 | \RF_BT_SELECT:Sync:ctrl_reg\/control_0 | \UART:BUART:rx_last\/main_0 | 2.608
macrocell25 | U(1,4) | 1 | \UART:BUART:rx_last\ | | HOLD | 0.000
Clock | | | | | Skew | 0.000
\RF_BT_SELECT:Sync:ctrl_reg\/control_0 | \UART:BUART:rx_state_2\/main_9 | 3.239

Type | Location | Fanout | Instance/Net | Source | Dest | Delay (ns)
controlcell1 | U(1,4) | 1 | \RF_BT_SELECT:Sync:ctrl_reg\ | \RF_BT_SELECT:Sync:ctrl_reg\/busclk | \RF_BT_SELECT:Sync:ctrl_reg\/control_0 | 0.620
Route | | 1 | Net_3437 | \RF_BT_SELECT:Sync:ctrl_reg\/control_0 | \UART:BUART:rx_state_2\/main_9 | 2.619
macrocell19 | U(1,4) | 1 | \UART:BUART:rx_state_2\ | | HOLD | 0.000
Clock | | | | | Skew | 0.000
Rx_1(0)_SYNC/out | \UART:BUART:rx_state_2\/main_10 | 3.777

Type | Location | Fanout | Instance/Net | Source | Dest | Delay (ns)
synccell | U(0,5) | 1 | Rx_1(0)_SYNC | Rx_1(0)_SYNC/clock | Rx_1(0)_SYNC/out | 0.350
Route | | 1 | Net_3438_SYNCOUT | Rx_1(0)_SYNC/out | \UART:BUART:rx_state_2\/main_10 | 3.427
macrocell19 | U(1,4) | 1 | \UART:BUART:rx_state_2\ | | HOLD | 0.000
Clock | | | | | Skew | 0.000
Rx_1(0)_SYNC/out | \UART:BUART:pollcount_1\/main_5 | 3.919

Type | Location | Fanout | Instance/Net | Source | Dest | Delay (ns)
synccell | U(0,5) | 1 | Rx_1(0)_SYNC | Rx_1(0)_SYNC/clock | Rx_1(0)_SYNC/out | 0.350
Route | | 1 | Net_3438_SYNCOUT | Rx_1(0)_SYNC/out | \UART:BUART:pollcount_1\/main_5 | 3.569
macrocell22 | U(1,4) | 1 | \UART:BUART:pollcount_1\ | | HOLD | 0.000
Clock | | | | | Skew | 0.000
Rx_1(0)_SYNC/out | \UART:BUART:rx_last\/main_1 | 3.919

Type | Location | Fanout | Instance/Net | Source | Dest | Delay (ns)
synccell | U(0,5) | 1 | Rx_1(0)_SYNC | Rx_1(0)_SYNC/clock | Rx_1(0)_SYNC/out | 0.350
Route | | 1 | Net_3438_SYNCOUT | Rx_1(0)_SYNC/out | \UART:BUART:rx_last\/main_1 | 3.569
macrocell25 | U(1,4) | 1 | \UART:BUART:rx_last\ | | HOLD | 0.000
Clock | | | | | Skew | 0.000
Rx_2(0)_SYNC/out | \UART:BUART:rx_state_2\/main_11 | 4.043

Type | Location | Fanout | Instance/Net | Source | Dest | Delay (ns)
synccell | U(0,4) | 1 | Rx_2(0)_SYNC | Rx_2(0)_SYNC/clock | Rx_2(0)_SYNC/out | 0.350
Route | | 1 | Net_3405_SYNCOUT | Rx_2(0)_SYNC/out | \UART:BUART:rx_state_2\/main_11 | 3.693
macrocell19 | U(1,4) | 1 | \UART:BUART:rx_state_2\ | | HOLD | 0.000
Clock | | | | | Skew | 0.000
\RF_BT_SELECT:Sync:ctrl_reg\/control_0 | \UART:BUART:pollcount_0\/main_3 | 4.153

Type | Location | Fanout | Instance/Net | Source | Dest | Delay (ns)
controlcell1 | U(1,4) | 1 | \RF_BT_SELECT:Sync:ctrl_reg\ | \RF_BT_SELECT:Sync:ctrl_reg\/busclk | \RF_BT_SELECT:Sync:ctrl_reg\/control_0 | 0.620
Route | | 1 | Net_3437 | \RF_BT_SELECT:Sync:ctrl_reg\/control_0 | \UART:BUART:pollcount_0\/main_3 | 3.533
macrocell23 | U(1,3) | 1 | \UART:BUART:pollcount_0\ | | HOLD | 0.000
Clock | | | | | Skew | 0.000
Rx_2(0)_SYNC/out | \UART:BUART:pollcount_1\/main_6 | 4.603

Type | Location | Fanout | Instance/Net | Source | Dest | Delay (ns)
synccell | U(0,4) | 1 | Rx_2(0)_SYNC | Rx_2(0)_SYNC/clock | Rx_2(0)_SYNC/out | 0.350
Route | | 1 | Net_3405_SYNCOUT | Rx_2(0)_SYNC/out | \UART:BUART:pollcount_1\/main_6 | 4.253
macrocell22 | U(1,4) | 1 | \UART:BUART:pollcount_1\ | | HOLD | 0.000
Clock | | | | | Skew | 0.000
Rx_2(0)_SYNC/out | \UART:BUART:rx_last\/main_2 | 4.603

Type | Location | Fanout | Instance/Net | Source | Dest | Delay (ns)
synccell | U(0,4) | 1 | Rx_2(0)_SYNC | Rx_2(0)_SYNC/clock | Rx_2(0)_SYNC/out | 0.350
Route | | 1 | Net_3405_SYNCOUT | Rx_2(0)_SYNC/out | \UART:BUART:rx_last\/main_2 | 4.253
macrocell25 | U(1,4) | 1 | \UART:BUART:rx_last\ | | HOLD | 0.000
Clock | | | | | Skew | 0.000

+ Source Clock : UART_IntClock : Positive edge

+ Destination Clock : UART_IntClock : Positive edge

Source | Destination | Slack (ns) | Violation
\UART:BUART:rx_status_3\/q | \UART:BUART:sRX:RxSts\/status_3 | 2.151

Type | Location | Fanout | Instance/Net | Source | Dest | Delay (ns)
macrocell24 | U(1,5) | 1 | \UART:BUART:rx_status_3\ | \UART:BUART:rx_status_3\/clock_0 | \UART:BUART:rx_status_3\/q | 1.250
Route | | 1 | \UART:BUART:rx_status_3\ | \UART:BUART:rx_status_3\/q | \UART:BUART:sRX:RxSts\/status_3 | 2.901
statusicell2 | U(1,4) | 1 | \UART:BUART:sRX:RxSts\ | | HOLD | -2.000
Clock | | | | | Skew | 0.000
\UART:BUART:sTX:sCLOCK:TxBitClkGen\/ce1_reg | \UART:BUART:tx_state_2\/main_4 | 2.785

Type | Location | Fanout | Instance/Net | Source | Dest | Delay (ns)
datapathcell2 | U(0,4) | 1 | \UART:BUART:sTX:sCLOCK:TxBitClkGen\ | \UART:BUART:sTX:sCLOCK:TxBitClkGen\/clock | \UART:BUART:sTX:sCLOCK:TxBitClkGen\/ce1_reg | 0.190
Route | | 1 | \UART:BUART:tx_counter_dp\ | \UART:BUART:sTX:sCLOCK:TxBitClkGen\/ce1_reg | \UART:BUART:tx_state_2\/main_4 | 2.595
macrocell13 | U(0,4) | 1 | \UART:BUART:tx_state_2\ | | HOLD | 0.000
Clock | | | | | Skew | 0.000
\UART:BUART:sTX:sCLOCK:TxBitClkGen\/ce1_reg | \UART:BUART:tx_state_1\/main_4 | 2.794

Type | Location | Fanout | Instance/Net | Source | Dest | Delay (ns)
datapathcell2 | U(0,4) | 1 | \UART:BUART:sTX:sCLOCK:TxBitClkGen\ | \UART:BUART:sTX:sCLOCK:TxBitClkGen\/clock | \UART:BUART:sTX:sCLOCK:TxBitClkGen\/ce1_reg | 0.190
Route | | 1 | \UART:BUART:tx_counter_dp\ | \UART:BUART:sTX:sCLOCK:TxBitClkGen\/ce1_reg | \UART:BUART:tx_state_1\/main_4 | 2.604
macrocell11 | U(0,4) | 1 | \UART:BUART:tx_state_1\ | | HOLD | 0.000
Clock | | | | | Skew | 0.000
\UART:BUART:sRX:RxBitCounter\/count_0 | \UART:BUART:rx_bitclk_enable\/main_2 | 2.946

Type | Location | Fanout | Instance/Net | Source | Dest | Delay (ns)
count7cell | U(1,5) | 1 | \UART:BUART:sRX:RxBitCounter\ | \UART:BUART:sRX:RxBitCounter\/clock | \UART:BUART:sRX:RxBitCounter\/count_0 | 0.620
Route | | 1 | \UART:BUART:rx_count_0\ | \UART:BUART:sRX:RxBitCounter\/count_0 | \UART:BUART:rx_bitclk_enable\/main_2 | 2.326
macrocell20 | U(1,5) | 1 | \UART:BUART:rx_bitclk_enable\ | | HOLD | 0.000
Clock | | | | | Skew | 0.000
\UART:BUART:sRX:RxBitCounter\/count_2 | \UART:BUART:rx_bitclk_enable\/main_0 | 3.253

Type | Location | Fanout | Instance/Net | Source | Dest | Delay (ns)
count7cell | U(1,5) | 1 | \UART:BUART:sRX:RxBitCounter\ | \UART:BUART:sRX:RxBitCounter\/clock | \UART:BUART:sRX:RxBitCounter\/count_2 | 0.620
Route | | 1 | \UART:BUART:rx_count_2\ | \UART:BUART:sRX:RxBitCounter\/count_2 | \UART:BUART:rx_bitclk_enable\/main_0 | 2.633
macrocell20 | U(1,5) | 1 | \UART:BUART:rx_bitclk_enable\ | | HOLD | 0.000
Clock | | | | | Skew | 0.000
\UART:BUART:sRX:RxBitCounter\/count_6 | \UART:BUART:rx_state_0\/main_6 | 3.253
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

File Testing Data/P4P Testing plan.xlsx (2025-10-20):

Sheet: Testing_schedule
Task | Status | Sheet | Notes
JFET | Blocked | Jfet data
Crystal - 16MHz | Completed | 16MHz Crystal data | These have multiple sensor types so each board has 8 sensors
Crystal - 8MHz | Not started | 8MHz Crystal data | These have multiple sensor types so each board has 8 sensors
ElectroInduction sensor - non shielded | Completed | ElectroInduction sensor
ElectroInduction sensor - shielded | Completed | Shielded ElectroInduction sensor data
Multi instrumentation amp | Not started | Multi Instrumentation Amp
Multi relaxation oscillator | Not started | Multi relaxation oscillator
25 ic - instrumentation amp | Completed | 25 ic data
Diode sensor | Blocked | Diode data
PSoC Cap sense - maybe | Not started

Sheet: JFET
JFET Sensor 1
10Hz | 15Hz | 25Hz | 60Hz | 100Hz | 150Hz | 200Hz | 250Hz | 275Hz | 300Hz

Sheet: JFET 2
JFET Sensor 2
10Hz | 15Hz | 25Hz | 60Hz | 100Hz | 150Hz | 200Hz | 250Hz | 275Hz | 300Hz

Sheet: JFET 3
JFET Sensor 3
10Hz | 15Hz | 25Hz | 60Hz | 100Hz | 150Hz | 200Hz | 250Hz | 275Hz | 300Hz
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

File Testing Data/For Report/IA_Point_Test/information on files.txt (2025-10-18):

58 - centre
61 - BL
62 - TL
63 - TR
64 - BR

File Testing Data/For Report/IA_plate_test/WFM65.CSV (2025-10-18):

in Sa | Frequency in Hz | Gain in dB | Phase in ° | Amplitude in Vpp
1.00E+00 | 1.000E+01 | -6.713E+01 | 7.570E+01 | 2.500E+00
2.00E+00 | 1.047E+01 | -6.669E+01 | 7.747E+01 | 2.500E+00
3.00E+00 | 1.096E+01 | -6.463E+01 | 7.659E+01 | 2.500E+00
4.00E+00 | 1.148E+01 | -6.436E+01 | 8.009E+01 | 2.500E+00
5.00E+00 | 1.202E+01 | -6.446E+01 | 8.825E+01 | 2.500E+00
6.00E+00 | 1.259E+01 | -6.448E+01 | 8.376E+01 | 2.500E+00
7.00E+00 | 1.318E+01 | -6.425E+01 | 7.795E+01 | 2.500E+00
8.00E+00 | 1.380E+01 | -6.355E+01 | 8.154E+01 | 2.500E+00
9.00E+00 | 1.445E+01 | -6.263E+01 | 8.088E+01 | 2.500E+00
1.00E+01 | 1.514E+01 | -6.283E+01 | 7.846E+01 | 2.500E+00
1.10E+01 | 1.585E+01 | -6.115E+01 | 8.236E+01 | 2.500E+00
1.20E+01 | 1.660E+01 | -6.160E+01 | 8.142E+01 | 2.500E+00
1.30E+01 | 1.738E+01 | -6.161E+01 | 7.720E+01 | 2.500E+00
1.40E+01 | 1.820E+01 | -6.144E+01 | 8.631E+01 | 2.500E+00
1.50E+01 | 1.905E+01 | -6.116E+01 | 8.575E+01 | 2.500E+00
1.60E+01 | 1.995E+01 | -6.033E+01 | 8.646E+01 | 2.500E+00
1.70E+01 | 2.089E+01 | -5.956E+01 | 8.378E+01 | 2.500E+00
1.80E+01 | 2.188E+01 | -6.010E+01 | 8.576E+01 | 2.500E+00
1.90E+01 | 2.291E+01 | -5.928E+01 | 8.850E+01 | 2.500E+00
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

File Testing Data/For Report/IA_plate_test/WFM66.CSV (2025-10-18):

in Sa | Frequency in Hz | Gain in dB | Phase in ° | Amplitude in Vpp
1.00E+00 | 1.000E+01 | -6.561E+01 | 8.197E+01 | 2.500E+00
2.00E+00 | 1.047E+01 | -6.444E+01 | 7.722E+01 | 2.500E+00
3.00E+00 | 1.096E+01 | -6.577E+01 | 8.101E+01 | 2.500E+00
4.00E+00 | 1.148E+01 | -6.408E+01 | 8.518E+01 | 2.500E+00
5.00E+00 | 1.202E+01 | -6.513E+01 | 9.032E+01 | 2.500E+00
6.00E+00 | 1.259E+01 | -6.321E+01 | 8.423E+01 | 2.500E+00
7.00E+00 | 1.318E+01 | -6.314E+01 | 8.962E+01 | 2.500E+00
8.00E+00 | 1.380E+01 | -6.436E+01 | 7.955E+01 | 2.500E+00
9.00E+00 | 1.445E+01 | -6.242E+01 | 8.394E+01 | 2.500E+00
1.00E+01 | 1.514E+01 | -6.299E+01 | 8.701E+01 | 2.500E+00
1.10E+01 | 1.585E+01 | -6.208E+01 | 8.360E+01 | 2.500E+00
1.20E+01 | 1.660E+01 | -6.129E+01 | 8.228E+01 | 2.500E+00
1.30E+01 | 1.738E+01 | -6.060E+01 | 8.857E+01 | 2.500E+00
1.40E+01 | 1.820E+01 | -6.091E+01 | 8.231E+01 | 2.500E+00
1.50E+01 | 1.905E+01 | -6.003E+01 | 8.518E+01 | 2.500E+00
1.60E+01 | 1.995E+01 | -6.003E+01 | 8.165E+01 | 2.500E+00
1.70E+01 | 2.089E+01 | -5.955E+01 | 8.348E+01 | 2.500E+00
1.80E+01 | 2.188E+01 | -5.952E+01 | 8.835E+01 | 2.500E+00
1.90E+01 | 2.291E+01 | -5.907E+01 | 8.655E+01 | 2.500E+00
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

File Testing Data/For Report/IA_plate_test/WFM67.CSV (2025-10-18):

in Sa | Frequency in Hz | Gain in dB | Phase in ° | Amplitude in Vpp
1.00E+00 | 1.000E+01 | -6.492E+01 | 8.191E+01 | 2.500E+00
2.00E+00 | 1.047E+01 | -6.418E+01 | 8.229E+01 | 2.500E+00
3.00E+00 | 1.096E+01 | -6.467E+01 | 8.604E+01 | 2.500E+00
4.00E+00 | 1.148E+01 | -6.378E+01 | 8.890E+01 | 2.500E+00
5.00E+00 | 1.202E+01 | -6.308E+01 | 8.542E+01 | 2.500E+00
6.00E+00 | 1.259E+01 | -6.368E+01 | 8.163E+01 | 2.500E+00
7.00E+00 | 1.318E+01 | -6.270E+01 | 8.798E+01 | 2.500E+00
8.00E+00 | 1.380E+01 | -6.262E+01 | 9.056E+01 | 2.500E+00
9.00E+00 | 1.445E+01 | -6.143E+01 | 8.299E+01 | 2.500E+00
1.00E+01 | 1.514E+01 | -6.152E+01 | 8.191E+01 | 2.500E+00
1.10E+01 | 1.585E+01 | -6.111E+01 | 8.681E+01 | 2.500E+00
1.20E+01 | 1.660E+01 | -6.029E+01 | 9.085E+01 | 2.500E+00
1.30E+01 | 1.738E+01 | -6.052E+01 | 8.049E+01 | 2.500E+00
1.40E+01 | 1.820E+01 | -6.009E+01 | 8.194E+01 | 2.500E+00
1.50E+01 | 1.905E+01 | -5.982E+01 | 8.713E+01 | 2.500E+00
1.60E+01 | 1.995E+01 | -5.936E+01 | 8.337E+01 | 2.500E+00
1.70E+01 | 2.089E+01 | -5.847E+01 | 9.321E+01 | 2.500E+00
1.80E+01 | 2.188E+01 | -5.862E+01 | 8.305E+01 | 2.500E+00
1.90E+01 | 2.291E+01 | -5.869E+01 | 8.750E+01 | 2.500E+00
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

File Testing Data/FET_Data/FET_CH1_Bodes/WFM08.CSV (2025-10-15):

in Sa | Frequency in Hz | Gain in dB | Phase in ° | Amplitude in Vpp
1.00E+00 | 1.000E+01 | -6.063E+01 | 1.740E+02 | 2.500E+00
2.00E+00 | 1.047E+01 | -6.039E+01 | 1.799E+02 | 2.500E+00
3.00E+00 | 1.096E+01 | -6.019E+01 | -1.795E+02 | 2.500E+00
4.00E+00 | 1.148E+01 | -6.030E+01 | -1.770E+02 | 2.500E+00
5.00E+00 | 1.202E+01 | -5.999E+01 | -1.792E+02 | 2.500E+00
6.00E+00 | 1.259E+01 | -6.138E+01 | 1.762E+02 | 2.500E+00
7.00E+00 | 1.318E+01 | -6.102E+01 | 1.758E+02 | 2.500E+00
8.00E+00 | 1.380E+01 | -6.112E+01 | 1.659E+02 | 2.500E+00
9.00E+00 | 1.445E+01 | -6.096E+01 | 1.629E+02 | 2.500E+00
1.00E+01 | 1.514E+01 | -6.213E+01 | -1.780E+02 | 2.500E+00
1.10E+01 | 1.585E+01 | -6.070E+01 | 1.667E+02 | 2.500E+00
1.20E+01 | 1.660E+01 | -6.093E+01 | 1.762E+02 | 2.500E+00
1.30E+01 | 1.738E+01 | -6.275E+01 | 1.760E+02 | 2.500E+00
1.40E+01 | 1.820E+01 | -6.241E+01 | 1.752E+02 | 2.500E+00
1.50E+01 | 1.905E+01 | -6.172E+01 | 1.627E+02 | 2.500E+00
1.60E+01 | 1.995E+01 | -6.292E+01 | 1.740E+02 | 2.500E+00
1.70E+01 | 2.089E+01 | -6.200E+01 | 1.756E+02 | 2.500E+00
1.80E+01 | 2.188E+01 | -6.266E+01 | 1.661E+02 | 2.500E+00
1.90E+01 | 2.291E+01 | -6.219E+01 | 1.681E+02 | 2.500E+00
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

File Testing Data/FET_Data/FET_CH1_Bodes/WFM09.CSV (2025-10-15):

in Sa | Frequency in Hz | Gain in dB | Phase in ° | Amplitude in Vpp
1.00E+00 | 1.000E+01 | -6.088E+01 | 1.662E+02 | 2.500E+00
2.00E+00 | 1.047E+01 | -6.052E+01 | 1.599E+02 | 2.500E+00
3.00E+00 | 1.096E+01 | -6.116E+01 | 1.610E+02 | 2.500E+00
4.00E+00 | 1.148E+01 | -5.997E+01 | 1.596E+02 | 2.500E+00
5.00E+00 | 1.202E+01 | -5.891E+01 | 1.659E+02 | 2.500E+00
6.00E+00 | 1.259E+01 | -6.093E+01 | 1.699E+02 | 2.500E+00
7.00E+00 | 1.318E+01 | -6.096E+01 | 1.607E+02 | 2.500E+00
8.00E+00 | 1.380E+01 | -6.046E+01 | 1.677E+02 | 2.500E+00
9.00E+00 | 1.445E+01 | -6.022E+01 | 1.617E+02 | 2.500E+00
1.00E+01 | 1.514E+01 | -6.130E+01 | 1.463E+02 | 2.500E+00
1.10E+01 | 1.585E+01 | -6.096E+01 | 1.532E+02 | 2.500E+00
1.20E+01 | 1.660E+01 | -6.153E+01 | 1.568E+02 | 2.500E+00
1.30E+01 | 1.738E+01 | -5.971E+01 | 1.550E+02 | 2.500E+00
1.40E+01 | 1.820E+01 | -6.015E+01 | 1.438E+02 | 2.500E+00
1.50E+01 | 1.905E+01 | -6.028E+01 | 1.421E+02 | 2.500E+00
1.60E+01 | 1.995E+01 | -6.173E+01 | 1.504E+02 | 2.500E+00
1.70E+01 | 2.089E+01 | -5.981E+01 | 1.376E+02 | 2.500E+00
1.80E+01 | 2.188E+01 | -6.181E+01 | 1.500E+02 | 2.500E+00
1.90E+01 | 2.291E+01 | -5.944E+01 | 1.464E+02 | 2.500E+00
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

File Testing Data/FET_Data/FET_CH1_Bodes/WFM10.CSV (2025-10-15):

in s | C1 in V
-2.50000E-04 | 2.25176E-01
-2.49996E-04 | 2.29277E-01
-2.49992E-04 | 2.28457E-01
-2.49988E-04 | 2.30098E-01
-2.49984E-04 | 2.34199E-01
-2.49980E-04 | 2.35020E-01
-2.49976E-04 | 2.33379E-01
-2.49972E-04 | 2.36660E-01
-2.49968E-04 | 2.37480E-01
-2.49964E-04 | 2.40762E-01
-2.49960E-04 | 2.39941E-01
-2.49956E-04 | 2.44043E-01
-2.49952E-04 | 2.44043E-01
-2.49948E-04 | 2.45684E-01
-2.49944E-04 | 2.46504E-01
-2.49940E-04 | 2.47324E-01
-2.49936E-04 | 2.46504E-01
-2.49932E-04 | 2.50605E-01
-2.49928E-04 | 2.51426E-01
-2.49924E-04 | 2.51426E-01
-2.49920E-04 | 2.50605E-01
-2.49916E-04 | 2.53887E-01
-2.49912E-04 | 2.53066E-01
-2.49908E-04 | 2.55527E-01
-2.49904E-04 | 2.57168E-01
-2.49900E-04 | 2.58809E-01
-2.49896E-04 | 2.58809E-01
-2.49892E-04 | 2.59629E-01
-2.49888E-04 | 2.62090E-01
-2.49884E-04 | 2.61270E-01
-2.49880E-04 | 2.62090E-01
-2.49876E-04 | 2.64551E-01
-2.49872E-04 | 2.67012E-01
-2.49868E-04 | 2.67012E-01
-2.49864E-04 | 2.67012E-01
-2.49860E-04 | 2.67832E-01
-2.49856E-04 | 2.70293E-01
-2.49852E-04 | 2.71934E-01
-2.49848E-04 | 2.71113E-01
-2.49844E-04 | 2.71934E-01
-2.49840E-04 | 2.74395E-01
-2.49836E-04 | 2.77676E-01
-2.49832E-04 | 2.75215E-01
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

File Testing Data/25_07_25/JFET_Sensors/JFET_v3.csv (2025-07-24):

x-axis | 1
second | Volt
-5.00000E-03 | +10.55156E-03
-4.99000E-03 | +12.34844E-03
-4.98000E-03 | +13.98906E-03
-4.97000E-03 | +15.47344E-03
-4.96000E-03 | +16.91875E-03
-4.95000E-03 | +18.32500E-03
-4.94000E-03 | +19.80937E-03
-4.93000E-03 | +21.05937E-03
-4.92000E-03 | +22.19219E-03
-4.91000E-03 | +23.32500E-03
-4.90000E-03 | +24.26250E-03
-4.89000E-03 | +25.16094E-03
-4.88000E-03 | +25.86406E-03
-4.87000E-03 | +26.56719E-03
-4.86000E-03 | +27.11406E-03
-4.85000E-03 | +27.46562E-03
-4.84000E-03 | +27.85625E-03
-4.83000E-03 | +28.01250E-03
-4.82000E-03 | +28.20781E-03
-4.81000E-03 | +27.97344E-03
-4.80000E-03 | +27.81719E-03
-4.79000E-03 | +27.34844E-03
-4.78000E-03 | +27.07500E-03
-4.77000E-03 | +26.52812E-03
-4.76000E-03 | +25.78594E-03
-4.75000E-03 | +24.96562E-03
-4.74000E-03 | +24.06719E-03
-4.73000E-03 | +23.20781E-03
-4.72000E-03 | +21.99687E-03
-4.71000E-03 | +20.82500E-03
-4.70000E-03 | +19.45781E-03
-4.69000E-03 | +18.16875E-03
-4.68000E-03 | +16.68437E-03
-4.67000E-03 | +15.08281E-03
-4.66000E-03 | +13.67656E-03
-4.65000E-03 | +12.03594E-03
-4.64000E-03 | +10.39531E-03
-4.63000E-03 | +8.48125E-03
-4.62000E-03 | +6.80156E-03
-4.61000E-03 | +4.92656E-03
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

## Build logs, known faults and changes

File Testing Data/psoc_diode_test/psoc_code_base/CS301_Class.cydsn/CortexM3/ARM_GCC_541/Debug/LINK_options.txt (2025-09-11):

-Wl,--start-group -o "C:\\Users\\jpat614\\Documents\\GitHub\\P4P_Project-130\\psoc_diode_test\\psoc_code_base\\CS301_Class.cydsn\\CortexM3\\ARM_GCC_541\\Debug\\CS301_Class.elf" ".\\CortexM3\\ARM_GCC_541\\Debug\\main.o" ".\\CortexM3\\ARM_GCC_541\\Debug\\tacho.o" ".\\CortexM3\\ARM_GCC_541\\Debug\\cyfitter_cfg.o" ".\\CortexM3\\ARM_GCC_541\\Debug\\cymetadata.o" ".\\CortexM3\\ARM_GCC_541\\Debug\\Cm3Start.o" ".\\CortexM3\\ARM_GCC_541\\Debug\\CS301_Class.a" "C:\\Program\ Files\ (x86)\\Cypress\\PSoC\ Creator\\4.2\\PSoC\ Creator\\psoc\\content\\cycomponentlibrary\\CyComponentLibrary.cylib\\CortexM3\\ARM_GCC_541\\Debug\\CyComponentLibrary.a" -mcpu=cortex-m3 -mthumb -L "Generated_Source\\PSoC5" "-Wl,-Map,.\\CortexM3\\ARM_GCC_541\\Debug/CS301_Class.map" -T "Generated_Source\\PSoC5\\cm3gcc.ld" -specs=nano.specs -Wl,--gc-sections -g -ffunction-sections -O0 -ffat-lto-objects -Wl,--end-group

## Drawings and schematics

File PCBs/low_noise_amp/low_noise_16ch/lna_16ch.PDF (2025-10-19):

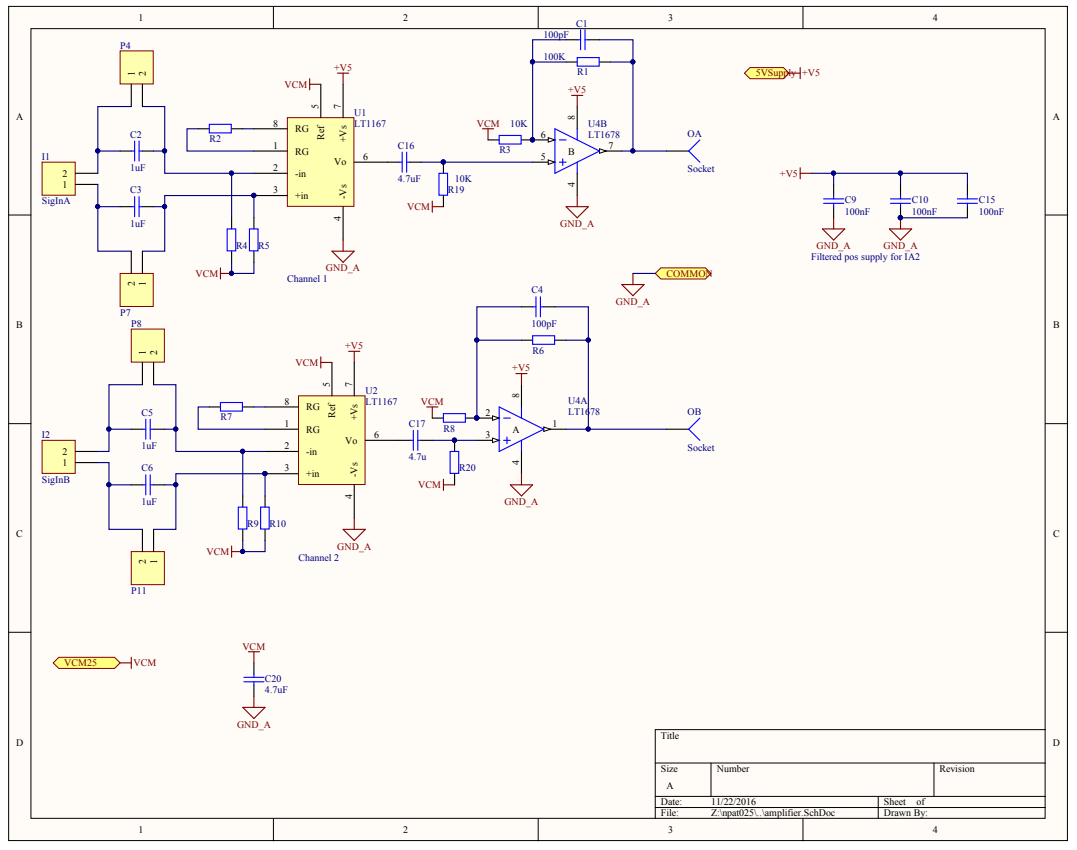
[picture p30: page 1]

Filtered pos supply for IA2

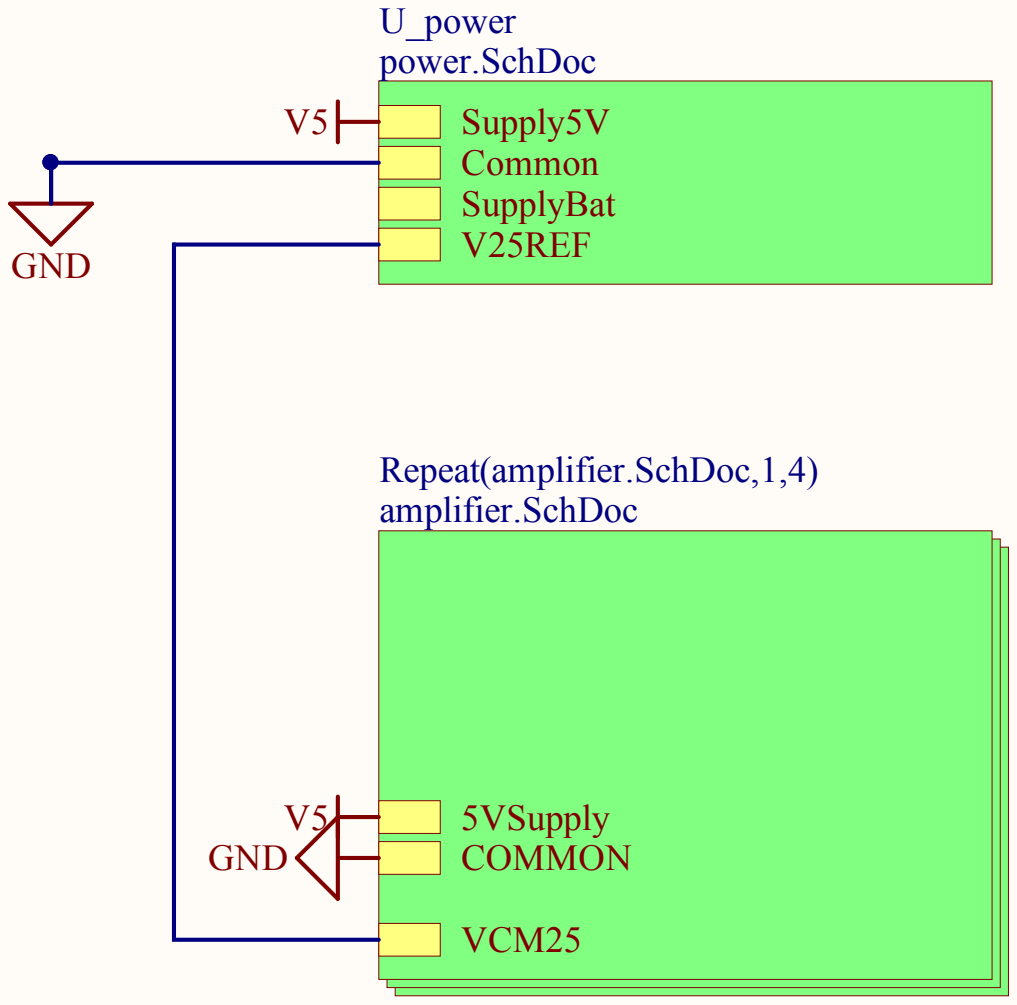
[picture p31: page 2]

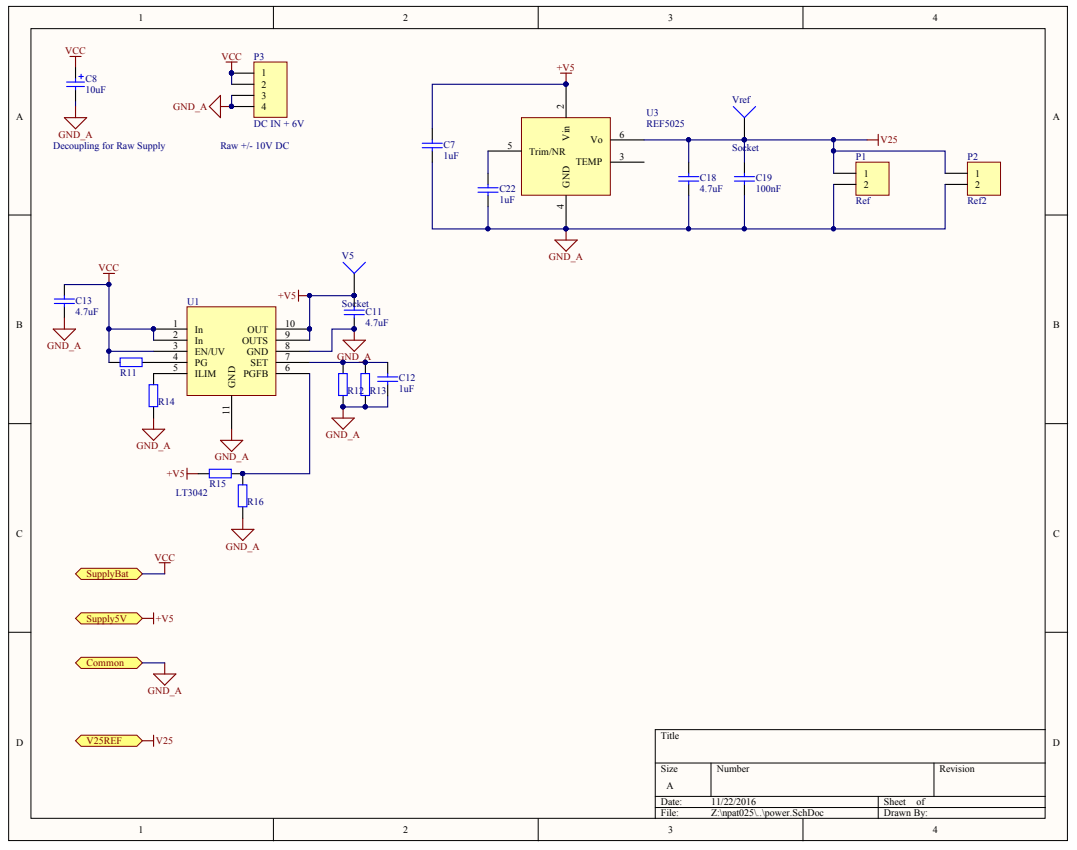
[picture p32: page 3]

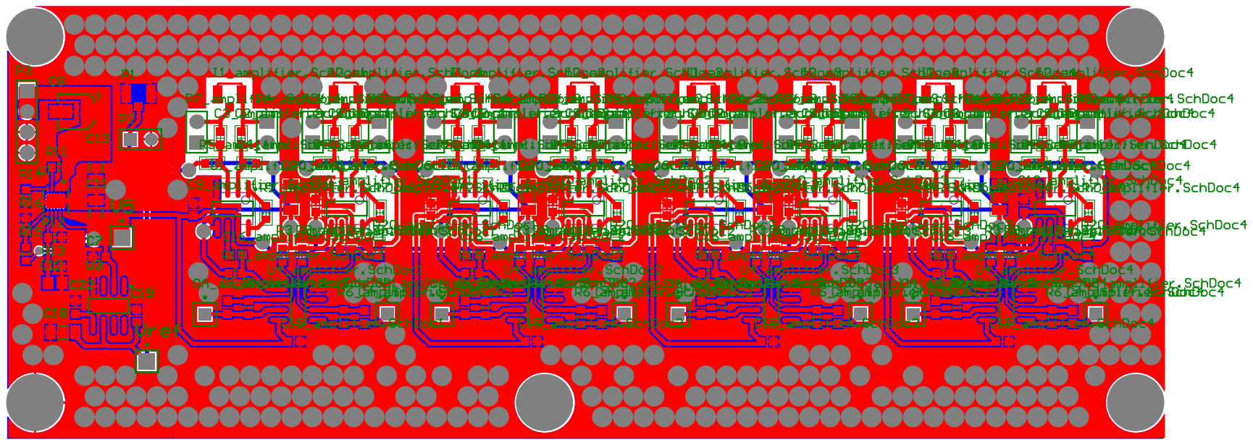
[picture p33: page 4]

# aoard S

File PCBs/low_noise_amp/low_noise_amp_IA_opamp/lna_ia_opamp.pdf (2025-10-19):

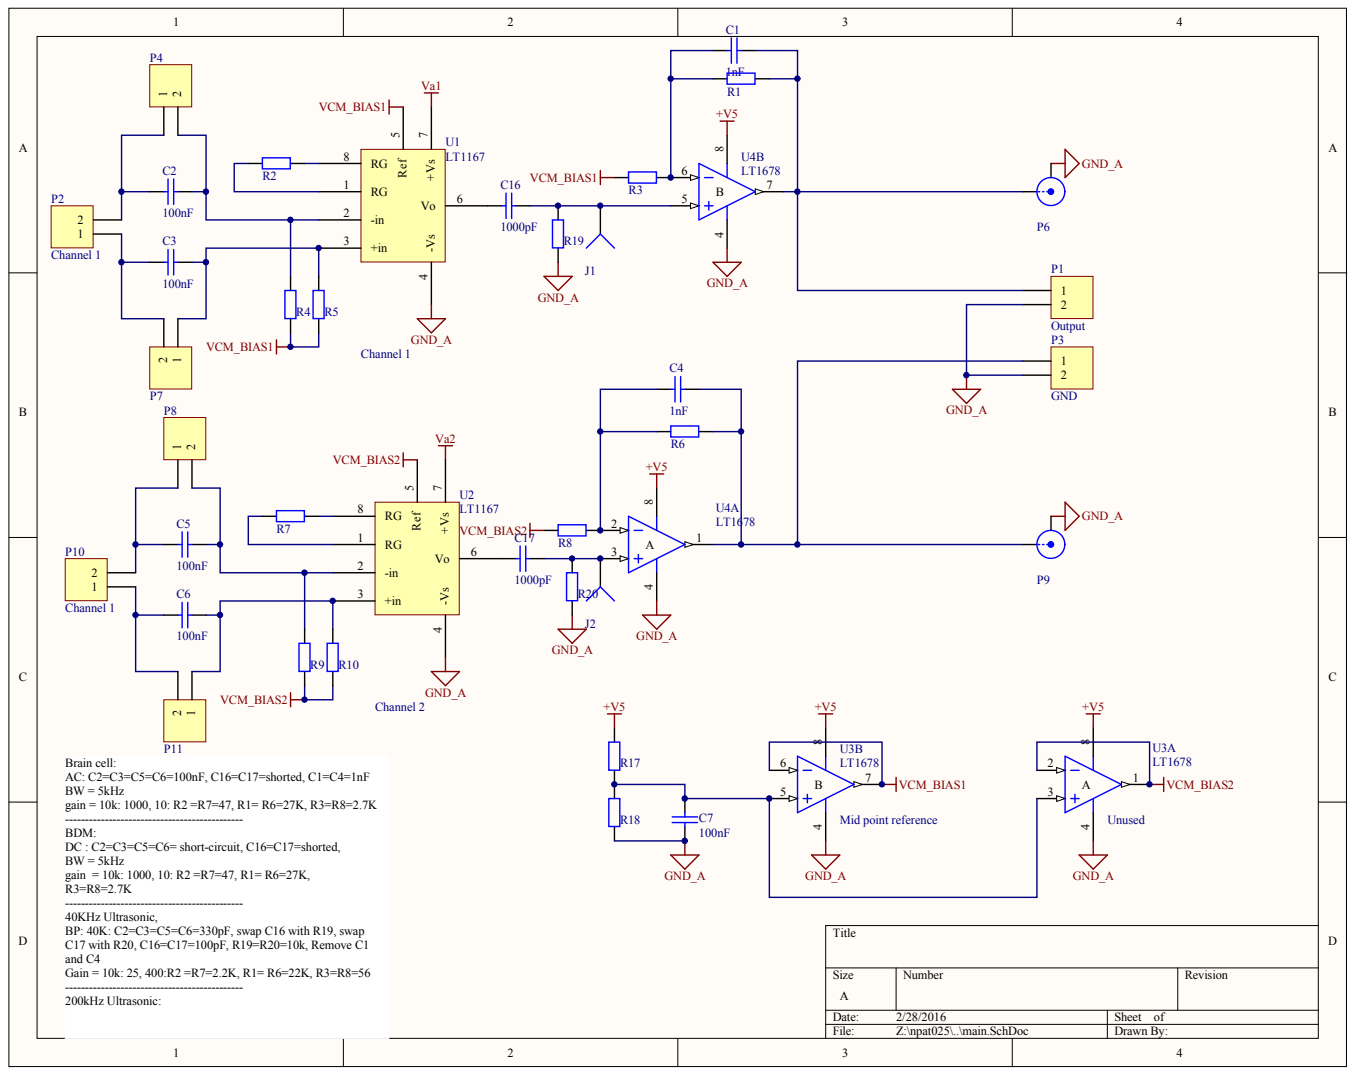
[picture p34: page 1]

BDM: DC : C2=C3=C5=C6= short-circuit, C16=C17=shorted

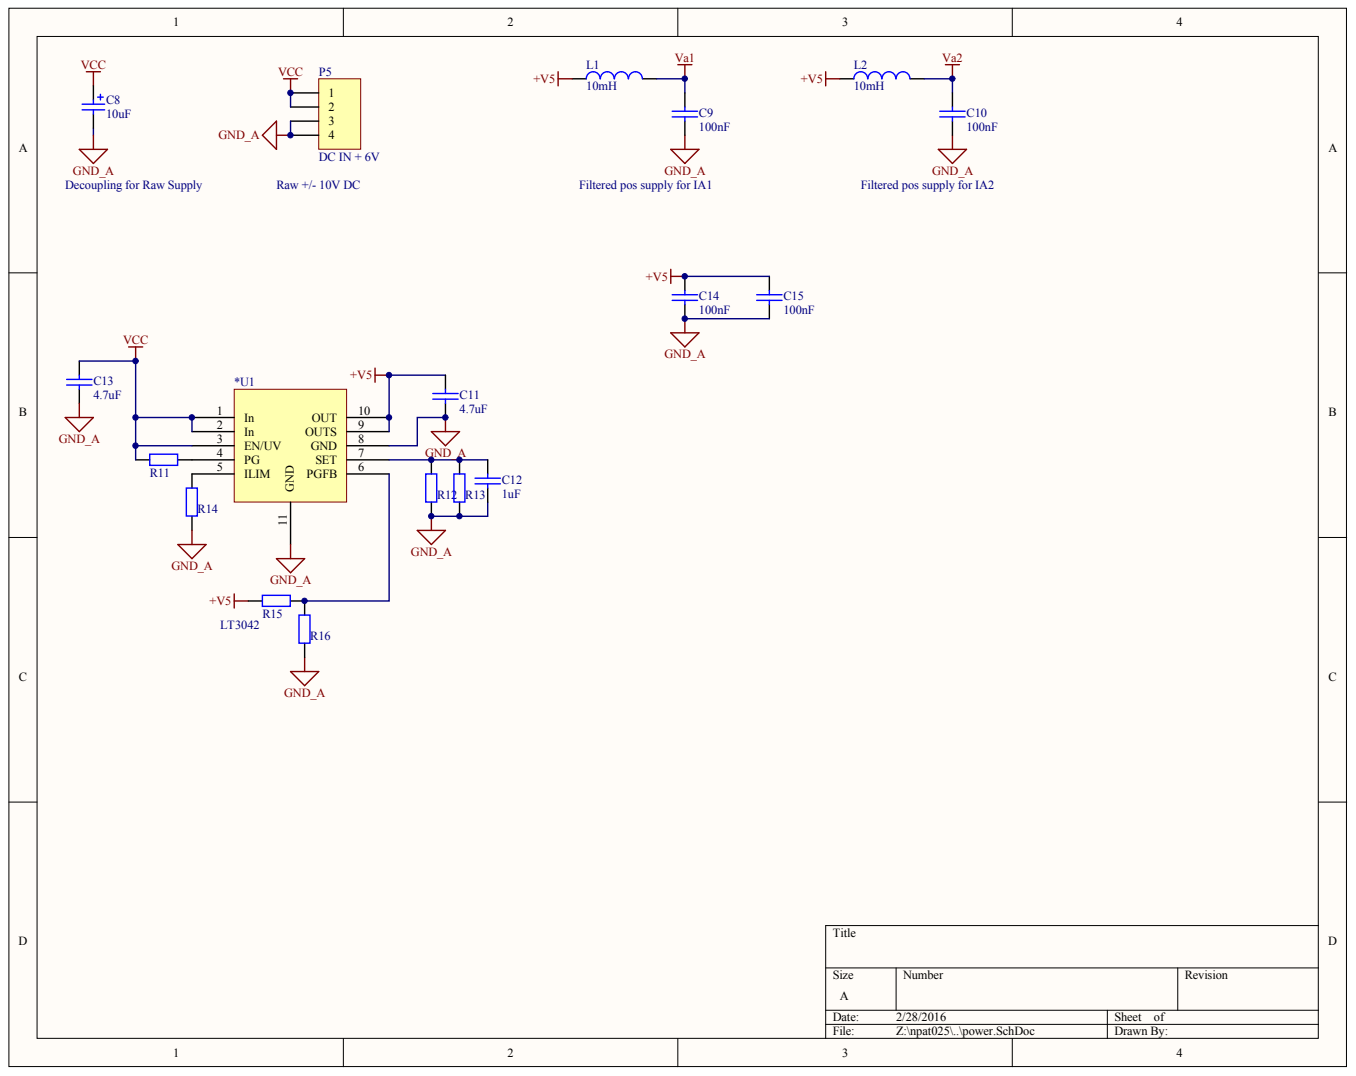
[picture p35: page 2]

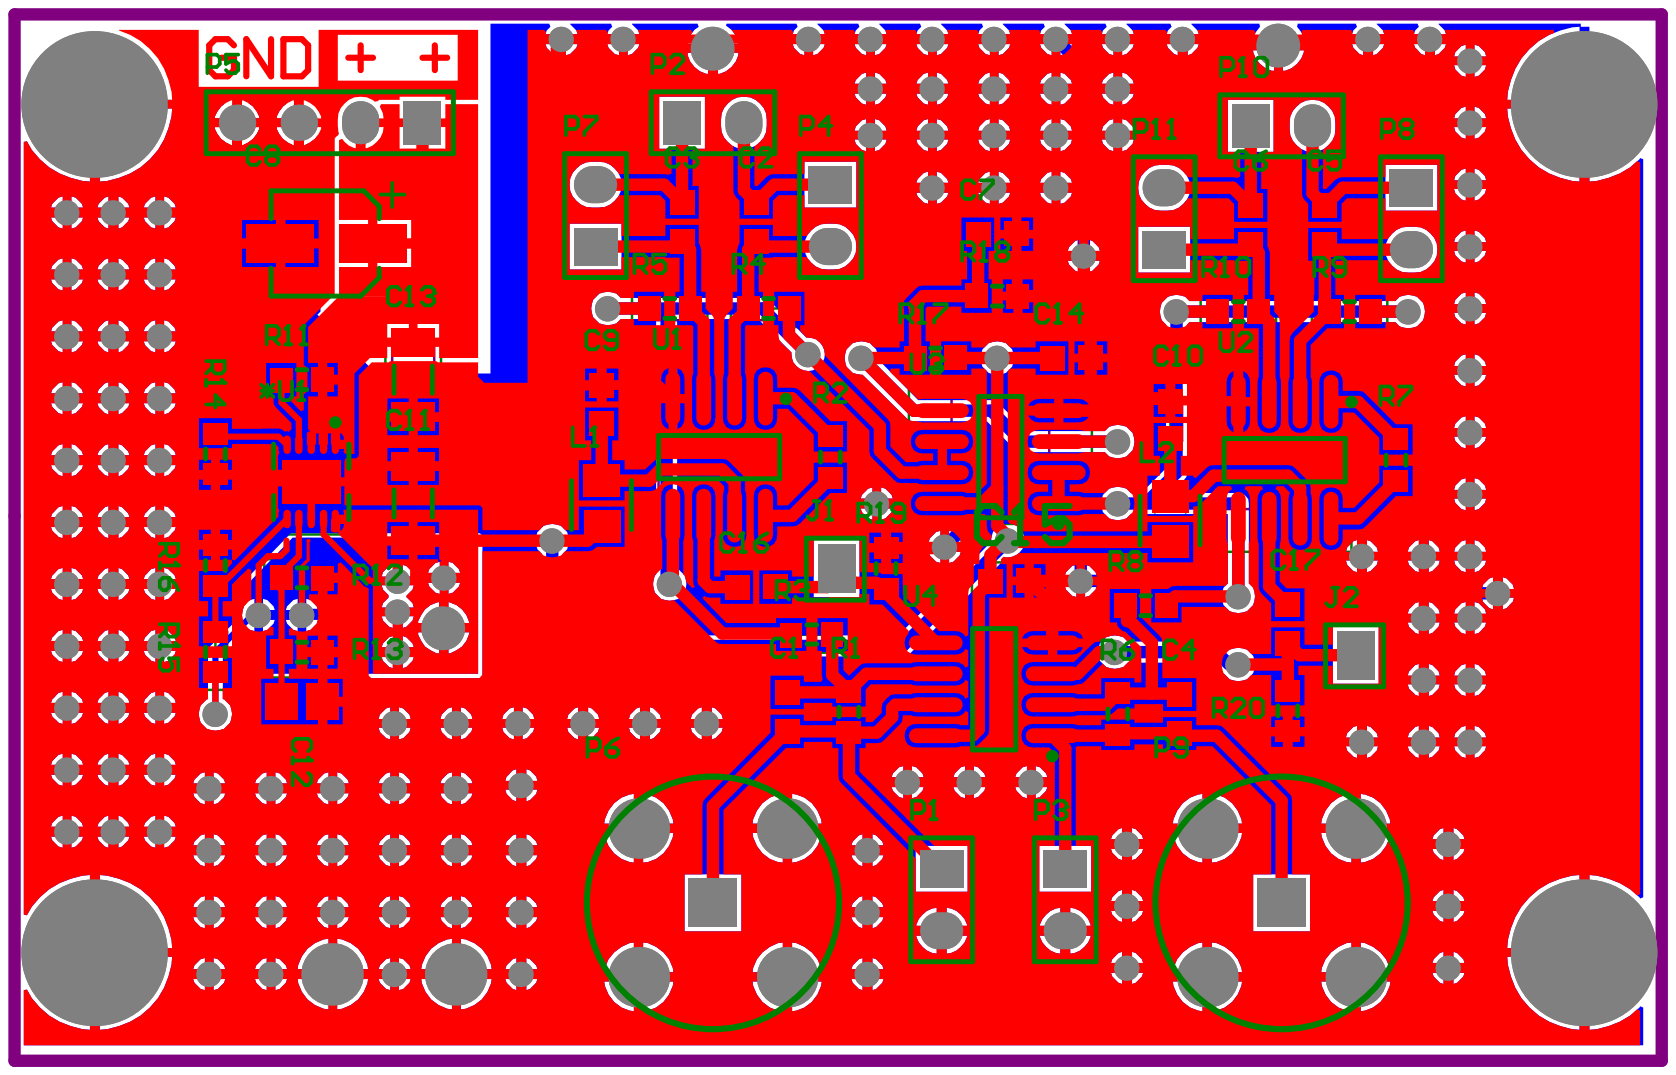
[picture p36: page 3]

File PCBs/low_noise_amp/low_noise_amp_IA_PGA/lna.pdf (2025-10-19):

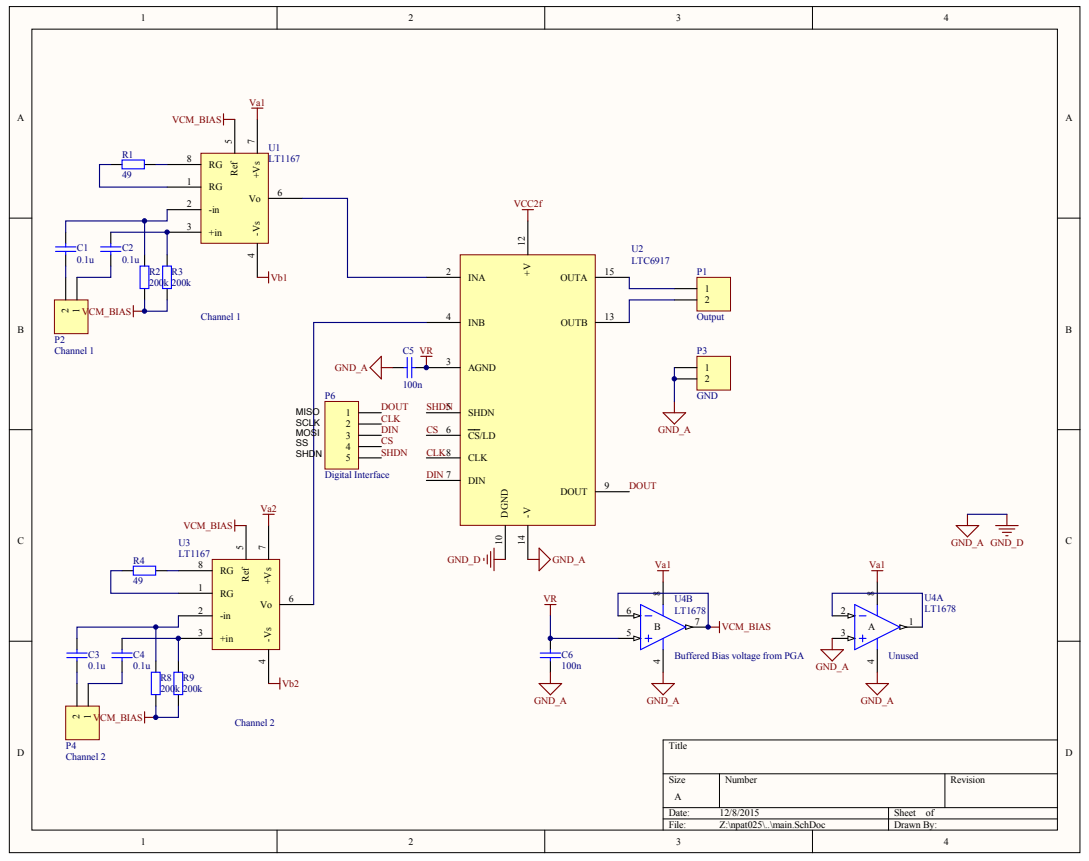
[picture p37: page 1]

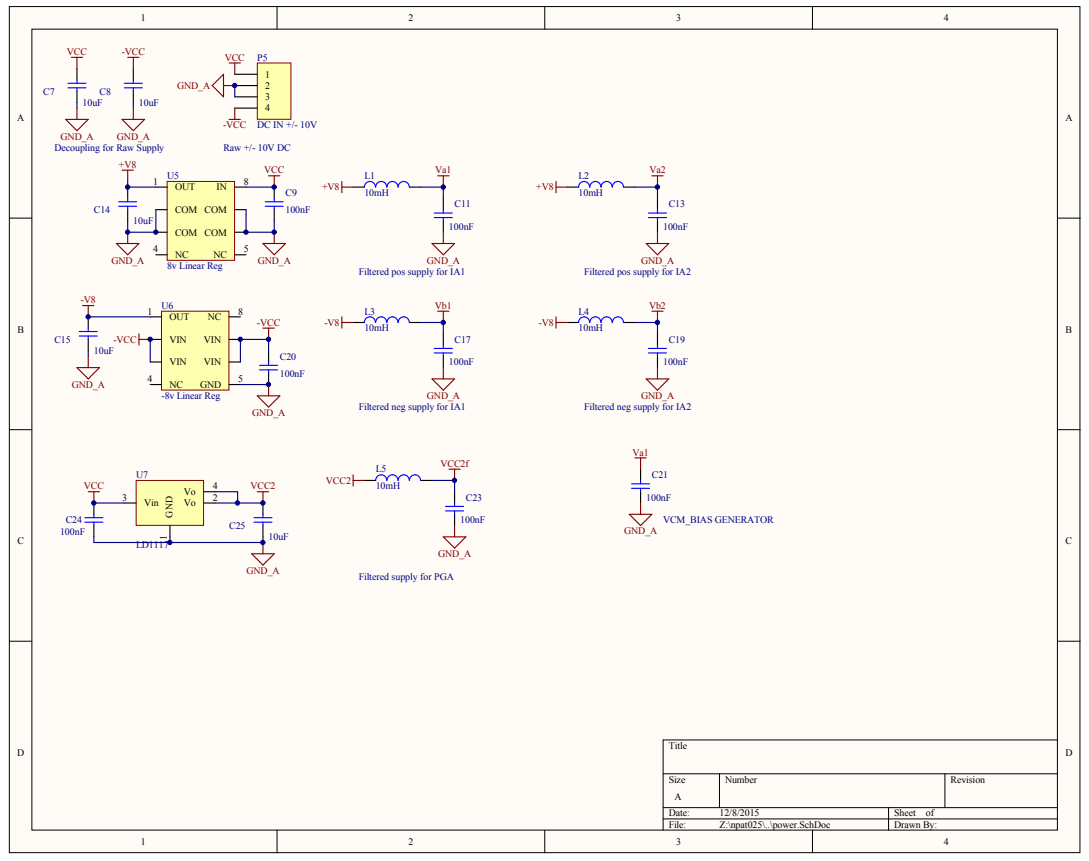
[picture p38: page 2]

Filtered pos supply for IA1

Filtered pos supply for IA2

Filtered neg supply for IA1

Filtered neg supply for IA2

Filtered supply for PGA

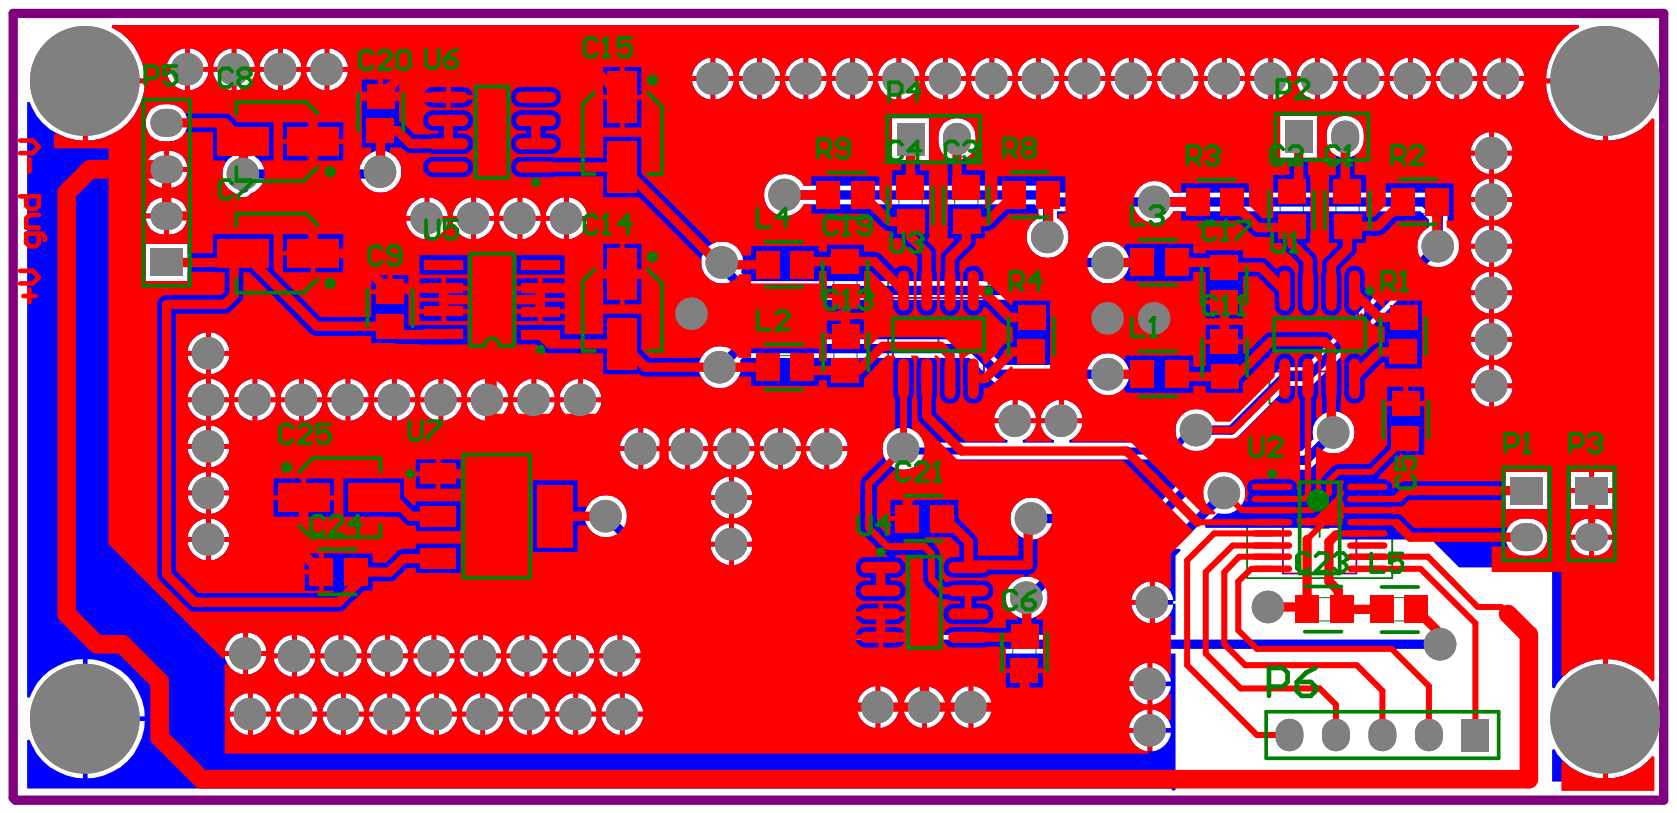
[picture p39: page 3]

Comment | Description | Designator | Footprint | LibRef | Quantity
0.1u | Capacitor | C1, C2, C3, C4 | CC2012-0805 | CAP | 4
100n | Capacitor | C5, C6 | CC2012-0805 | CAP | 2
Cap | Capacitor | C7, C8, C14, C15, C25 | ece-CAPAE43X54 | Cap | 5
Cap | Capacitor | C9, C11, C13, C17, C19, C20, C21, C23, C24 | CC2012-0805 | Cap | 9
Inductor | Inductor | L1, L2, L3, L4, L5 | CC2012-0805 | Inductor | 5
Output | Header, 2-Pin | P1 | HDR1X2 | Header 2 | 1
Channel 1 | Header, 2-Pin | P2 | HDR1X2 | Header 2 | 1
GND | Header, 2-Pin | P3 | HDR1X2 | Header 2 | 1
Channel 2 | Header, 2-Pin | P4 | HDR1X2 | Header 2 | 1
DC IN a/ - 10V | Header, 4-Pin | P5 | HDR1X4 | Header 4 | 1
Digital Interface | Header, 5-Pin | P6 | HDR1X5 | Header 5 | 1
49 | Resistor | R1, R4 | CR2012-0805 | Res2 | 2
200k | Resistor | R2, R3, R8, R9 | CR2012-0805 | Res2 | 4
LT1167 | Instrumentation amplifier, Low noise | U1, U3 | S8_N | LT1167 | 2
LTC6917 | Dual, PGA with serial interface | U2 | SSOP-GN | LTC6912 | 1
LT1678 | 45MHz, 45V/ µs, Dual Rail-to-Rail Input and Output Precision Operational Amplifier | U4 | S8_N | LT1632CS8 | 1
8v Linear Reg | | U5 | SO-8C | UA78L08 | 1
-8v Linear Reg | | U6 | S8_N | L79L08 | 1
LD1117 | LDO, 3.3/ 5 | U7 | ECE-SOT223 | LD1117D33 | 1

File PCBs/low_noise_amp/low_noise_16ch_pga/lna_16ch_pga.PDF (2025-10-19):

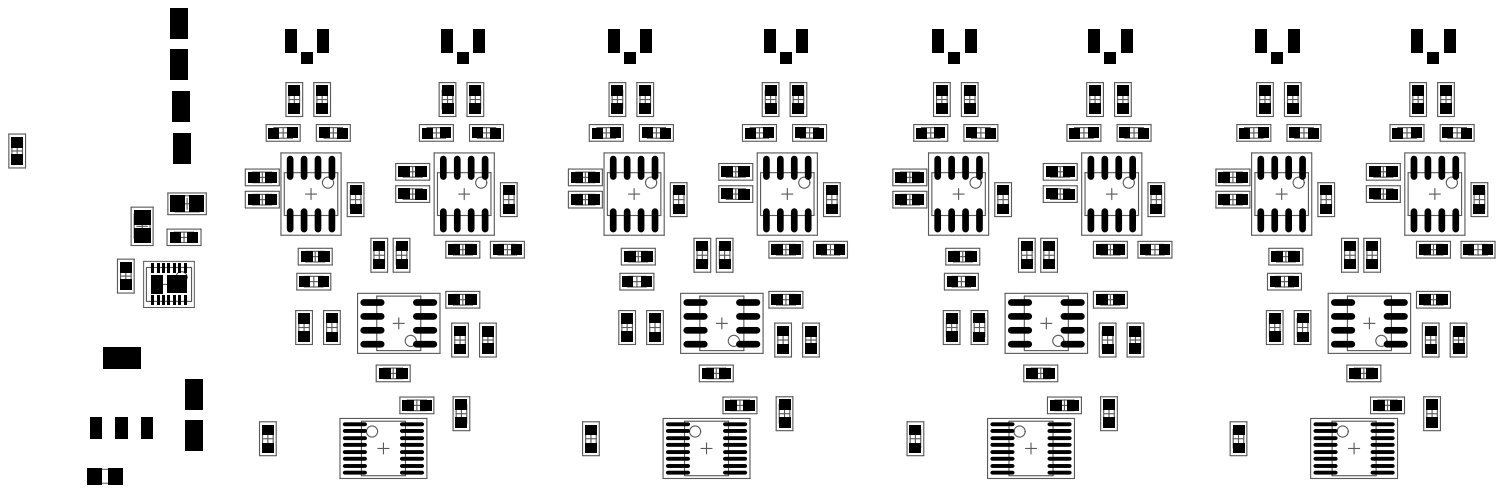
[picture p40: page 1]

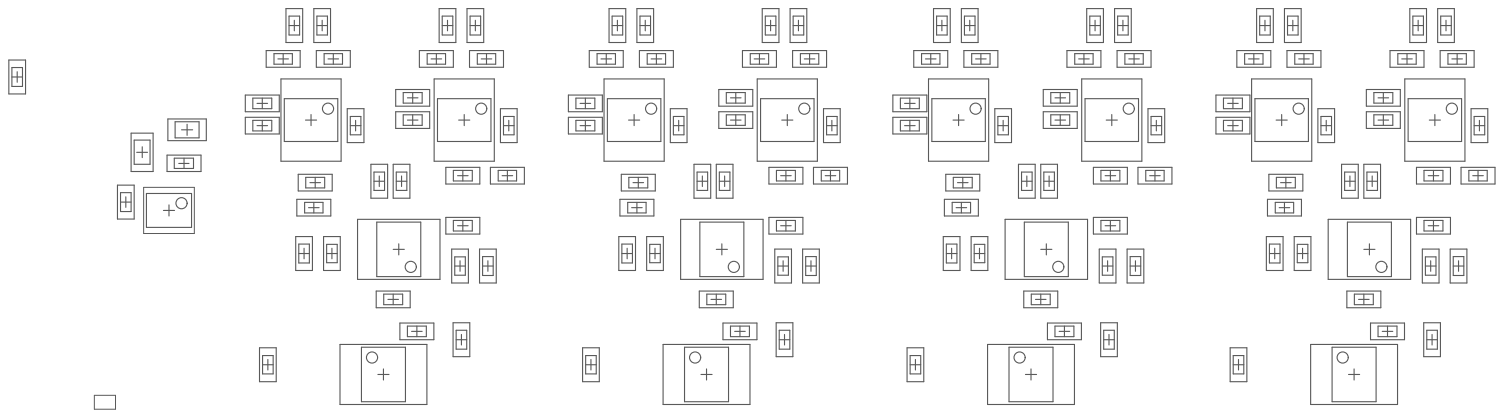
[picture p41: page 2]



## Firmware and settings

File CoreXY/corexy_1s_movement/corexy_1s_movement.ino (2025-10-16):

#include <Wire.h>
#include <Adafruit_PWMServoDriver.h>

Adafruit_PWMServoDriver pwm = Adafruit_PWMServoDriver();

#define SERVO_FREQ 50
#define SERVO_A 14
#define SERVO_B 15

#define SERVO_NEUTRAL 307
#define SERVO_FORWARD 440
#define SERVO_REVERSE 170

// move speed settings
#define MOVE_SPEED 70      // % of max speed
#define MOVE_DURATION 1000 // milliseconds (1 second)

void setup() {
  Serial.begin(9600);
  pwm.begin();
  pwm.setPWMFreq(SERVO_FREQ);
  delay(1000);
  Serial.println("CoreXY 1-second motion ready (w/a/s/d)");
}

void setServoSpeed(uint8_t servoNum, int speed) {
  speed = constrain(speed, -100, 100);
  int pulse;
  if (speed == 0) pulse = SERVO_NEUTRAL;
  else if (speed > 0)
    pulse = map(speed, 0, 100, SERVO_NEUTRAL, SERVO_FORWARD);
  else
    pulse = map(speed, -100, 0, SERVO_REVERSE, SERVO_NEUTRAL);
  pwm.setPWM(servoNum, 0, pulse);
}

void moveCoreXY(float dx, float dy) {
  // CoreXY transform
  int speedA = (dx + dy) * MOVE_SPEED;
  int speedB = (dx - dy) * MOVE_SPEED;

  setServoSpeed(SERVO_A, speedA);
  setServoSpeed(SERVO_B, speedB);

  delay(MOVE_DURATION);  // run for 1 second

  // stop servos
  setServoSpeed(SERVO_A, 0);
  setServoSpeed(SERVO_B, 0);
}

void loop() {
  if (Serial.available()) {
    char c = Serial.read();

    float dx = 0, dy = 0;
    if (c == 'w') dy = +1;     // up
    if (c == 's') dy = -1;     // down
    if (c == 'a') dx = -1;     // left
    if (c == 'd') dx = +1;     // right

    if (dx != 0 || dy != 0) {
      Serial.print("Move ");
      if (c == 'w') Serial.println("UP");
      if (c == 's') Serial.println("DOWN");
      if (c == 'a') Serial.println("LEFT");
      if (c == 'd') Serial.println("RIGHT");

      moveCoreXY(dx, dy);
    }
  }
}

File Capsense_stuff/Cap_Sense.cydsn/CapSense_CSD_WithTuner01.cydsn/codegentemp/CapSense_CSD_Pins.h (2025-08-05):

/*******************************************************************************
* File Name: CapSense_CSD_Pins.h
* Version 3.50
*
* Description:
*  This file contains API to enable firmware control of a Pins component.
*
* Note:
*  None
*
********************************************************************************
* Copyright 2008-2013, Cypress Semiconductor Corporation.  All rights reserved.
* You may use this file only in accordance with the license, terms, conditions,
* disclaimers, and limitations in the end user license agreement accompanying
* the software package with which this file was provided.
*******************************************************************************/

#if !defined(CY_CAPSENSE_CSD_Pins_CapSense_CSD_H)
#define CY_CAPSENSE_CSD_Pins_CapSense_CSD_H

#include "cytypes.h"
#include "cyfitter.h"
#include "cypins.h"
#include "CapSense_CSD.h"


/***************************************
*        Function Prototypes
***************************************/

void CapSense_CSD_SetAllSensorsDriveMode(uint8 mode) ;
void CapSense_CSD_SetAllCmodsDriveMode(uint8 mode) ;
#if (CapSense_CSD_CURRENT_SOURCE == CapSense_CSD_EXTERNAL_RB)
    void CapSense_CSD_SetAllRbsDriveMode(uint8 mode) ;    
#endif  /* (CapSense_CSD_CURRENT_SOURCE == CapSense_CSD_EXTERNAL_RB) */   


/***************************************
*           API Constants        
***************************************/

/* Drive Modes */
#define CapSense_CSD_DM_ALG_HIZ         (PIN_DM_ALG_HIZ)
#define CapSense_CSD_DM_DIG_HIZ         (PIN_DM_DIG_HIZ)
#define CapSense_CSD_DM_RES_UP          (PIN_DM_RES_UP)
#define CapSense_CSD_DM_RES_DWN         (PIN_DM_RES_DWN)
#define CapSense_CSD_DM_OD_LO           (PIN_DM_OD_LO)
#define CapSense_CSD_DM_OD_HI           (PIN_DM_OD_HI)
#define CapSense_CSD_DM_STRONG          (PIN_DM_STRONG)
#define CapSense_CSD_DM_RES_UPDWN       (PIN_DM_RES_UPDWN)

/* PC registers defines for sensors */
#define CapSense_CSD_PortCH0__Button0__BTN  CapSense_CSD_PortCH0__Button0__BTN__PC
#define CapSense_CSD_PortCH0__ProximitySensor0_0__PROX  CapSense_CSD_PortCH0__ProximitySensor0_0__PROX__PC
/* For Cmods*/
#define CapSense_CSD_CmodCH0_Cmod_CH0       CapSense_CSD_CmodCH0__Cmod_CH0__PC


#endif /* (CY_CAPSENSE_CSD_Pins_CapSense_CSD_H) */


/* [] END OF FILE */

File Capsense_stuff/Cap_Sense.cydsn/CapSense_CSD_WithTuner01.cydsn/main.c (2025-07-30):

/*******************************************************************************
* File Name: main.c
*
* Version: 1.10
*
* Description:
*  The project explains the usage of CapSense CSD component. The 2 buttons and
*  linear sliders are used as sensing elements. Tuner GUI displays buttons 
*  active state and slider position. The defualt parameters of component could 
*  be changed by using Tuner GUI. For more information about Tuner GUI please 
*  refer to CapSense CSD data sheet.
*  The EzI2C component is used to establish communication with Tuner GUI.
*
*  Steps to lanch and use Tunner:
*   1) Select "Launch Tuner" from a CapSense CSD instance context menu to
*      launch the Tuning GUI.
*   2) Open the Configuration Communication dialog and set the communication
*      parameters.
*   3) Press Start on the Tuning GUI. All of the CapSense elements will start
*      showing their values.
*
* Hardware connections:
*  CY8CKIT-001 and MiniProg3 GND should be connected.
*  EzI2C Slave SDA - P12[1] to SDAT on MiniProg3.
*  EzI2C Slave SCL - P12[0] to SCLK on MiniProg3.
*  No connection is required for the modulator capacitor Cmod (P2[7] on
*  CY8C38 Family Processor Module CY8CKIT-009).
*  NOTE: To use this project with CY8C55 Family Processor Module CY8CKIT-010
*        reassign the Cmod to P15[5].
*
********************************************************************************
* Copyright 2012, Cypress Semiconductor Corporation. All rights reserved.
* This software is owned by Cypress Semiconductor Corporation and is protected
* by and subject to worldwide patent and copyright laws and treaties.
* Therefore, you may use this software only as provided in the license agreement
* accompanying the software package from which you obtained this software.
* CYPRESS AND ITS SUPPLIERS MAKE NO WARRANTY OF ANY KIND, EXPRESS OR IMPLIED,
* WITH REGARD TO THIS SOFTWARE, INCLUDING, BUT NOT LIMITED TO, NONINFRINGEMENT,
* IMPLIED WARRANTIES OF MERCHANTABILITY AND FITNESS FOR A PARTICULAR PURPOSE.
*******************************************************************************/

#include <project.h>


/*******************************************************************************
* Function Name: main
********************************************************************************
*
* Summary:
*  Main function performs following functions:
*   1. Enable global interrupts.
*   2. Initialize CapSense CSD and EzI2C Start the sensor scanning loop.
*   3. Process scanning results and communicates with Tuner GUI.
*
* Parameters:
*  None
*
* Return:
*  None
*
*******************************************************************************/
int main()
{
    /* Enable global interrupts */
    CyGlobalIntEnable;

    /* Initialize CapSense CSD and EzI2C Start the sensor scanning loop */
    CapSense_CSD_TunerStart();

    PWM_1_Start();
    
    while(1u)
    {
        /* Process scanning results and communicates with Tuner GUI */
        CapSense_CSD_TunerComm();
        
     
    }
}


/* [] END OF FILE */

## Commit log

2025-03-29 Just some voltage multipliers
2025-05-10 experimental method
    [Design01_Copy_01.sdf]
2025-05-11 psoc schmitt tigger circuit
    [Design01.sdf, Design01_Copy_01.sdf]
2025-05-19 second version of cap sense
    [Design01.sdf, Design01_Copy_01.sdf]
2025-07-01 experimental cap sensor
    [Design01_Copy_01.sdf, Design01_Copy_01_Copy_01.sdf, bts_schmitt.sdf]
2025-07-10 we on CST SSSSSSSSSSOOOOOOOOOOOOOOONNNNNNNNNNNNNNN!!!!!!!!!!!!!!!!!!
    [Model.dsn]
2025-07-10 now applying a charge to the sensor
    [Model.dsn]
2025-07-21 Laser cutting testing rig
2025-07-24 electret data
    [electret1.csv, electret2.csv, electret3.csv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]
2025-07-24 Ways to look at the old sensor outputs
2025-07-24 jfet sensor data
    [JFET_v2.csv, JFET_v3.csv]
2025-07-30 playing around with the capsense stuff
    [CapSense_CSD_WithTuner01.sdf, Cap_Sense.sdf]
2025-07-30 Inductor sensor PCB
    [Inductor_sensor.PrjPcb, Sheet1.SchDoc, sensor.PcbLib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]
2025-07-30 Schematic donezo!!!
    [Sheet1.SchDoc]
2025-07-30 Some more PCB stuff
    [Estatic_Induction_Sensor_array_PCB.PcbDoc, Sheet1.SchDoc, sensor.PcbLib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]
2025-07-30 Parking the PCB stuff
    [Estatic_Induction_Sensor_array_PCB.PcbDoc, PCB1.PcbDoc, Sheet1.SchDoc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]
2025-07-31 Sensor donezo
    [PCB1.PcbDoc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]
2025-08-04 some cap sense stuff
    [CapSense_CSD_WithTuner01.sdf]
2025-08-05 capsensing module/widget change thingy
    [CapSense_CSD_WithTuner01.sdf]
2025-08-06 capsense stuff using syncing
    [CapSense_CSD_WithTuner01.sdf]
2025-08-06 ok so I think I cooked but in the opposite way - looks like a 50hz signal that is being picked up
    [CapSense_CSD_WithTuner01.sdf]
2025-08-20 some pcb stuff and psoc stuff
    [CapSense_CSD_WithTuner01.sdf, Crystal_cct.PrjPcb, schematic_crystal.SchDoc]
2025-08-20 pcb stuff
    [Crystal_cct.PrjPcb, Crystal_cct.SCHLIB, Inductor_sensor.PrjPcb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]
2025-08-21 PCB PCB PCB PCB
    [crystal_pcb.PcbDoc, schematic_crystal.SchDoc]
2025-08-21 ok we going!!!!
    [crystal_pcb.PcbDoc, schematic_crystal.SchDoc]
2025-08-21 ADDED GROUND PLANE
    [crystal_pcb.PcbDoc]
2025-08-22 some altium changes
    [Crystal_cct.PrjPcb, crystal_pcb.PcbDoc]
2025-09-08 psoc and altium
    [Aron_didnt_break_this_one.PcbDoc, Crystal_cct.PrjPcb, crystal_pcb.PcbDoc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]
2025-09-08 PCB LAYOUT DONE?!?!?!?
    [Aron_didnt_break_this_one.PcbDoc]
2025-09-08 PCB DONEZO
    [Aron_didnt_break_this_one.PcbDoc, schematic_crystal.SchDoc]
2025-09-08 ALL DONE
    [Aron_didnt_break_this_one.PcbDoc]
2025-09-09 PCB done and submitted
    [Aron_didnt_break_this_one.GBL, Aron_didnt_break_this_one.GBO, Aron_didnt_break_this_one.GBP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]
2025-09-11 psoc diode code
    [CS301_Class.sdf]
2025-09-11 matlab code to plot psoc adc vals
    [CS301_Class.sdf]
2025-09-11 update, try with different comp
    [CS301_Class.sdf]
2025-09-11 low range sweep idac
    [CS301_Class.sdf]
2025-09-12 diode figs
    [CS301_Class.sdf]
2025-09-23 live diode difference graph
    [Design01_Copy_01.sdf]
2025-09-28 added the data for the 16MHz crystal
    [cry2_10.csv, cry2_100.csv, cry2_1000.csv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]
2025-10-14 added the IA pcbs
    [doneIThink-B_Cu.gbr, doneIThink-B_Mask.gbr, doneIThink-B_Paste.gbr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]
2025-10-14 Added the multi board pcb
    [esfgrid_ckt_Multi-B_Cu.gbr, esfgrid_ckt_Multi-B_Mask.gbr, esfgrid_ckt_Multi-B_Paste.gbr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]
2025-10-14 matlab plots and sensor data
    [300Hz.csv, CH1-10M.CSV, CH1.CSV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]
2025-10-14 15hz electret sensor data
    [15Hz.csv]
2025-10-15 Raw data cleanup
    Added data for FET CH1
    [10meg_comparison sheet.xlsx, JFET_v2.csv, JFET_v3.csv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]
2025-10-15 channel 2 fets
    [WFM08.CSV, WFM09.CSV, WFM10.CSV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]
2025-10-15 report data
    [WFM01.CSV, WFM02.CSV, WFM03.CSV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]
2025-10-17 beespy electret and jfet test raw data
    note beetest_5 and beetest_6 are the ones of interest. beetest_4 the power supply wasn't turned on :((
2025-10-17 graphs for report
    [beetest_5_out.csv, beetest_6_out.csv]
2025-10-18 25 IA sensor data
    [WFM03.CSV, WFM04.CSV, WFM05.CSV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]
2025-10-18 beehive IA test
    [WFM55.CSV, WFM56.CSV, WFM57.CSV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]
2025-10-18 updated data
    [10meg_comparison sheet.xlsx, CS301_Class.sdf, JFET_v2.csv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]
2025-10-18 plate test up
    [WFM65.CSV, WFM66.CSV, WFM67.CSV]
2025-10-19 updated graphs
    [WFM01.CSV, WFM03.CSV, WFM05.CSV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]
2025-10-19 adding Nitish's files
    [Model.dsn, amplifier.CSV, amplifier.SchDoc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]
2025-10-19 Added the CAD files for the Corexy
    [GT2 Timing Pulley 20T 10mm - Bore_5mm v8.f3d, core xy v77.f3d]
2025-10-20 updated github and folders
    [10meg_comparison sheet.xlsx, 15Hz.csv, 300Hz.csv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]
